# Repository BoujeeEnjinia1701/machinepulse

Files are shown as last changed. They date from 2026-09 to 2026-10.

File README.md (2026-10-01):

# MachinePulse

     

**Area:** Automation · **TRL:** 3 of 9 (proof of concept on paper) · **Value-engineering target:** USD 81 (estimated cost USD 83.50) · **Difficulty:** 2 of 5

A clip-on monitor for older machines: current clamp, vibration and temperature sensors report run time, load and early fault signs from lathes, pumps and compressors that have no electronics of their own.

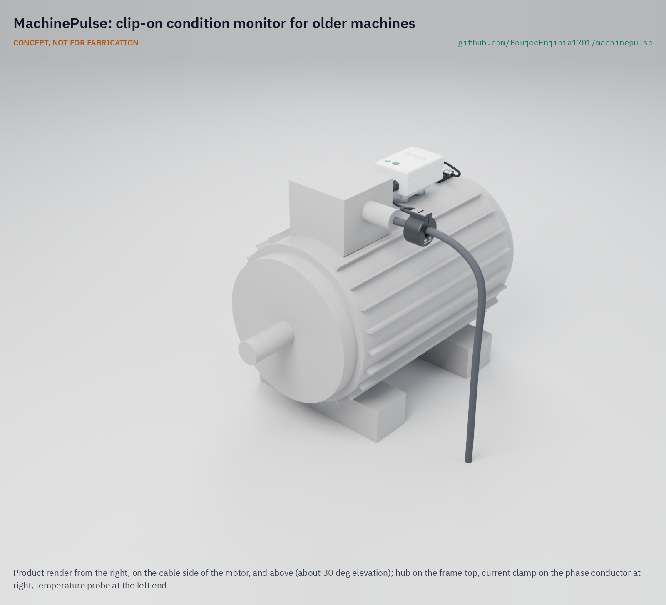
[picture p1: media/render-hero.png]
MachinePulse: clip-on condition monitor for older machines, product render


[Exploded render](media/render-exploded.png) · [Detail render](media/render-detail.png) · [Interactive 3D model](media/viewer.html) · [Concept blueprint (PDF)](media/concept-blueprint.pdf) · [General arrangement MPL-DWG-001 (PDF)](cad/drawings/MPL-DWG-001.pdf) · [Calculations MPL-CAL-001](docs/04-calcs/01-sizing.md) · [Prototype build plan](docs/05-build-plan.md) · [Design decisions](docs/06-design-decisions.md) · [Review note](docs/REVIEW.md)

## Concept rationale

Retrofitting is how most of the world's machines will ever become connected. A lathe, pump or compressor that has run for 30 years can run for many more, but it has no sensors and no controller to read. MachinePulse adds the three measurements that say most about an induction-motor-driven machine: current (is it running, and how hard), vibration (is anything loosening or wearing) and frame temperature (is it working harder than it should). It compares each machine with its own first week of running rather than with fixed alarm levels, because old machines differ too much for generic limits.

It is open and garage-buildable because the owners who most need it run small shops without a maintenance engineer or a budget for vendor platforms. Every part is a stock module, a stock box or a block of aluminium cut with hand tools, the pod never touches the machine's wiring or controls, and the data goes to the lab's TwinKit gateway or any MQTT broker on the shop network, so an owner can inspect and change every step.

## Burning platform

Unplanned stops are expensive, and reactive maintenance makes them more likely. A NIST study of US discrete manufacturing estimated $119.1 billion of losses in 2016 from inadequate maintenance, and found that establishments relying most on reactive maintenance had 3.3 times more downtime and 16 times more defects than those relying on it least ([Thomas and Weiss, NIST, 2020](https://nvlpubs.nist.gov/nistpubs/ams/NIST.AMS.100-34.pdf)). Electric motor-driven systems, the machines MachinePulse watches, account for more than 40 % of global electricity consumption ([IEA](https://www.iea.org/reports/energy-efficiency-policy-opportunities-for-electric-motor-driven-systems)), so knowing when they run and how hard also matters for energy use.

The firms with the least monitoring are the most numerous. Small and medium enterprises are about 90 % of businesses and more than half of employment worldwide ([World Bank](https://www.worldbank.org/en/topic/smefinance)). Condition monitoring products are built and priced for large plants; a monitor costed at about $84 in parts per machine brings the same early warning within reach of a small shop.

## Where it could be used

### By industry

| Industry | Use |
| --- | --- |
| Machine shops and job shops | Run hours and load on lathes, mills and drills; spot a worn spindle bearing or loose belt before it fails |
| Food, grain and rice processing | Watch mills, mixers, conveyors and refrigeration compressors that run long shifts |
| Water and irrigation | Pump run time, load and vibration at borewells, booster stations and irrigation pumps |
| Textiles and garments | Utilization and fault signs on looms, spinning frames and compressors |
| Building services | Fans, air handling units, chillers and pumps in older buildings without a management system |
| Makerspaces, schools and universities | Utilization of shared machines and a hands-on teaching tool for condition monitoring |

### By country or region

| Country or region | Why it matters there |
| --- | --- |
| India | About 63.4 million unincorporated micro, small and medium enterprises employing about 111 million people in the 2015 to 2016 survey ([PIB, Ministry of MSME](https://www.pib.gov.in/Pressreleaseshare.aspx?PRID=1555596)); firms of that size are the ones MachinePulse is costed for |
| Sub-Saharan Africa | The IEA calls reliability of power supply "a major problem in Africa" and expects electric irrigation pumps to replace diesel ([IEA Africa Energy Outlook 2022](https://www.iea.org/reports/africa-energy-outlook-2022/key-findings)); poor supply stresses motors, so early fault signs matter |
| Latin America and the Caribbean | Micro, small and medium firms are 99 % of the industrial fabric but have much lower productivity than large firms ([ECLAC](https://www.cepal.org/en/topics/micro-small-and-medium-sized-enterprises-msmes)) |
| European Union | 99 % of the 32.3 million enterprises are micro or small ([Eurostat, 2024](https://ec.europa.eu/eurostat/web/products-eurostat-news/w/ddn-20241025-1)); a low-cost retrofit suits firms of that size |
| United States | Small firms are 98 % of manufacturers ([SBA Office of Advocacy, 2025](https://advocacy.sba.gov/2025/03/10/facts-about-small-business-manufacturing-statistics-2025/)); of 239,265 manufacturing firms in 2022, all but 4,177 had fewer than 500 employees and about three-quarters had fewer than 20 ([NAM, citing Census Bureau Statistics of U.S. Businesses](https://nam.org/mfgdata/facts-about-manufacturing-expanded/)) |

## What sparked the idea

The idea traces back to a loom. In 1924 Sakichi Toyoda completed the Type G automatic loom, which carried weft-break and warp-break auto-stop devices so that a fault halted the machine instead of spoiling cloth, and which Platt Brothers engineers called "the magic loom" ([Toyota Industries](https://www.toyota-industries.com/company/history/toyoda_sakichi/)). Stopping a machine when something is irregular became the origin of jidoka in the Toyota Production System ([Toyota](https://www.toyota-global.com/company/history_of_toyota/75years/text/taking_on_the_automotive_business/chapter1/section1/item4.html)): a machine that makes its own abnormality visible, so one person can look after many. Most lathes, pumps and compressors in small shops never gained that sense. MachinePulse gives it back to them from the outside, with one difference: it never touches the controls, and only tells a person that a machine has changed so that they can decide what to do.

## Problem

Small factories run machines that have no monitoring, so breakdowns arrive without warning and utilization is unknown.

Full problem statement: [docs/01-problem.md](docs/01-problem.md)

## Concept

A magnetic pod on the motor frame carries a wideband accelerometer on an aluminium sensor block, an ESP32-S3 controller plugged into a hand-wired carrier board, with the plastic box standing clear of the block on nylon stand-offs. A split-core current transformer on one phase conductor and a stainless temperature probe near a bearing plug into it. Every minute the pod reports run state, run time, load current, vibration velocity (10 to 1,000 Hz) and frame temperature over Wi-Fi to a TwinKit gateway or any MQTT broker, and every 15 minutes it sends a spectrum. The TRL 3 calculations (MPL-CAL-001) give a pod of 100 x 68 x 63 mm and about 0.32 kg, 0.42 W from a 5 V adapter, about 1.15 MB of data per day and a vibration noise floor of 0.037 mm/s. Value-engineering target: USD 81. Estimated cost of the constructable design: USD 83.50 (USD 2.50 over the target). High-temperature magnets rated 120 °C let the pod work on frames up to about 110 °C. Not met: fitting the clamp without opening a live enclosure on many machines. At risk: current accuracy at the bottom of the clamp's range, energy per shift, and the magnet mount's resonance near the top of the vibration band (see the review note).

Full design precis: [docs/02-concept.md](docs/02-concept.md) · Requirements: [docs/03-requirements.md](docs/03-requirements.md)

## Key components

- Split-core current transformer, voltage output (SCT-013 family, 5 to 60 A), on one phase
- Wideband MEMS vibration accelerometer (IIS3DWB class) on an aluminium sensor block
- DS18B20 surface temperature probe held on its thermal pad by a made aluminium clip with two high-temperature magnets
- ESP32-S3 controller with Wi-Fi (LoRaWAN variant via FieldNode possible)
- IP54 enclosure on nylon stand-offs over the sensor block, two 32 mm high-temperature pot magnets (rated 120 °C), steel pads for aluminium frames
- Certified 5 V USB power adapter
- TwinKit gateway or any MQTT broker (not in the BOM)

The priced bill of materials is in [bom/bom.csv](bom/bom.csv); the parametric model is `cad/src/model.py`, with STEP files in `cad/step/`.

## Building the prototype

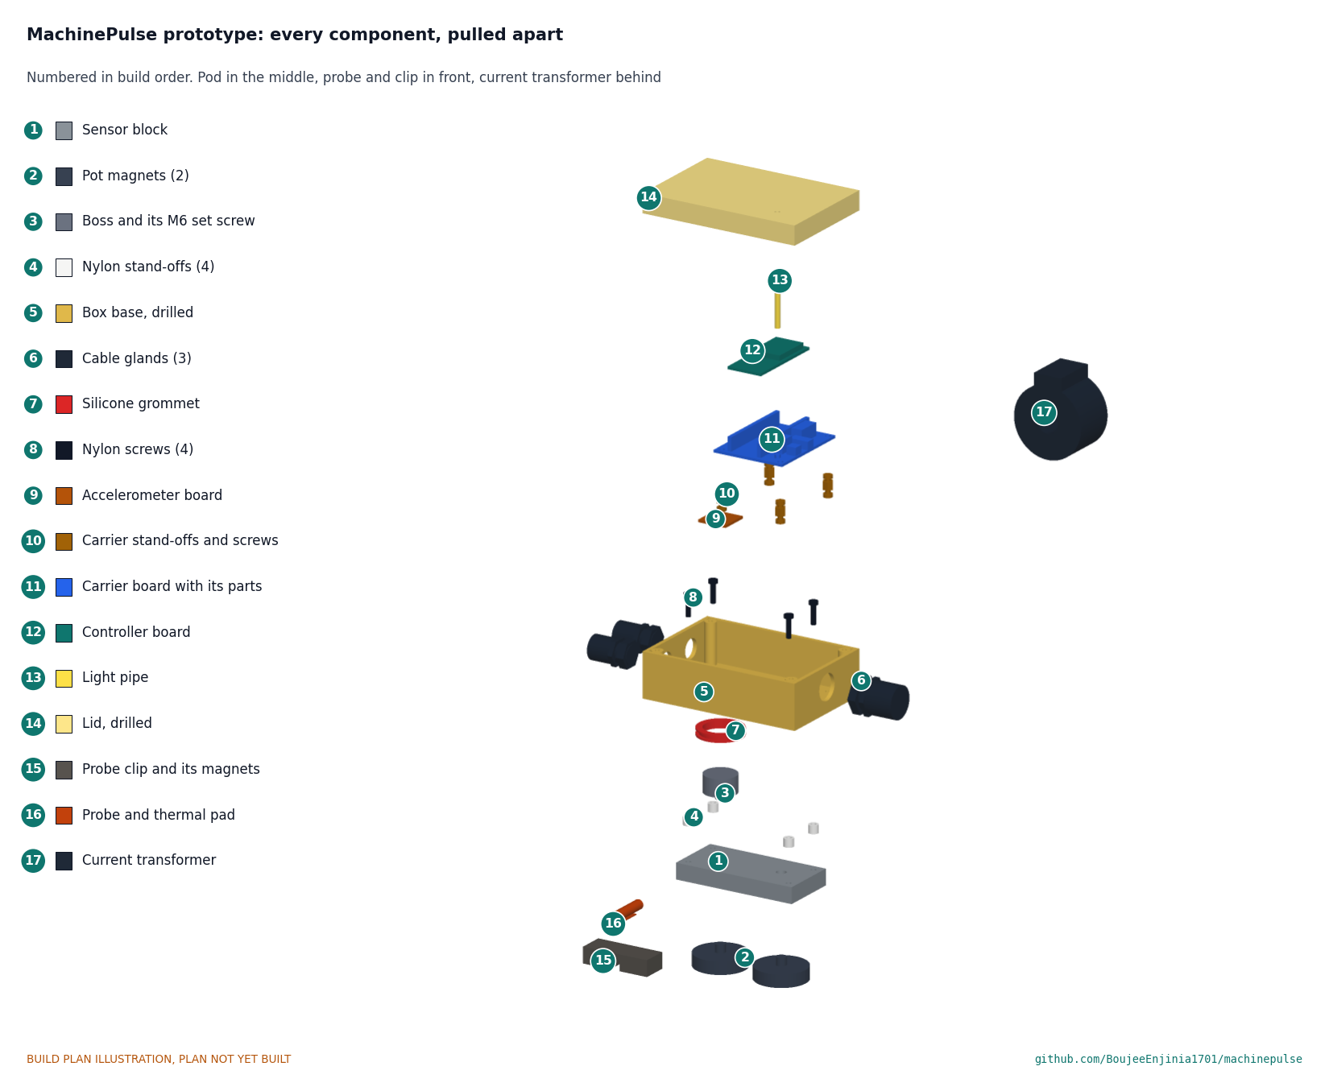
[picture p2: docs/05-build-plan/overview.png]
Every component of the prototype, pulled apart and numbered in build order


The [prototype build plan](docs/05-build-plan.md) shows how to make and fit each of the 17 components, in order, with a making sketch for every made part, close-ups of the joints and a picture for every assembly step. The work is drilling and tapping aluminium plate and bar, drilling a stock box, and hand-wiring a perfboard; every other part is bought. Writing the plan made the design buildable: the boss became a separate piece screwed to the block, the box gained a third gland and a grommet, the boards sit on one carrier on stand-offs, and the probe got a made clip that holds it on the frame (decision record MPL-DDR-003). Decisions still open are in the [design decisions register](docs/06-design-decisions.md). It is a plan, not yet built.

## Safety

> Install current clamps only on insulated conductors with the machine isolated; opening electrical cabinets is for qualified people. Use only voltage-output clamps. Fit the pod and probe only with the machine stopped, keep leads clear of belts, shafts and chucks, and beware of hot frames and strong magnets. MachinePulse is a monitoring aid, never a protective device, and must not be wired into machine controls.

## Repository layout

| Folder | Contents |
| --- | --- |
| `docs/` | Problem, concept, requirements, calculations and design decisions |
| `cad/src/` | build123d Python source, the source of truth for all geometry |
| `cad/step/`, `cad/stl/` | Exported models for FreeCAD, other CAD tools and printing |
| `cad/drawings/` | 2D sketches and dimensioned drawings |
| `bom/` | Bill of materials |
| `electronics/` | KiCad schematics and PCB layouts |
| `firmware/` | Microcontroller code |
| `media/` | Renders, perspectives and photos |
| `build-log/` | Dated prototyping notes |

## Documentation

Controlled documents follow the portfolio [documentation standard](.kit/STANDARDS.md). Each carries a document ID (MPL-PRC-001 for the precis), a version and a revision history. Branded PDFs are built with `python .kit/render.py` and attached to GitHub Releases when a document is tagged, for example `MPL-PRC-001/v1.0`.

## Credits

Designed by Amish Chadha. See [CONTRIBUTORS.md](CONTRIBUTORS.md) for roles. To cite this design, use [CITATION.cff](CITATION.cff) (GitHub shows it as "Cite this repository").

AI assistance (Claude) was used to accelerate concept renders, prototype documentation and first-pass sizing calculations. Design direction and all decisions are Amish Chadha's, recorded in this repository's decision records (`docs/decisions/`).

## Licenses

- **Hardware** (CAD, drawings, BOM, electronics): [CERN-OHL-S v2](LICENSE)
- **Software** (firmware, scripts, notebooks): [MIT](LICENSE-SOFTWARE)

A project of the [Design Molecule](https://designmolecule.com) lab.

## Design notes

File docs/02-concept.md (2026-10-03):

---
doc_id: MPL-PRC-001
title: MachinePulse design precis
project: MachinePulse
doc_type: Design precis
version: "0.7"
status: Draft
date: '2026-10-02'
author: Amish Chadha
license: CERN-OHL-S-2.0
revisions:
- version: "0.1"
  date: '2026-09-25'
  author: Amish Chadha
  change: Initial scaffold
- version: "0.2"
  date: '2026-09-25'
  author: Amish Chadha
  change: Populate to TRL 2 (architecture, first-order numbers, safety, media)
- version: "0.3"
  date: '2026-09-25'
  author: Amish Chadha
  change: TRL 3 update; design choices adopted per MPL-DDR-001; numbers from MPL-CAL-001; stand-offs, CT clamp, 1.50 V bias, +-16 g range, module variant and 3 mm pads added; GA drawing MPL-DWG-001
- version: "0.4"
  date: '2026-09-25'
  author: Amish Chadha
  change: Recommendations accepted by Amish (DDR-002)
- version: "0.5"
  date: '2026-10-01'
  author: Amish Chadha
  change: Constructable design (MPL-DDR-003); components, numbers and GA Rev P4 updated; budget treated as a value-engineering target
- version: "0.6"
  date: '2026-10-02'
  author: Amish Chadha
  change: 'Decisions of 2026-10-02 carried in: R4 as a relative energy trend with kWh as an estimate, co-design partner candidates'
- version: "0.7"
  date: '2026-10-02'
  author: Amish Chadha
  change: 'Firmware and gateway energy rule stated: relative trend, kWh labelled an estimate (decision of 2026-10-02)'
---

# MachinePulse design precis

## Summary

MachinePulse is a small magnetic pod that clips onto an old machine's motor frame, plus a split-core current transformer (CT) on one phase conductor and a surface temperature probe. Every minute it reports run state, run time, load current, vibration velocity and frame temperature to a TwinKit gateway or any MQTT broker on the shop network, and every 15 minutes it sends a vibration spectrum. The TRL 3 calculation note MPL-CAL-001 finds that stock modules, a hand-made aluminium sensor block and a stock box meet twelve of the seventeen requirements. Value-engineering target: USD 81. Estimated cost of the constructable design: USD 83.50 (USD 2.50 over the target). One requirement is not met: fitting the CT without opening a live enclosure on many machines (R10). Three are at risk: current accuracy at the bottom of the CT range (R3), energy per shift (R4) and the magnet mount's resonance inside the vibration band (R5). Writing the prototype build plan (MPL-BLD-001) made the design constructable without changing what it does: the boss is a separate piece screwed to the block, the boards sit on one carrier on stand-offs, each lead has its own gland, a grommet seals the boss and a made clip holds the probe on the frame (MPL-DDR-003, open for Amish's review). The design choices below were decided by Amish on 2026-09-25, going with the recommendations (MPL-DDR-001 and MPL-DDR-002). That decision added high-temperature pot magnets rated 120 °C, which clear hot frames to about 110 °C, and raised the budget from $80 to $81 to pay for them.

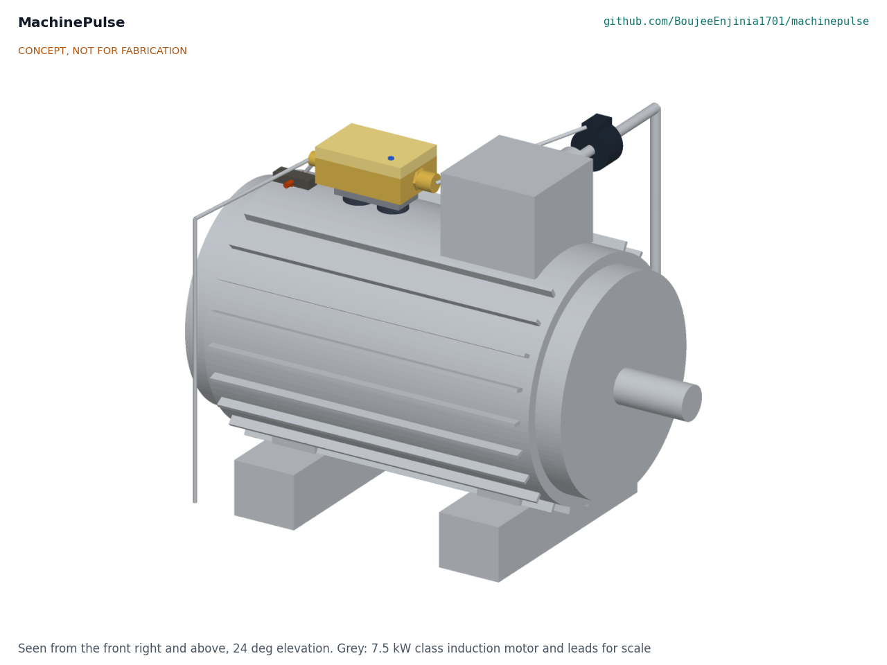
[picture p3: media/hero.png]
Hero render


Figure 1. MachinePulse on a 7.5 kW class induction motor (grey, for scale), generated from the parametric model `cad/src/model.py`. Concept, not for fabrication.

## How it works

1. **Sense current.** A voltage-output split-core CT (YHDC SCT-013 family, 5 to 60 A variants) clamps one insulated single-core phase conductor. The carrier board's interface circuit biases its output at 1.50 V, so a full-range signal stays inside the ADC's linear window, and clamps the input against starting current. The pod samples at 2 kHz and computes RMS current every second.
2. **Sense vibration.** A wideband MEMS accelerometer (IIS3DWB class, dc to 6 kHz, 75 µg/√Hz noise density, 1.1 mA ([ST](https://www.st.com/en/mems-and-sensors/iis3dwb.html))), set to ±16 g, sits on a 20 mm round boss of an aluminium sensor block, directly above one of two pot magnets. The magnets pull the block onto the frame, so vibration reaches the sensor through metal, not through the plastic box.
3. **Sense temperature.** A DS18B20 probe in a stainless sleeve sits in a small magnetic clip with a thermal pad on the frame near a bearing.
4. **Summarize on the pod.** Every 60 s the ESP32-S3 controller records a 4 s vibration burst, decimates it from 26.7 kHz to 3.33 kHz as it reads the sensor, and computes velocity RMS over 10 to 1,000 Hz (the ISO 20816-1 band ([ISO](https://www.iso.org/standard/63180.html))), acceleration RMS, crest factor and the amplitudes at 1x and 2x running speed. It adds run state, run seconds, mean and peak current, starts, and temperature.
5. **Send and store.** The summary goes over Wi-Fi to an MQTT broker, by default on the TwinKit gateway. If the network is down, summaries queue in flash for about 14 days; spectra are kept only while space allows.
6. **Compare with the machine's own baseline.** During the first week of running, the gateway software learns a baseline per load band. Afterward it flags a change, for example vibration velocity above twice its baseline or temperature rise above baseline at the same load, for a person to inspect. Energy per shift uses a power factor curve built from the nameplate and the measured no-load current, and is shown as a relative trend against the machine's own baseline, with any kWh figure marked as an estimate (decided by Amish, 2026-10-02). Rule for the firmware and gateway notes: the pod reports raw current and load band, and the gateway software shows energy only as a relative trend against the machine's baseline; any kWh figure it shows carries the label "estimate". Both are TRL 4 work and are not written here.

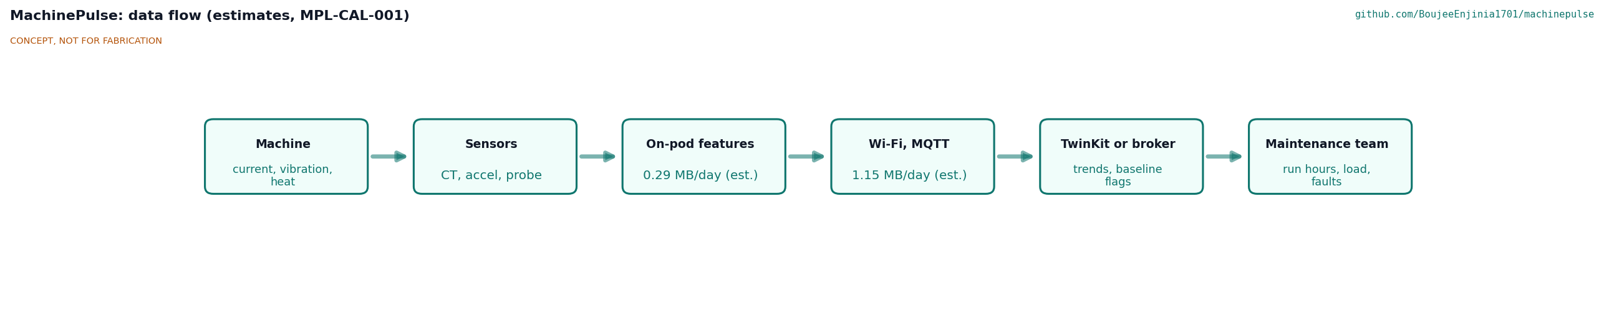
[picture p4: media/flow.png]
Data flow


Figure 2. Data flow from machine to maintenance team. Values are estimates from MPL-CAL-001.

## Main components

Table 1. Main components. Numbers match the BOM and Figure 3.

| # | Component | Choice | Notes |
| --- | --- | --- | --- |
| 1, 2 | Enclosure | Stock IP54 ABS box, 100 x 68 x 40 mm, with one M16 IP68 gland (CT) and two M12 IP68 glands (probe, power), a sealed light pipe and a 24 mm hole for the boss | Stock box keeps cost low (D7); one cable per gland (MPL-DDR-003) |
| 3 | Controller | ESP32-S3 module board, 8 MB flash, no octal PSRAM, USB-C, Wi-Fi and BLE | Module rated to 85 °C; PSRAM variants are rated to 65 °C (D1) |
| 4 | Accelerometer | IIS3DWB-class 3-axis MEMS on an 18 x 18 mm adapter board, ±16 g | ADXL345-class fallback misses R6 (D3) |
| 5 | Sensor block and boss | 76 x 36 x 10 mm aluminium plate; a separate 20 mm round boss 11 mm high on an M6 set screw over magnet 1, through the box floor | Carries magnets and sensor; stiff path to the frame; no lathe needed (MPL-DDR-003) |
| 6 | Magnets | Two 32 mm high-temperature neodymium pot magnets, rated 120 °C, with M6 studs, 40 mm apart | Standard 80 °C grade would limit hot frames to about 81 °C; the 120 °C grade meets R12 (MPL-DDR-002, N1) |
| 7 | Carrier board | Perfboard 45 x 56 mm on four stand-offs, with 1.50 V CT bias and filter, series resistor and clamp diodes, 3.5 mm jack, 5 V and probe terminals, LED, button and header sockets for the controller | No custom PCB for the first build |
| 8 | Current transformer | SCT-013 family, voltage output, 13 mm aperture, 5 to 60 A chosen per machine (30 A for the design case) | Voltage output has an internal burden, so it is never open-circuited (D4) |
| 9, 14 | Temperature probe and clip | DS18B20 in stainless sleeve on a thermal pad, held against the frame by a made aluminium clip with two high-temperature disc magnets | The clip presses the sleeve on its pad (MPL-DDR-003) |
| 10 | Power | Certified 5 V 1 A USB-C adapter and 2 m cable | Low voltage only in the pod (D2) |
| 11 | Steel pads | 35 mm x 3 mm steel discs with epoxy, for aluminium frames | 3 mm keeps about 75 % of the pull |
| 12, 13 | Hardware and stand-offs | Screws, set screw, silicone grommet round the boss, carrier stand-offs; four 6 x 5 mm nylon stand-offs | The stand-offs are the thermal break studied under D7 |

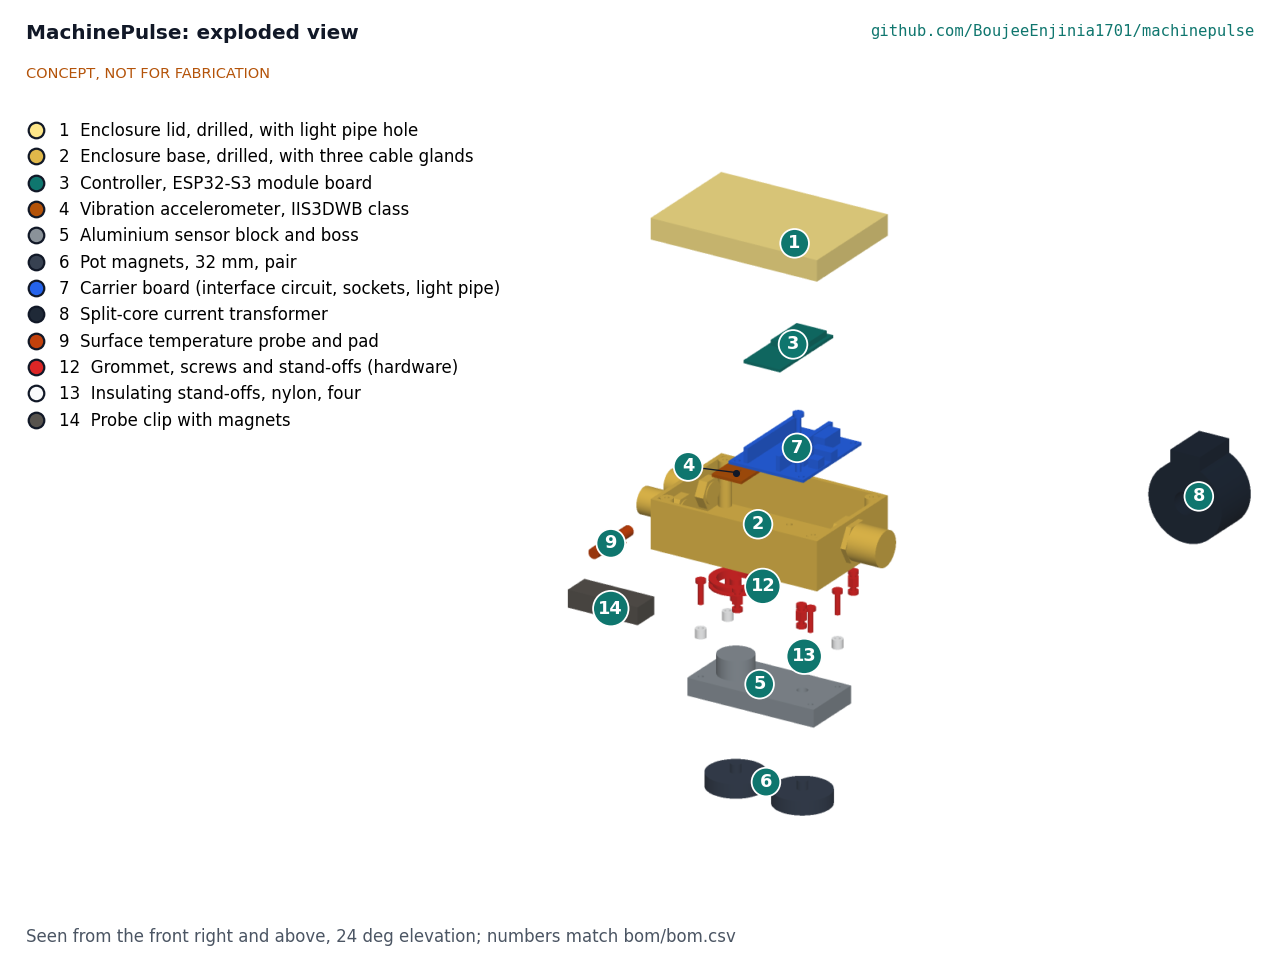
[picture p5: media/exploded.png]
Exploded view


Figure 3. Exploded view with BOM numbers.

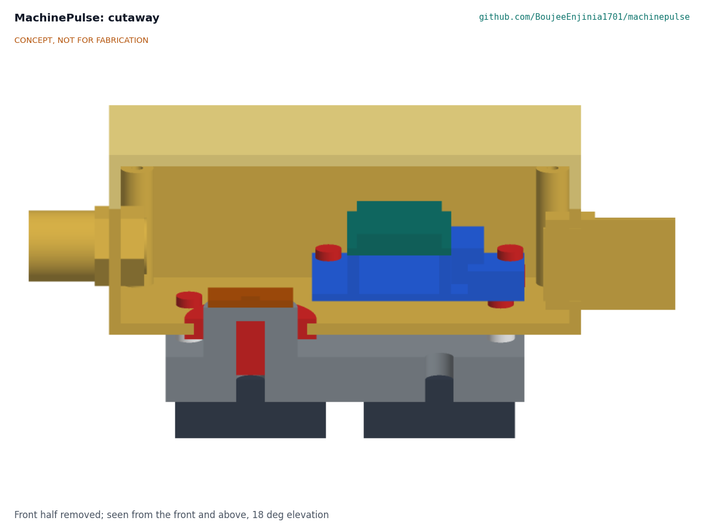
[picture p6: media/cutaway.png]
Cutaway


Figure 4. Cutaway through the accelerometer: the sensor sits on the boss of the aluminium block, which sits on the magnets; the box stands 5 mm clear of the block on nylon stand-offs and carries no vibration path.

The general arrangement drawing [MPL-DWG-001](../cad/drawings/MPL-DWG-001.pdf) (Rev P4, 1:1) gives the main dimensions: pod 100 x 68 x 63 mm high from the magnet face, 137 mm over the glands.

## Key numbers

All values come from MPL-CAL-001 and are estimates for a paper proof of concept.

Table 2. Key numbers.

| Quantity | Value | Requirement |
| --- | --- | --- |
| Design motor full-load current | 14.6 A, 49 % of a 30 A CT | Sizes the CT |
| Current accuracy | 2.1 % RSS at the design point; 3.6 % RSS and 7.0 % worst case at 10 % of range | R3 at risk |
| Energy per shift | 8.5 % RSS with a power factor curve; 26 % with a fixed power factor | R4 met by design as restated: a relative energy trend, kWh shown as an estimate |
| Velocity noise floor | 0.037 mm/s RMS, 10 to 1,000 Hz | R6 met |
| Spectrum resolution | 0.407 Hz bins (8,192 points at 3,333 Hz) | R7 met |
| Magnet mount resonance | About 892 Hz on a painted curved frame, 1,783 Hz flat | R5 at risk |
| Pod mass | About 0.32 kg | |
| Magnet holding | Slip margin 3.0 on a painted curved frame; pull-off 12.2 | R11 met |
| Probe error | 1.56 K at 80 °C, 1.69 K at 85 °C; 3.59 K at 100 °C | R8 met (restated target) |
| Hot frame, 40 °C air | Floor 53.9 °C and module about 58.9 °C at an 80 °C frame; accelerometer limit at a 109.6 °C frame, 120 °C magnets at 122.7 °C | R12 met |
| Power | 0.42 W from 5 V; 0.61 W and 5.3 kWh a year at the wall | |
| Data | 1.15 MB per day; worst delivery 66 s | R9 met |
| Offline store | 13.9 days of summaries | R15 met |
| Parts cost | $83.50 against an $81 value-engineering target | R16 $2.50 over the target |

## Key design choices

Decided by Amish, 2026-09-25: go with recommendation (MPL-DDR-001, MPL-DDR-002).

- **Stiff sensor path, plastic box for protection only (D7).** The accelerometer sits on the aluminium block's boss above a magnet, and the block sits on the magnets. The box rides on four nylon stand-offs 5 mm above the block, which keeps its floor 13 K cooler on a hot frame. The mount still resonates inside the upper vibration band on curved frames (R5).
- **Features on the pod, spectra on a slow schedule (D10).** Summaries every minute and a spectrum every 15 minutes come to about 1.15 MB a day, so one gateway can serve many machines. Raw bursts can be captured on demand for diagnosis.
- **One CT on one phase (D4).** Enough for run state, run hours and relative load, within budget. With a power factor curve the energy estimate is at risk rather than not met; a voltage reference or three CTs would cost $10 to $20 more. Decided by Amish, 2026-10-02: R4 is a relative energy trend for the first build, and any kWh figure is reported as an estimate; the voltage reference stays an option for sites that need absolute energy.
- **Wi-Fi first (D1).** Small workshops usually have Wi-Fi, and 7.4 kB spectra are far too large for a LoRaWAN duty cycle. A summaries-only LoRaWAN variant could reuse the FieldNode radio core later.
- **High-temperature magnets (MPL-DDR-002, N1).** The magnets sit within about 2 K of the frame, so the standard 80 °C grade had no margin on an 80 °C frame. Pot magnets rated 120 °C cost about $1.00 more for the pair and move the pod's hot-frame limit to about 110 °C, set by the accelerometer.
- **Mains-powered adapter, no battery (D2).** A certified 5 V adapter avoids lithium cells on a hot, vibrating frame.
- **Baseline, not fixed limits (D5).** Old machines differ too much for fixed alarm levels to be useful at first. Each machine is compared with its own first week, by load band, and flags go to a person.
- **Data stays local (D6).** MQTT to the TwinKit gateway, where the twin shows readings on the machine's model; any other broker works too.

## Relation to other lab projects

- **TwinKit** is the default data home: its gateway accepts MQTT over Ethernet or Wi-Fi, stores data offline and shows readings against a model (TwinKit REQ R2). MachinePulse adds about 1.15 MB a day per machine, small against TwinKit's storage budget. MachinePulse is a natural first "small manufacturing" twin for it.
- **FieldNode** provides a LoRaWAN radio core if a summaries-only variant is wanted for sites without Wi-Fi. Only summaries would fit its 20-byte class payloads; spectra would not.
- **CalRig** can check the temperature probe against a reference before deployment. Vibration calibration needs a separate reference (a shaker or a known accelerometer) that CalRig does not provide.

## Safety

> **Safety:** Mains voltage. The CT goes around a live conductor. Fit it only with the machine isolated and locked off, only around a single insulated conductor, and have a qualified person open any terminal box or panel. Use only voltage-output CTs with an internal burden: a current-output CT left open-circuited on a live conductor can produce dangerous voltages ([OpenEnergyMonitor](https://docs.openenergymonitor.org/electricity-monitoring/ct-sensors/introduction.html)).

> **Safety:** Moving machinery. Fit and remove the pod and probe only when the machine is stopped and isolated. Mount on stationary frames, never on guards that open or on moving parts. Route leads away from belts, shafts, chucks and fans, and secure them with ties.

> **Safety:** Hot surfaces and magnets. Motor frames and compressor heads can be hot enough to burn; the sensor block runs within a few kelvin of the frame. Strong neodymium magnets can pinch fingers and snap together; keep them away from pacemakers and magnetic media.

> **Safety:** Power supply. Use only a certified 5 V adapter with the local safety mark. The pod contains no mains wiring and no lithium cells.

MachinePulse is a monitoring aid. It is not a protective device, it must never be wired into machine controls, and it does not replace overload relays, guards or scheduled maintenance.

## Open questions

- Co-design partner for alerts and dashboard (MPL-DDR-001, O1): the makerspace pilot already decided, with its shop lead deciding what "changed" should mean, and the maintenance person of one small production machine shop as a second voice (decided by Amish, 2026-10-02; the first candidates to approach, not agreed).
- Measured values for the assumptions MPL-CAL-001 rests on: ESP32-S3 ADC residual error, magnet contact stiffness and pull on painted frames. Amish decided to keep the R3 and R5 targets and to measure the ADC residual and the mount resonance first, with a flat steel saddle for curved frames as the option to consider (MPL-DDR-002, N3). These need bench work, which belongs to TRL 4 and is on hold.

Concept media: [blueprint sheet](../media/concept-blueprint.pdf), [interactive 3D model](../media/viewer.html).

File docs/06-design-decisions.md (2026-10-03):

---
doc_id: MPL-DEC-001
title: MachinePulse design decisions register
project: MachinePulse
doc_type: Design decisions register
version: "0.3"
status: Draft
date: '2026-10-02'
author: Amish Chadha
license: CERN-OHL-S-2.0
revisions:
- version: "0.1"
  date: '2026-10-01'
  author: Amish Chadha
  change: Register opened with the build plan; open decisions from MPL-DDR-001 to 003 and the review note
- version: "0.2"
  date: '2026-10-02'
  author: Amish Chadha
  change: 'Amish approved the recommendations for all six open decisions (2026-10-02); MPL-DDR-003 accepted; moved to decisions made'
- version: "0.3"
  date: '2026-10-02'
  author: Amish Chadha
  change: 'Value engineering: saving that reused an existing USB charger removed (conflicts with the certified adapter, D2, and R17)'
---

# MachinePulse design decisions register

Every design decision still to be made, and every decision made, in one place. Each decision is argued in full in its decision record under `docs/decisions/`; this register is the index Amish works from. The build plan (`docs/05-build-plan.md`) describes the design as it stands and does not list open decisions.

## Open decisions

None. All open decisions were decided on 2026-10-02.

## To confirm when parts are bought

| # | What to confirm | Why it matters | Source |
| --- | --- | --- | --- |
| 1 | The current transformer's 3.5 mm plug passes the M16 gland's seal | Otherwise the plug must be fitted after the lead is through, or a larger gland used | MPL-DDR-003, P6 |
| 2 | The pot magnets' M6 studs are at least 5 mm long and can be trimmed | The stud and the set screw share the block's left hole | MPL-DDR-003, P1, P2 |
| 3 | The silicone grommet fits a 24 mm hole in 2.5 mm panel and grips a 20 mm boss | It seals the floor and must stay soft so it carries little vibration or heat | MPL-DDR-003, P4 |
| 4 | The stock box: four corner pillars about 7 mm across, 2.5 mm walls, continuous use at 70 °C | The gland heights, the carrier position and the thermal model assume them | MPL-DDR-003, P7; MPL-CAL-001, G |
| 5 | The controller board: about 22 x 51 mm, two 20-pin rows 19.4 mm apart, no octal PSRAM | The carrier's header sockets are spaced for it | MPL-DDR-003, P5; MPL-CAL-001, G4 |
| 6 | The light pipe's hole size (3.2 mm clearance or 3.0 mm press fit) and its length (about 29 mm) | The lid hole and the LED position follow from it | MPL-DDR-003, P10 |
| 7 | The probe clip's disc magnets are rated 150 °C or more | The clip sits on frames up to 100 °C | MPL-DDR-003, P9 |
| 8 | The accelerometer breakout's size (about 18 x 18 mm) and that its back can be bonded flat | It is bonded to the 20 mm boss top | MPL-DDR-003, P8 |

## Value engineering

Value-engineering target: USD 81 (a hypothetical control target, not a limit). Estimated cost of the constructable design: USD 83.50 (USD 2.50 over the target). Main cost drivers and savings worth trying:

- The largest lines are the accelerometer (USD 15, the least certain price), the current transformer (USD 10), the controller (USD 9), the box with its glands (USD 9.50) and the power adapter (USD 8).
- Making the design constructable added USD 2.50: the third gland and the larger M16 gland (USD 0.50), the carrier board's sockets, terminals and light pipe (USD 1.00), the made probe clip with its magnets in place of a bought clip (USD 0.50 net) and the grommet, set screw and carrier fixings (USD 0.50).
- Savings worth trying: the steel pads (USD 4 for two) are needed only on aluminium-framed machines and could be left out of the standard kit; the accelerometer price should be checked against current breakout boards; an adapter and cable bought in quantity would cover the gap; a certified adapter is kept for every kit (D2, R17).

## Decisions made

| Date | Decision | Decided by | Record |
| --- | --- | --- | --- |
| 2026-09-25 | TRL 2 review items D1 to D10: Wi-Fi first, certified 5 V adapter, IIS3DWB-class sensor, one CT on one phase, first-week baseline alerts, TwinKit or any MQTT broker, stock ABS box on 5 mm nylon stand-offs, makerspace pilot, no budget change, features every minute and a spectrum every 15 minutes | Amish: "i accept all your recommendations, go with them across all repos." | MPL-DDR-001, MPL-DDR-002 |
| 2026-09-25 | N1 high-temperature pot magnets rated 120 °C; N2 R8 restated (2 °C to 85 °C, 4 °C from 85 to 100 °C); N3 keep the R3 and R5 targets and measure first at TRL 4 | Amish, same instruction | MPL-DDR-002 |
| 2026-09-30 | Build plans are written in the approved format, and the design is made physically buildable as the pictures are drawn | Amish: "If you are realising that the design cannot be built as per concept - fix the design assumptions to match and be physically feasible as you draw the illustrations." | MPL-DDR-003 (changes accepted on 2026-10-02, below) |
| 2026-09-30 | Open decisions are kept in this register, not in the build plan | Amish: "don't log outstanding decisions in this build plan - that is not the place for it." | This register |
| 2026-10-01 | `budget_usd` is a value-engineering target, not a limit | Amish: "the budgets are a hypothethical control target to ensure we are thinking along a value engineering lens." | This register, Value engineering |
| 2026-10-02 | Design for construction accepted: all ten changes of Table 1 and their knock-on changes, as made | Amish: "i approve your recommendations for all 555 open decisions." | MPL-DDR-003, Table 1 |
| 2026-10-02 | Power entry: (a) for the prototype, the cut USB cable through an M12 gland to a screw terminal | Amish: "i approve your recommendations for all 555 open decisions." | MPL-DDR-003, A1 |
| 2026-10-02 | Status button: (a) for the prototype, on the carrier board and pressed with the lid off; a sealed lid button only if field pairing shows it is needed | Amish: "i approve your recommendations for all 555 open decisions." | MPL-DDR-003, A2; review note 2026-09-26, item 1 |
| 2026-10-02 | R4: restated as a relative energy trend for the first build, with any kWh figure reported as an estimate; the voltage reference (c) stays an option for sites that need absolute energy | Amish: "i approve your recommendations for all 555 open decisions." | MPL-DDR-001, O2; MPL-DDR-002 |
| 2026-10-02 | Co-design partner for alerts and dashboard: the makerspace pilot already decided, with its shop lead deciding what "changed" should mean, and the maintenance person of one small production machine shop as a second voice (first candidate type to approach, not agreed) | Amish: "i approve your recommendations for all 555 open decisions." | MPL-DDR-001, O1 |
| 2026-10-02 | Enclosure colour: a single-colour stock box is bought; two-tone stays a later option | Amish: "i approve your recommendations for all 555 open decisions." | Review note 2026-09-26, item 2 |

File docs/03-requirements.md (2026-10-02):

---
doc_id: MPL-REQ-001
title: MachinePulse requirements
project: MachinePulse
doc_type: Requirements
version: "0.6"
status: Draft
date: '2026-10-02'
author: Amish Chadha
license: CERN-OHL-S-2.0
revisions:
- version: "0.1"
  date: '2026-09-25'
  author: Amish Chadha
  change: Initial scaffold
- version: "0.2"
  date: '2026-09-25'
  author: Amish Chadha
  change: First measurable requirements for TRL 2, with concept status
- version: "0.3"
  date: '2026-09-25'
  author: Amish Chadha
  change: Status from MPL-CAL-001 for TRL 3; decisions from MPL-DDR-001 reflected; targets unchanged
- version: "0.4"
  date: '2026-09-25'
  author: Amish Chadha
  change: Recommendations accepted by Amish (DDR-002)
- version: "0.5"
  date: '2026-10-01'
  author: Amish Chadha
  change: Status from MPL-CAL-001 v0.3 for the constructable design (MPL-DDR-003); R16 reported against the value-engineering target; targets unchanged
- version: "0.6"
  date: '2026-10-02'
  author: Amish Chadha
  change: 'R4 restated by Amish on 2026-10-02 as a relative energy trend per shift, kWh reported as an estimate; met by design as restated'
---

# MachinePulse requirements

These are the MachinePulse requirements with their status from the TRL 3 calculation note MPL-CAL-001 v0.3, which checks the constructable design of MPL-DDR-003. The design they are checked against follows the decisions Amish made on 2026-09-25 (MPL-DDR-001 and MPL-DDR-002): Wi-Fi, USB adapter, IIS3DWB-class sensor, one CT, baseline alerts, TwinKit or any broker, stock box with stand-offs and high-temperature magnets. Two targets change in v0.4 under MPL-DDR-002: R8 is restated with a wider tolerance above 85 °C (N2), and R16 follows the budget raised to $81 for the high-temperature magnets (N1). R3 and R5 keep their targets (N3). One requirement is not met (R10), two are at risk (R3 and R5), nine are met by calculation and four by design. R16 is reported against the value-engineering target: the constructable design is estimated at $83.50, $2.50 over the $81 target. R4 was restated by Amish on 2026-10-02 as a relative energy trend for the first build, with any kWh figure reported as an estimate (MPL-DDR-001, O2), so it moves from at risk to met by design.

Table 1. Requirements and TRL 3 status.

| ID | Requirement | Target | Status (MPL-CAL-001) | Verification after TRL 3 |
| --- | --- | --- | --- | --- |
| R1 | Detect run state | Off, idle and running classified from current, with 1 s time resolution | Met by calculation: 1 s RMS windows of 2,000 samples; zero-current reading 0.07 A against a 0.5 A threshold | Bench test on a motor |
| R2 | Log run time | Run hours per machine, error within 1 % over a week | Met by calculation: worst case 1.00 % on 100 s runs, 0.17 % on 10 min runs | Comparison with a timed log |
| R3 | Measure load current | Within 5 % of reading from 10 % to 100 % of CT range, after a two-point calibration | At risk: RSS 3.6 % at 10 % of range and 2.1 % at the design point, but 7.0 % worst case at 10 %; ESP32-S3 ADC residual assumed | Comparison with a clamp meter |
| R4 | Estimate energy per shift | A relative energy trend per shift for the first build, with any kWh figure reported as an estimate (restated by Amish, 2026-10-02, from "within 10 % of a reference meter"; a voltage reference stays an option for sites that need absolute energy) | Met by design as restated: one CT with a load-dependent power factor curve gives the trend; as an absolute figure the estimate is 8.5 % RSS, 16.0 % worst case (26 % with a fixed power factor) | Comparison with a reference meter |
| R5 | Measure vibration | Velocity RMS over 10 to 1,000 Hz (ISO 20816-1 band), three axes | At risk: sensor covers the band, but the magnet mount resonates at about 892 Hz on a painted curved frame (1,783 Hz flat), so readings are 10 % high from about 267 Hz | Mounted shaker check |
| R6 | Low vibration noise floor | 0.1 mm/s RMS or better, 10 to 1,000 Hz | Met by calculation: 0.037 mm/s (ADXL345-class fallback 0.20 mm/s would miss it) | Mounted noise test |
| R7 | Resolve running-speed peaks | Spectrum bin 0.5 Hz or finer up to 1 kHz | Met by calculation: 0.407 Hz bins | Spectrum of a known tone |
| R8 | Measure frame temperature | Within 2 °C of the surface from 0 to 85 °C, and within 4 °C from 85 to 100 °C (restated per MPL-DDR-002, N2; was within 2 °C from 0 to 100 °C) | Met by calculation: 1.56 K at 80 °C, 1.69 K at 85 °C and 3.59 K at 100 °C | Comparison with a thermocouple |
| R9 | Report often enough | One summary per minute; spectrum every 15 min; delivered within 2 min | Met by calculation: 1.15 MB per day; 66 s worst delivery | Network log |
| R10 | Install without opening live enclosures | Pod and probe in 10 min without tools; CT on an accessible insulated conductor | **Not met for many machines.** Pod and probe need no tools; the CT needs a single insulated conductor, often only inside a terminal box or panel opened by a qualified person | Design review with the pilot site |
| R11 | Stay attached | No slip under 5 g peak on a painted cast frame; option for aluminium frames | Met by calculation: slip margin 3.0 on a curved painted frame (2.8 at 80 °C); 3 mm steel pads for aluminium frames, margin 7.0 | Pull and shake tests |
| R12 | Tolerate hot frames | Operate on frames up to 80 °C in 40 °C ambient | Met by calculation: with 5 mm stand-offs the box floor reaches 53.9 °C and the module about 58.9 °C; the 120 °C magnets (MPL-DDR-002, N1) reach their limit at a 122.7 °C frame, so the accelerometer now sets the limit at 109.6 °C (N-grade magnets would have stopped at 81.3 °C) | Hot-plate test |
| R13 | Workshop protection | IP54 or better for the pod | Met by design: IP54 box, three IP68 glands with one cable each, silicone grommet round the sensor boss, sealed light pipe | IP test |
| R14 | Keep data local | Works with TwinKit or any MQTT broker on the local network; no cloud account | Met by design | Configuration check |
| R15 | Store data when the network is down | 7 days of summaries on the pod | Met by calculation: 13.9 days of summaries in 4 MB (4.0 days with spectra) | Offline run |
| R16 | Low cost and buildable | Parts $81 or less per machine (was $80; MPL-DDR-002, N1); hand tools and a drill press; no custom PCB | Over the value-engineering target by $2.50: estimated $83.50 against the $81 target (indicative prices); hand tools, a drill press and perfboard, no custom PCB | Supplier quotes |
| R17 | Safe by design | Low voltage in the pod; certified 5 V adapter; voltage-output CT only; no connection to machine controls | Met by design; the CT input is now clamped against starting current | Design review |

## Assumptions

- Target machines are driven by induction motors from 0.37 kW to 15 kW, running at 50 or 60 Hz, at speeds from about 700 to 3,600 rpm.
- The CT is chosen per machine from the 5 to 60 A voltage-output range so that normal load sits above about 30 % of its range.
- A single CT on one phase is enough to judge run state and relative load on a three-phase motor whose phases are balanced; it is not an energy meter. Energy uses a power factor curve built from the nameplate and the measured no-load current.
- The pod is mounted on a clean flat or gently curved area of the frame or bearing housing, near the non-drive or drive-end bearing, with paint thickness under about 0.2 mm.
- The workshop has Wi-Fi coverage at the machine, or a TwinKit gateway nearby.

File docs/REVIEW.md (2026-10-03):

# Review note: MachinePulse

## Session 2026-09-25: /populate to a strong TRL 2 (batch run)

### What was done

- `docs/01-problem.md` (MPL-PRB-001 v0.2): problem, cited prior work (NIST maintenance studies, ISO 20816-1, OpenEnergyMonitor, vendor platforms), users and context, constraints, out of scope, safety context, open questions.
- `docs/03-requirements.md` (MPL-REQ-001 v0.2): 17 measurable requirements (R1 to R17) with targets, concept status and planned verification.
- `docs/02-concept.md` (MPL-PRC-001 v0.2): how it works, main components, first-order numbers with assumptions, design choices, relation to TwinKit, FieldNode and CalRig, safety, open questions.
- `cad/src/concept_media.py`: massing model of the pod (lid, base, controller, accelerometer, aluminium sensor block, magnets, interface board), current transformer and temperature probe, each with a BOM number, on a 7.5 kW class induction motor shown in grey for scale. The scene is shifted so the pod sits near the origin, because the kit's cutaway cutter is centered there.
- `media/`: `hero.png`, `concept-blueprint.png`, `.pdf` and `.svg`, `model.glb` and `viewer.html`, `exploded.png` (callouts 1 to 9 match the BOM), `cutaway.png` (section through the accelerometer and sensor block) and `flow.png` (data flow, values marked as estimates).
- `bom/bom.csv` (12 lines, indicative USD prices, numbered to match the exploded view) and `bom/bom-notes.md`.
- `README.md`: hero image and links line, concept rationale, burning platform with cited figures, use tables by industry and by region, origin and trigger, updated concept, components and safety.
- `docs/pdf/`: branded PDFs of the three controlled documents.
- `project.yaml`: unchanged. The pitch and problem still match the concept and the numbers found.

### Key results (estimates, to be checked at TRL 3)

| Quantity | Estimate | Requirement |
| --- | --- | --- |
| Parts cost | about $79 | R16 met, $1 margin |
| Pod size and mass | 100 x 68 x 58 mm, about 0.35 kg | |
| Power | about 0.5 W from 5 V | |
| Vibration band and noise | 10 to 1,000 Hz, about 0.04 mm/s RMS | R5, R6 met on datasheet |
| Spectrum resolution | 0.41 Hz | R7 met |
| Current accuracy | about 3 % of reading | R3 met on paper |
| Energy accuracy | about 20 % | R4 **not met** |
| Data volume and offline store | about 0.4 MB per day, about 10 days | R9, R15 met |
| Frame temperature limit | about 60 °C | R12 **not met** (target 80 °C) |

**Requirements not met:** R4 (energy within 10 %: one CT with assumed voltage and power factor gives about 20 %), R10 (fitting the CT without opening a live enclosure: not possible on many machines, which need a qualified person and isolation), R12 (frames up to 80 °C: the stock ABS box and module limit the concept to about 60 °C). **Unverified with known risk:** R6 (magnet mount effect on noise and bandwidth), R8 (probe contact error), R11 (magnet pull on painted curved frames).

### Proposed, awaiting Amish

1. **Radio.** Options: Wi-Fi on ESP32-S3; LoRaWAN summaries only via the FieldNode radio core; both. Recommendation: Wi-Fi first, because spectra do not fit a LoRaWAN duty cycle and small shops usually have Wi-Fi. **Decided by Amish, 2026-09-25: go with recommendation** (MPL-DDR-002).
2. **Power.** Options: certified 5 V USB adapter; Li-ion battery; energy harvesting from the CT. Recommendation: adapter, which avoids lithium cells on hot, vibrating frames. **Decided by Amish, 2026-09-25: go with recommendation** (MPL-DDR-002).
3. **Accelerometer.** Options: IIS3DWB class (about $15, low noise, dc to 6 kHz); ADXL345 class (about $6, noisier, about 1.6 kHz). Recommendation: IIS3DWB class; keep ADXL345 as a documented fallback. **Decided by Amish, 2026-09-25: go with recommendation** (MPL-DDR-002).
4. **Current sensing.** Options: one CT on one phase (within budget); three CTs (about $20 more, over budget); one CT plus a voltage reference. Recommendation: one CT, and accept that R4 is not met in the first build, or relax R4 to "relative energy trend". **One CT: decided by Amish, 2026-09-25: go with recommendation.** The R4 treatment offered two courses without choosing and stays **Proposed, awaiting Amish** (MPL-DDR-001, O2).
5. **Alert logic.** Baseline learned over the first week per load band, flags at twice baseline vibration or a temperature rise above baseline, sent to a person. Recommendation: adopt for the first build; fixed ISO 20816 zones as a later option. **Decided by Amish, 2026-09-25: go with recommendation** (MPL-DDR-002).
6. **Data home.** Options: TwinKit gateway; any MQTT broker; a cloud service. Recommendation: TwinKit gateway with any broker supported, no cloud dependency. **Decided by Amish, 2026-09-25: go with recommendation** (MPL-DDR-002).
7. **Enclosure.** Options: stock IP54 ABS box; 3D-printed box; die-cast aluminium box (better for R12, about $10 more). Recommendation: stock ABS box for the first build, with a stand-off or insulating pad studied at TRL 3 for hot frames. **Decided by Amish, 2026-09-25: go with recommendation** (MPL-DDR-002).
8. **Pilot site.** Options: a makerspace or university workshop; a small machine shop; a food or grain processing unit. Recommendation: a makerspace or university workshop with a lathe and a compressor. **Decided by Amish, 2026-09-25: go with recommendation** (MPL-DDR-002).
9. **Budget.** No change proposed: the parts total of about $79 is within the $80 budget. A three-CT or die-cast variant would need a budget increase, which is Amish's decision. **Decided by Amish, 2026-09-25: go with recommendation** (MPL-DDR-002). Later superseded by the high-temperature magnet decision, which raised the budget to $81.

### Safety concerns

- Mains voltage at the CT: fitting often needs a terminal box or panel opened by a qualified person with the machine isolated and locked off. Only voltage-output CTs with an internal burden are allowed.
- Moving machinery: fit and remove only with the machine stopped; leads must be tied clear of belts, shafts and chucks.
- Hot frames and strong magnets: burn and pinch hazards; magnets away from pacemakers.
- MachinePulse is a monitoring aid, not a protective device; it must never be wired into machine controls.

### Suggestions (not in the repo)

- A short guide for pilot sites on where to mount the pod on common machines (lathe headstock, compressor, pump) could come with the TRL 3 work.
- A TwinKit example twin of one motor would show the full data path end to end.

### Recommended next step

Review this note and the media, and decide the proposed items above, in particular the radio, current sensing and pilot site. If approved, run `/advance-trl3` to check the vibration noise and magnet mount, the current error budget, the thermal limit and the data budget by calculation, and to produce the parametric model and drawing sheet.

## Session 2026-09-25: TRL 3

On 2026-09-25 Amish asked for this batch of repos to be taken through the usual process with the instruction "you know the drill, nothing gets past TRL 3". He has not reviewed this repo's TRL 2 items one by one, so every item that carried a recommendation is adopted as recommended for TRL 3 under Amish's 2026-09-25 instruction, open for his review. This session ran `/advance-trl3` on that basis and stopped at TRL 3.

### What was done

- `docs/decisions/0001-trl2-review-decisions.md` (MPL-DDR-001 v0.1, status proposed): ten items adopted as recommended for TRL 3, open for Amish's review (D1 to D10), and two left open (O1, O2).
- `docs/04-calcs/01-sizing.md` (MPL-CAL-001 v0.1) and `docs/04-calcs/sizing.py`: CT window and starting current, current and energy error budgets, run state and run time, vibration noise, range, memory, resolution and mount resonance, magnet pull, slip and tipping, probe contact error, a three-node thermal model of the pod on a hot frame, power, data, delivery and offline store, and cost, with a status for every requirement. The script imports the model (`PARAMS`, `derived()` and the part solids for mass), reads the BOM and `project.yaml`, and prints every number the note quotes with a tag.
- `cad/src/model.py`: parametric build123d model of the pod (magnets, block with round boss, nylon stand-offs, box base with floor hole and glands, lid, silicone boot, accelerometer, controller and interface boards), the CT and the probe, with installed positions on a context motor. Exports `cad/step/` and `cad/stl/` for `machinepulse-assembly`, `machinepulse-pod` and `sensor-block`.
- `cad/src/sheets.py` and `cad/drawings/MPL-DWG-001.svg`, `.pdf`, `.png`: general arrangement at Rev P1, 1:1, marked "CONCEPT, NOT FOR FABRICATION" and "PRELIMINARY, NOT FOR FABRICATION". MPL-DWG-001 was free because the concept blueprint is MPL-DWG-010.
- `bom/bom.csv` (13 lines, all priced with a supplier or supplier type, $80.00) and `bom/bom-notes.md`. Changes: line 13 nylon stand-offs added ($1.00); lines 3, 4, 5, 7, 8 and 11 respecified from the calculations (module without octal PSRAM, ±16 g range, round boss, 1.50 V bias with clamp diodes, 5 to 60 A CT range, 3 mm pads).
- `cad/src/concept_media.py` now builds from the model; all of `media/` was re-rendered and every image checked; temporary `media/_views*` folders deleted. The model puts the magnet contact line at the origin, so the kit's cutaway cuts through the pod without the scene shift used at TRL 2.
- MPL-PRB-001, MPL-PRC-001 and MPL-REQ-001 revised to v0.3; `README.md` (TRL badge and line, links, concept numbers, components) and `project.yaml` (`trl: 3`, `trl_target: 3`, evidence list) updated. PDFs rebuilt in `docs/pdf/`.

### Requirement status (MPL-CAL-001, Table 4)

1 not met, 6 at risk, 7 met by calculation, 3 met by design.

| ID | Status | Key number |
| --- | --- | --- |
| R10 Install without opening live enclosures | **Not met** | The CT needs a single insulated conductor, often only inside a terminal box or panel |
| R3 Current | At risk | 3.6 % RSS but 7.0 % worst case at 10 % of range; ADC residual assumed |
| R4 Energy | At risk | 8.5 % RSS, 16.0 % worst case with a PF curve; 26 % with a fixed PF (TRL 2 said about 20 %, not met) |
| R5 Vibration band | At risk | Mount resonance about 927 Hz on a painted curved frame (1,853 Hz flat); +10 % from 278 Hz |
| R8 Probe | At risk | 1.56 K at 80 °C, about 3.6 K at 100 °C |
| R12 Hot frames | At risk | Box and module pass with stand-offs; N-grade magnets hit 80 °C at an 81.3 °C frame |
| R16 Cost | At risk | $80.00 against $80, no margin |
| R1, R2, R6, R7, R9, R11, R15 | Met by calculation | 0.037 mm/s noise; 0.407 Hz bins; 1.15 MB/day; slip margin 3.3; 13.9 days offline |
| R13, R14, R17 | Met by design | |

Key numbers: design motor 14.6 A on a 30 A CT; pod 100 x 68 x 63 mm, 295 g; 0.42 W from 5 V (5.3 kWh a year at the wall); spectrum 7.4 kB. TRL 2 figures corrected: data 0.4 to 1.15 MB/day (a spectrum is 7.4 kB, not 1 kB), CT range 5 to 60 A (the 100 A SCT-013-000 is current output), "usable to 2 kHz" mount withdrawn, box limit about 60 °C replaced by a magnet limit of about 81 °C.

### Decisions recorded (MPL-DDR-001)

Decided by Amish, 2026-09-25: go with recommendation (first adopted for TRL 3 under his instruction, then accepted; see MPL-DDR-002): D1 Wi-Fi first; D2 certified 5 V adapter; D3 IIS3DWB class with ADXL345 fallback; D4 one CT on one phase; D5 first-week baseline alerts to a person; D6 TwinKit or any MQTT broker, no cloud; D7 stock ABS box with a stand-off studied (5 mm nylon stand-offs adopted from the study); D8 makerspace or university workshop pilot; D9 no budget change; D10 features every minute and a spectrum every 15 min. No reworded pitch or problem line was recommended, so `project.yaml` and `README.md` keep the existing wording. `budget_usd` stays $80.

### Still awaiting Amish

1. **O1, co-design partner** for the alerts and dashboard. No recommendation was made. Proposed, awaiting Amish.
2. **O2, R4 with one CT.** Options: (a) accept R4 as at risk with the power factor curve (8.5 % RSS); (b) relax R4 to "relative energy trend"; (c) add a voltage reference ($10, total $90.00, over budget). The TRL 2 note offered (a) or (b) without choosing, so no option is adopted. Proposed, awaiting Amish.
3. **New, magnets for hot frames (R12).** Options: (a) keep N-grade magnets and state the frame limit as 80 °C with no margin; (b) high-temperature pot magnets rated 120 °C or more, about $1.00 more for the pair, total $81.00, over the $80 budget. Recommendation: (b), because the magnets sit within 2 K of the frame. **Decided by Amish, 2026-09-25: go with recommendation** (MPL-DDR-002, N1); applied, `budget_usd` now 81.
4. **New, R8 range.** Recommendation: state R8 as within 2 °C from 0 to 85 °C, and within 4 °C from 85 to 100 °C. **Decided by Amish, 2026-09-25: go with recommendation** (MPL-DDR-002, N2); applied in MPL-REQ-001 v0.4.
5. **New, R5 and R3 follow-up.** Recommendation: keep both targets, record the mount resonance and the ADC residual as the first things to measure at TRL 4, and consider a flat steel saddle for curved frames. **Decided by Amish, 2026-09-25: go with recommendation** (MPL-DDR-002, N3); targets kept, measurements and saddle are TRL 4 work, on hold.

### Cross-repo consistency

- TwinKit (TWK REVIEW, TRL 3): accepts MQTT over Ethernet or Wi-Fi (R2), runs the broker and stores data locally. MachinePulse's 1.15 MB a day per machine is small against its storage budget. No conflict. TwinKit's twin service would host the baseline and the power factor curve; that is a software assumption, not an interface change.
- FieldNode (FND REVIEW, TRL 3): LoRaWAN core with 20-byte payloads. Only a summaries-only MachinePulse variant could use it; spectra cannot. No conflict, since D1 keeps Wi-Fi.
- CalRig (CLR REVIEW): can check the DS18B20 probe against its reference; no vibration reference. No interface assumed at TRL 3.
- CellGuard, MotionCore and ThermaCart: not used.

### Safety concerns

- Mains voltage at the CT: fitting often needs a terminal box or panel opened by a qualified person with the machine isolated and locked off. Only voltage-output CTs; the CT input on the interface board is now clamped against starting current (4.14 V peak at 6 x full load).
- Moving machinery: fit and remove only with the machine stopped; leads tied clear of belts, shafts and chucks.
- Hot frames and strong magnets: the block runs within a few kelvin of the frame; standard magnets are at their temperature limit on 80 °C frames. Magnets away from pacemakers.
- MachinePulse is a monitoring aid, not a protective device; it must never be wired into machine controls.

### Gaps and notes

- Prices are indicative, not supplier quotes. No citations were flagged as unchecked in the TRL 2 note, so no WebFetch checks were made and no sources were added.
- Assumptions that only tests can settle: ESP32-S3 ADC residual error, magnet contact stiffness, the pull-gap law and friction, probe contact resistance, and the thermal coefficients.
- The concept blueprint `media/concept-blueprint.png` shows the installed pod, CT and probe, so its orthographic views are small at 1:5; the GA sheet MPL-DWG-001 shows the pod at 1:1.
- Existing material beyond TRL 3: `build-log/README.md` (scaffold) is present, untouched and not extended. `firmware/` and `electronics/` hold only placeholders. No test, build or firmware material was created.

### Recommended next step

TRL 4 is on hold by Amish's instruction; this repo stops at TRL 3. Amish's review is needed on O1, O2 and new items 3 to 5 above. For the record only, TRL 4 would need: a bench build of one pod; a lab test report (TST, `environment: lab`) covering CT accuracy against a clamp meter across the range, energy against a reference meter, mounted resonance and noise on flat and curved painted steel, magnet pull and slip, probe error against a thermocouple, pod temperatures on a hot plate at 80 °C, and power and data volume over a sustained run; and build log entries. None of this has been started.

## Session 2026-09-25: recommendations accepted

On 2026-09-25 Amish wrote: "i accept all your recommendations, go with them across all repos." Every item in this note and in MPL-DDR-001 that carried a recommendation is now **Decided by Amish, 2026-09-25: go with recommendation**. The record is `docs/decisions/0002-recommendations-accepted.md` (MPL-DDR-002 v0.1).

### Decisions applied and what changed

- **D1 to D10 (MPL-DDR-001):** radio, power, accelerometer, one CT, baseline alerts, data home, enclosure with stand-offs, pilot site type, budget and data schedule. Wording changed from "adopted for TRL 3, open for review" to decided; no design change. D9 ("no budget change") is superseded in effect by N1.
- **N1, high-temperature magnets (R12):** BOM line 6 from $3.50 to $4.00 each (a 120 °C grade); parts from $80.00 to $81.00; `budget_usd` from 80 to 81; `mag_t_max` = 120 °C added to `cad/src/model.py` (geometry unchanged) and STEP and STL re-exported; MPL-DWG-001 from Rev P1 to Rev P2 (magnet note); hot-frame limit from 81.3 °C (magnets) to 109.6 °C (accelerometer); R12 from at risk to met by calculation.
- **N2, R8 range:** target from "within 2 °C, 0 to 100 °C" to "within 2 °C from 0 to 85 °C, within 4 °C from 85 to 100 °C"; 1.69 K at 85 °C and 3.59 K at 100 °C, so R8 moves from at risk to met by calculation.
- **N3, R3 and R5:** targets kept; ADC residual and mount resonance are the first TRL 4 measurements, and a flat steel saddle is the option to consider then. Decided but on hold.
- Documents revised: MPL-PRB-001 v0.4, MPL-PRC-001 v0.4, MPL-REQ-001 v0.4, MPL-CAL-001 v0.2 (script rerun, results match), MPL-DDR-001 v0.2, new MPL-DDR-002 v0.1; `bom/bom.csv`, `bom/bom-notes.md`, `project.yaml`, `README.md`. Concept media, the GA sheet and all PDFs were regenerated, which also removes the old site address from generated files.
- `README.md`: "What sparked the idea" rewritten around the Toyoda Type G automatic loom (1924) and its auto-stop devices, the origin of jidoka; the reference to how the project was chosen is removed.

### Requirement status now (MPL-CAL-001 v0.2)

1 not met, 4 at risk, 9 met by calculation, 3 met by design (was 1, 6, 7, 3).

| ID | Status | Key number |
| --- | --- | --- |
| R10 Install without opening live enclosures | **Not met** | CT needs a single insulated conductor, often inside a terminal box |
| R3 Current | At risk | 7.0 % worst case at 10 % of range |
| R4 Energy | At risk | 8.5 % RSS, 16.0 % worst case |
| R5 Vibration band | At risk | Mount resonance about 927 Hz on a curved frame |
| R16 Cost | At risk | $81.00 against $81, no margin |
| R1, R2, R6, R7, R8, R9, R11, R12, R15 | Met by calculation | R8 3.59 K at 100 °C against 4 °C; R12 limit 109.6 °C frame |
| R13, R14, R17 | Met by design | |

### Still awaiting Amish

1. **O1, co-design partner** for alerts and dashboard. No recommendation. Proposed, awaiting Amish.
2. **O2, R4 with one CT.** Accept at risk, relax to a relative energy trend, or add a voltage reference (parts $91.00). No single option was recommended. Proposed, awaiting Amish.

### Cross-repo actions

None. The decisions change no interface with TwinKit, FieldNode or CalRig.

### TRL 4

TRL 4 remains on hold by Amish's instruction. `trl: 3` and `trl_target: 3` are unchanged. No build, test, pilot, purchasing, PCB or firmware work was started.

## Session 2026-09-26: sources strengthened

- README, "By country or region", United States row: ITIF policy article (itif.org, citing NAM) replaced by the SBA Office of Advocacy manufacturing statistics (98 % of manufacturers are small), with NAM's Census-based figures (239,265 firms in 2022, all but 4,177 under 500 employees, about three-quarters under 20) kept alongside. The earlier "roughly 244,000" figure is replaced by the verified 2022 count.
- README, India and European Union rows: uncited statements about machine age removed; each row now states only what its source supports.
- All other README links (NIST, IEA, World Bank, PIB, IEA Africa Energy Outlook, ECLAC, Eurostat, Toyota Industries, Toyota) were fetched and confirmed to support their claims. "What sparked the idea" unchanged; it already rests on Toyota's own history pages.
- No controlled document changed; no budget change.

## Session 2026-09-26: product appearance model and photoreal renders

Amish chose this repo for the first batch of product renders on 2026-09-26.

### What was added

- `cad/src/product_model.py`: an appearance model for photoreal renders. `product_parts()` returns 41 parts (26 shell, 9 internal, 3 accessory, 3 context) with colour, material class, BOM line, group and explode offset. It also defines `TITLE` and `RENDER_VIEWS` (hero on the motor, exploded, and a detail view of the hub and sensors without the motor).
- Enclosure: two-tone stock box with filleted corners and edges, a parting-line groove at the lid joint, four lid screws in corner pockets, a lit status light pipe in a bezel (BOM 1 and 7), a silicone status button, and a printed lid label with the kit accent stripe.
- Fluted M12 cable glands with seal inserts on both end walls (BOM 2).
- Magnetic sensor base: filleted aluminium block and boss (BOM 5), M6 stud nut, high-temperature pot magnets with a pole groove (BOM 6), nylon stand-offs (BOM 13) and the silicone boot (BOM 12).
- Internals: ESP32-S3 board with module shield, USB-C and antenna print (BOM 3), interface perfboard with jack, terminal block and capacitors (BOM 7), accelerometer adapter board (BOM 4), brass board spacers (BOM 12).
- Current transformer: filleted ring and latch with the split-core seam, a latch finger recess, a "30 A : 1 V, VOLTAGE OUTPUT" marking and a cable strain relief (BOM 8).
- Temperature probe: filleted magnetic clip, retaining strap, stainless sleeve with crimp ring and heat-shrink boot (BOM 9).
- Accessories for the exploded view: the two steel adhesive pads (BOM 11) and the USB-C power adapter with its cable (BOM 10), neither of which model.py shows.
- Context: the 7.5 kW class motor from `motor_context()` in clay, the insulated phase conductor through the clamp, and swept clamp, probe and USB leads.
- `README.md`: hero image now points to `media/render-hero.png`, with a link to `media/render-exploded.png`. The render files are produced separately.

### Differences from model.py

Every main dimension and interface (box, lid and base heights, wall, glands, floor hole, block and boss, magnets, stand-offs, board positions, clamp and probe envelopes, installed positions) is taken from PARAMS and derived(). The following are appearance choices, each Proposed, awaiting Amish:

1. **Status button on the lid.** BOM line 7 lists a button, but model.py shows no lid opening for it. The appearance model puts a 9 mm silicone button at pod coordinates (30, -4), next to the LED. Recommendation: keep it on the lid beside the LED so a user can wake or pair the pod without opening the box; confirm before the drawing shows it.
2. **Two-tone enclosure.** Light grey lid on a dark grey base. A stock IP54 box is usually one colour. Recommendation: accept for the renders; buy a single-colour box and treat the two-tone scheme as a later option.
3. **Separate vibration puck.** The render brief asked for a vibration sensor puck. In this design the accelerometer sits on the boss of the aluminium block inside the hub, so there is no separate puck; the magnetic sensor base under the hub plays that role. Recommendation: keep the design as it is (MPL-DDR-001 D7); the renders show the sensor base, not a puck.
4. **Probe and USB leads share the probe-side gland**, as model.py already routes them; the model shows a two-hole seal insert. Recommendation: specify a multi-hole seal insert for that gland at TRL 4.
5. **Lid label and clamp marking** are illustrative artwork, not a specified label.

### Status

This is an appearance model only: no tolerances, no fabrication detail, and no change to model.py, the BOM, the calculations or the drawing. `trl` stays 3 and TRL 4 remains on hold.

## Session 2026-09-27: kit 1.5.0 and image quality

- Kit 1.5.0 synced: STANDARDS v1.5 (sections 12 to 15: product renders, storefront images and image quality, public release, authorship and signing), `.kit/cards.py`, `.kit/image_qc.py`, `.kit/release_gate.py`, issue templates, and the `/render-product` and `/release` commands. `CLAUDE.md` now matches `.kit/CLAUDE.md`.
- Every `media/render-*.png` recaptioned from its original render with the new layout: the title, concept label and repository sit in a band above the render and the view note in a band below it, each line wrapped to the image width, so no text overlaps other text or the render or runs off the image. `media/card.png` and `media/social-preview.png` regenerated with the same rules.
- `python .kit/image_qc.py` and `python .kit/release_gate.py` pass. trl stays 3.

## Session 2026-10-01: design for construction and prototype build plan (kit 1.7.0)

Amish approved the build plan format on 2026-09-30 and asked for it across all repos, with outstanding decisions kept in a separate register. This session installed kit 1.7.0, made the design constructable and wrote the illustrated build plan. No commit or push was made from this working copy.

### What was done

- Kit 1.7.0 installed (`.kit/`, `.claude/commands/`); `CLAUDE.md` now matches `.kit/CLAUDE.md`.
- `cad/src/model.py`: constructable model with 25 components and a `--check` mode; 102 constructability checks (26 contacts, 21 clearances, 55 overlap tests) all pass. STEP and STL re-exported.
- `docs/decisions/0003-design-for-construction.md` (MPL-DDR-003 v0.1, Draft): every change below, made under Amish's 2026-09-30 instruction to make the design physically buildable; open for his review.
- `docs/05-build-plan.md` (MPL-BLD-001 v0.1) with `cad/src/build_plan_media.py`: overview, six making sketches (MPL-DWG-101 to 106), a drilling layout, seven joint close-ups, thirteen step pictures and a wiring diagram.
- `docs/06-design-decisions.md` (MPL-DEC-001 v0.1): six open decisions, eight items to confirm when parts are bought, value engineering, and decisions made.
- MPL-DWG-001 Rev P4; MPL-CAL-001 v0.3, MPL-REQ-001 v0.5, MPL-PRC-001 v0.5; `bom/bom.csv` (14 lines) and `bom/bom-notes.md`; concept media regenerated; `project.yaml` (`design_state: constructable`, evidence); README links line and "Building the prototype" section.

### Design changes made for construction (MPL-DDR-003)

1. Sensor block made as a 10 mm plate; the boss is a separate piece of 20 mm round bar on an M6 x 12 set screw over magnet 1, so no lathe or mill is needed.
2. Magnet holes tapped M6 through; studs trimmed to 5 mm.
3. Nylon stand-offs moved to 33 x 13 mm each side of centre and held by M3 nylon screws into the block (they were 0.6 mm from the floor hole and overlapped the boot).
4. The floating boot replaced by a silicone grommet in the floor hole, gripping the boss.
5. The two floating boards replaced by one 45 x 56 mm carrier perfboard on four M3 x 5 mm stand-offs, with the controller in header sockets.
6. Three glands, one lead each (M16 for the CT, M12 for the probe and for power), centred 15.5 mm up so the nuts clear the floor and pillars; the power cable's far plug is cut off and wired to a 5 V terminal.
7. The box's moulded corner pillars modelled and every clearance checked against them.
8. The accelerometer bonded to the boss with rigid epoxy after the base is fitted (its board cannot pass the floor hole).
9. A made probe clip (aluminium block, groove, two high-temperature disc magnets) holds the sleeve on its pad against the frame; the concept's sleeve sat 7 mm above the frame. New BOM line 14.
10. A 3 mm light pipe takes the status LED through a sealed hole in the lid.

### Key results

- Pod 319 g (was 295 g); mount resonance 892 Hz curved, 1,783 Hz flat (was 927 and 1,853 Hz); slip margin 3.0 (2.8 at 80 °C); thermal results unchanged; 137 mm over the glands.
- Requirement status: 1 not met (R10), 3 at risk (R3, R4, R5), 9 met by calculation, 3 met by design. R16: value-engineering target USD 81; estimated cost of the constructable design USD 83.50 (USD 2.50 over the target). `budget_usd` unchanged.

### Proposed, awaiting Amish

See the design decisions register: acceptance of MPL-DDR-003 (decision 1), the power entry (2), the status button position (3), plus the earlier open items R4 treatment (4), co-design partner (5) and enclosure colour (6).

### Stale files to regenerate on Amish's Mac

The design changed visibly (glands, boss, boards, probe clip), so these still show the concept: `media/render-hero.png`, `media/render-exploded.png`, `media/render-detail.png` (not present in this working copy), `media/card.png`, `media/social-preview.png`, and the appearance model `cad/src/product_model.py`, which still models the boot, two boards and two glands.

### Safety concerns

Unchanged: mains at the current transformer (qualified person, isolation, voltage-output only), moving machinery, hot frames and strong magnets. The build plan adds safety stops S1 to S5 and the epoxy and threadlocker precautions. The adapter stays a certified 5 V unit; cutting its cable's far plug does not change the safety case.

### Recommended next step

Amish to review MPL-DDR-003 and the register's open decisions. TRL 4 remains on hold; the build plan is ready for a bench build when it is lifted.

## Session 2026-10-02: open decisions decided by Amish

Authority: Amish, 2026-10-02: "i approve your recommendations for all 555 open decisions." The recommendations approved are those written for the open decisions in the design decisions register. No model, BOM quantity or price, or picture was changed; where a decision needs one, it is listed below as a follow-up. `trl` and `trl_target` stay at 3. No commit or push.

### Decisions recorded

6, all moved to "Decisions made" in `docs/06-design-decisions.md`, dated 2026-10-02:

1. Design for construction (MPL-DDR-003) accepted: all ten changes.
2. Power entry: cut USB cable through an M12 gland to a screw terminal, for the prototype.
3. Status button: on the carrier board, pressed with the lid off; a sealed lid button only if field pairing shows it is needed.
4. R4 restated as a relative energy trend for the first build, with any kWh figure reported as an estimate; a voltage reference stays an option for sites that need absolute energy.
5. Co-design partner for alerts and dashboard: the makerspace pilot's shop lead, with the maintenance person of one small production machine shop as a second voice (first candidates to approach).
6. Enclosure colour: single-colour stock box; two-tone a later option.

### Documents changed

- `docs/06-design-decisions.md` (MPL-DEC-001 v0.2)
- `docs/decisions/0003-design-for-construction.md` (MPL-DDR-003 v0.2): accepted; A1 and A2 recorded; status stays Draft
- `docs/decisions/0001-trl2-review-decisions.md` (MPL-DDR-001 v0.3): O1 and O2 decided
- `docs/decisions/0002-recommendations-accepted.md` (MPL-DDR-002 v0.2): O1 and O2 decided
- `docs/02-concept.md` (MPL-PRC-001 v0.6): R4 as a relative trend; partner candidates
- `docs/03-requirements.md` (MPL-REQ-001 v0.6): R4 restated; met by design as restated; counts
- `docs/04-calcs/01-sizing.md` (MPL-CAL-001 v0.4): R4 row and summary count

### Follow-up actions to carry approved decisions into the design

1. Decision 4 (docs): State in the firmware and gateway sketch notes that energy is shown as a relative trend against the machine's baseline and any kWh figure is labelled an estimate.
2. Decision 6 (pictures): Show a single-colour stock box in the photoreal renders (`media/render-*.png`) and `cad/src/product_model.py` when they are next regenerated on Amish's Mac.

### Points found in the review

- A saving in Value engineering (reusing an existing USB charger at the site) conflicts with the decided certified 5 V adapter (D2) and R17; it should be removed.
- R10 is not met for many machines because the current transformer often has to go inside a terminal box opened by a qualified person, yet there is no open decision on how installs will be handled. A rule that a qualified electrician fits the CT would close it.

## Session 2026-10-02: approved follow-ups carried out

Amish approved all follow-up actions from the open-decision sign-off on 2026-10-02. trl stays 3; nothing was built or tested. No model, BOM, calculation or picture change was called for by the decisions, so STEP, STL, drawings, build plan pictures and `sizing.py` results are unchanged.

### Approved follow-ups carried out

1. Decision 4 (docs): done. The precis (`docs/02-concept.md`, MPL-PRC-001 v0.7) now states the rule for the firmware and gateway notes: energy is shown only as a relative trend against the machine's baseline, and any kWh figure is labelled an estimate. No firmware or gateway sketch file exists yet (firmware is TRL 4 work), so the rule is recorded where the design is described.
2. Decision 6 (pictures): done for the appearance model: `cad/src/product_model.py` now draws the lid and base of the enclosure in one colour (a single-colour stock box). The photoreal renders are made next on Amish's Mac.

### Points found in the review, handled

- The Value engineering saving that reused an existing USB charger was removed from `docs/06-design-decisions.md` (MPL-DEC-001 v0.3); a certified adapter stays in every kit (D2, R17).
- Not changed: R10 and a rule that a qualified electrician fits the CT. That is a new decision for Amish (Proposed, awaiting Amish).

### Requirement status and cost

No requirement status changed. Value-engineering target: USD 81. Estimated cost of the constructable design: USD 83.50 (USD 2.50 over the target); `budget_usd` unchanged. Mass unchanged.

### Render scenes

Exported to `/home/claude/renders/machinepulse`: hero, exploded and detail (one .npz and .json each, plus `machinepulse__jobs.json`). Photoreal renders, captions, `card.png` and `social-preview.png` are made on the Mac.

### Cross-repo actions

None.

## 2026-10-02: photoreal renders redone on the constructable design

Rendered with Blender Cycles on Amish's Mac from the updated appearance model; captioned with `.kit/photo_caption.py`; `media/card.png` and `media/social-preview.png` regenerated with `.kit/cards.py`. Views: hero, exploded, detail. image_qc passes. Appearance deviations are those logged above as proposed, awaiting Amish.

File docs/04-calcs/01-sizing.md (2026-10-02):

---
doc_id: MPL-CAL-001
title: MachinePulse sizing calculations
project: MachinePulse
doc_type: Calculation
version: "0.4"
status: Draft
date: '2026-10-02'
author: Amish Chadha
license: CERN-OHL-S-2.0
revisions:
- version: "0.1"
  date: '2026-09-25'
  author: Amish Chadha
  change: First issue for TRL 3 (current and CT window, current and energy error budgets, vibration noise, bandwidth and mount resonance, magnet holding, probe error, pod temperature, power, data and storage, cost)
- version: "0.2"
  date: '2026-09-25'
  author: Amish Chadha
  change: Recommendations accepted by Amish (DDR-002)
- version: "0.3"
  date: '2026-10-01'
  author: Amish Chadha
  change: Constructable design (MPL-DDR-003); mass, mount resonance, magnet margins and cost re-run; budget treated as a value-engineering target
- version: "0.4"
  date: '2026-10-02'
  author: Amish Chadha
  change: 'R4 restated by Amish on 2026-10-02; requirement table and summary count updated (2 at risk, 4 met by design)'
---

# MachinePulse sizing calculations

On paper, MachinePulse meets twelve of its seventeen requirements (nine by calculation, three by design), has three at risk, misses one, and its estimated cost is over the value-engineering target. Version 0.4 records R4 restated by Amish on 2026-10-02 as a relative energy trend, met by design, so thirteen are met (four by design) and two are at risk; the figures below are unchanged. Version 0.3 re-runs the numbers for the constructable design of MPL-DDR-003 (a separate boss on a set screw, a carrier board on stand-offs, a third gland, a grommet, a light pipe and a made probe clip): the pod is 24 g heavier, so the mount resonance and the magnet margins fall slightly, the thermal results are unchanged, and the parts cost rises to $83.50, $2.50 over the $81 value-engineering target. Version 0.2 applied the decisions Amish made on 2026-09-25 (MPL-DDR-002): high-temperature pot magnets rated 120 °C replace the standard 80 °C grade, the budget rises from $80 to $81 to pay for them, and R8 is restated with a 4 °C tolerance from 85 to 100 °C. As a result R8 and R12 move from at risk to met by calculation. The miss is R10: on many machines the current transformer (CT) can only go round a single insulated conductor inside a terminal box or panel, which needs a qualified person and isolation. The three at risk are current accuracy at the bottom of the CT range (R3), energy per shift (R4) and the magnet mount's resonance inside the vibration band (R5). Cost (R16) is reported against the value-engineering target: $83.50 against $81, $2.50 over. Several TRL 2 figures change. Data per day is about 1.15 MB, not 0.4 MB, because a full-resolution spectrum is 7.4 kB, not 1 kB. The magnet mount resonates at about 0.89 to 1.78 kHz rather than being usable to 2 kHz. Energy error with a fixed power factor is about 26 %, not 20 %; with a load-dependent power factor curve it falls to 8.5 % RSS. The box on its own would survive an 80 °C frame; the limit that TRL 2 put at 60 °C was set by the standard magnets at about 81 °C, not by the enclosure, and with the high-temperature magnets it moves to the accelerometer at about 110 °C. The calculations add four details within the adopted design: a CT bias of 1.50 V instead of 1.65 V, clamp diodes on the CT input, a ±16 g accelerometer range, and 5 mm nylon stand-offs between the sensor block and the box floor. Every number in this note is printed by `docs/04-calcs/sizing.py`; the tag in brackets, for example [D7], is the line of that script's output that carries it.

> **Safety:** These are first-principles estimates for a paper proof of concept. They are not a substitute for bench measurements, an electrical safety review of the CT installation or pull tests on real frames. See MPL-PRC-001, Safety.

## Scope and method

The note checks every requirement in MPL-REQ-001 v0.4 against the design in MPL-PRC-001 v0.4 and the parametric model `cad/src/model.py`. The script imports the model's `PARAMS`, `derived()` and part solids, so the magnet spacing, block, stand-off gap, box and part volumes used here are the ones in the STEP files and in drawing MPL-DWG-001. It also reads `bom/bom.csv` and `budget_usd` in `project.yaml`. Run it from the repo root with `python docs/04-calcs/sizing.py`.

The design case is a 7.5 kW, 400 V three-phase induction motor (IEC 132 frame class, 130 mm frame radius) in a workshop at 40 °C, with the pod on the top line of the frame and the CT on one phase conductor where it leaves the terminal box.

Status terms used in Table 4: **met by calculation** (the estimate meets the target with the stated assumptions), **met by design** (a design feature meets it; no number to compute), **at risk** (the central estimate meets the target but the worst case or a key untested assumption does not, or the margin is nil), and **not met**.

## Assumptions

*Table 1. Main assumptions.*

| Area | Assumption | Basis |
| --- | --- | --- |
| Motor | 7.5 kW, 400 V, efficiency 0.88, power factor 0.84 at full load | Typical nameplate values |
| CT | SCT-013 class, voltage output, 1 V RMS at rated current, 13 mm aperture; ratio nonlinearity 1 % after calibration | Typical of the family; to confirm |
| ADC | ESP32-S3 ADC at 12 dB attenuation treated as linear from 0.10 to 2.90 V; residual error after two-point calibration equal to 3 mV on a 1 s RMS value; noise 3 LSB RMS | Assumed; the S3 ADC's nonlinearity is the main current risk and must be measured |
| Other current errors | Burden and reference drift 1 %; calibration clamp meter 1 %; conductor position 1 % | Assumed |
| Energy | Supply voltage within ±5 % of nominal; power factor from a nameplate-based curve within ±6 % running and ±25 % at idle; phase imbalance 3 % | Assumed |
| Accelerometer | IIS3DWB class: 75 µg/√Hz, 26.667 kHz output rate, ±16 g range ([ST](https://www.st.com/en/mems-and-sensors/iis3dwb.html)); ADXL345 class fallback taken as about 400 µg/√Hz | Datasheet figure for the first; order of magnitude for the second |
| Mount stiffness | Contact stiffness per magnet 2.0 × 10⁷ N/m on flat clean steel, 0.5 × 10⁷ N/m on a painted curved frame | Assumed; to be measured |
| Magnets | 32 mm pot magnet, 290 N rated pull on thick flat steel; pull falls as F₀ / (1 + g/0.5 mm)² with gap g; 0.2 mm paint; friction 0.25; full pull needs about 4 mm of steel; high-temperature grade rated 120 °C (`mag_t_max` in the model; standard N grade, 80 °C, kept for comparison); pull falls 0.12 %/K | Typical catalog values; gap law assumed |
| Probe | DS18B20 within 0.5 °C from −10 to 85 °C, taken as 2 °C above 85 °C; 0.5 mm thermal pad at 3 W/mK over 6 x 20 mm plus 1 K/W for clip and sleeve; 10 W/m²K on the sleeve; 0.005 W/K down the lead | Datasheet figure below 85 °C; the rest assumed |
| Thermal | ABS box continuous-use limit 70 °C; controller module rated 85 °C (no octal PSRAM) with an 8 K local rise; accelerometer rated 105 °C; outside surfaces 8 to 10 W/m²K, inside 4 to 5 W/m²K; magnet contact 750 W/m²K over half the face on paint | Assumed; check against the chosen box and module datasheets |
| Power | Wi-Fi connected with modem sleep 80 mA at 3.3 V; 40 mA more for 5 s a minute during the burst; linear regulator from 5 V; adapter 70 % efficient at this load | As at TRL 2; to be measured |
| Data | Summary 200 B a minute; spectrum every 15 min, three axes, one byte per bin; 15 % protocol overhead; 4 MB of flash for the offline queue | Design choices |

## A. Motor current and CT window (R1, R3)

- **Design motor.** Full-load current is 14.6 A, 49 % of a 30 A CT [A1]. Small and large machines need other CTs: 0.37 kW single-phase draws 3.3 A and 1.5 kW three-phase 3.4 A, both suited to a 5 A CT; 15 kW draws 28.0 A and needs a 50 A CT [A2]. The voltage-output range therefore runs from 5 to 60 A. The 100 A SCT-013-000 is a current-output type and is excluded, so the TRL 2 key figure "5 to 100 A" is corrected.
- **ADC window.** At full range the CT gives 1.414 V peak. About the TRL 2 bias of 1.65 V it would reach 3.064 V, 0.164 V above the linear window [A4]. A 1.50 V bias spans 0.086 to 2.914 V [A3], which clips the peak by 1 % and costs 0.12 % of RMS at 100 % of range [A5]. The interface board bias moves to 1.50 V.
- **Starting current.** About six times full load (88 A) gives 4.14 V peak at the ADC pin [A6]. A series resistor and clamp diodes on the CT input are added to the interface board (BOM line 7); run-state logic ignores the clipped start.

## B. Current error, run state and run time (R1, R2, R3)

*Table 2. Current error budget [B1].*

| Point in the CT range | ADC term | RSS | Worst-case sum | R3 target |
| --- | --- | --- | --- | --- |
| 10 % | 3.0 % | 3.6 % | 7.0 % | 5 % |
| 49 % (design motor) | 0.6 % | 2.1 % | 4.6 % | 5 % |
| 100 % | 0.3 % | 2.0 % | 4.3 % | 5 % |

- **R3 is at risk.** The RSS error meets 5 % across the range, but the worst case at 10 % of range is 7.0 %, and the ADC term rests on an assumed 3 mV residual. Choosing the CT so that normal load sits above about 30 % of its range (section A) keeps the design motor at 4.6 % worst case. Under MPL-DDR-002 (N3) the target is kept and the ADC residual is the first thing to measure at TRL 4.
- **Run state.** A 1 s RMS window holds 2,000 samples, 50 whole cycles at 50 Hz and 60 at 60 Hz, so the state updates every second [B3]. ADC noise reads as about 0.07 A at zero current on a 30 A CT, well below a 0.5 A off threshold [B2]. R1 is met by calculation.
- **Run time.** The worst-case edge error of 1 s is 1.00 % of a 100 s run and 0.17 % of a 10 min run; it reaches 3.33 % only for 30 s runs, where random edge errors over a week largely cancel [B4]. R2 is met by calculation for runs of 100 s or longer even in the worst case.

## C. Energy per shift from one CT (R4)

- **Example shift.** Three hours idling at 40 % of full-load current and power factor 0.20, then five hours at 80 % and 0.81, use 35.3 kWh [C1].
- **Fixed power factor (the TRL 2 method).** Using the nameplate 0.84 throughout gives 44.3 kWh, 26 % high, because idle current is mostly magnetizing current [C2].
- **Load-dependent power factor.** With a power factor curve built from the nameplate and the measured no-load current, the error terms are current 2.1 %, voltage 5 %, power factor 5.8 % and imbalance 3 % [C3], for 8.5 % RSS and 16.0 % worst case [C4]. R4 is therefore at risk rather than not met. The curve is adopted in the gateway software design.
- **Voltage reference.** Measuring voltage and power factor on one phase would give 4.3 % RSS for about $10 more [C5], which would take the parts to $91.00 [J2]. Not adopted; see the review note.

## D. Vibration sensing (R5, R6, R7)

- **Noise (R6).** Integrating 75 µg/√Hz as velocity over 10 to 1,000 Hz gives 0.037 mm/s RMS, a factor of 2.7 inside the 0.1 mm/s target. An ADXL345-class fallback at about 400 µg/√Hz gives 0.20 mm/s and would miss R6 [D1].
- **Range and sampling.** Decimating the 26.7 kHz stream by eight gives 3,333 Hz with a 1,667 Hz Nyquist limit, and 13,333 samples per axis in a 4 s burst; quantization at ±16 g adds only 3.5 µg/√Hz [D2]. The ±2 g range assumed at TRL 2 would clip: 11 mm/s at 500 Hz is already 5.0 g peak [D3].
- **Memory.** The raw burst at full rate is 640 kB and does not fit the ESP32-S3's 512 kB of internal SRAM; decimating as the FIFO is read keeps 80 kB, plus a 66 kB FFT buffer [D5].
- **Resolution (R7).** An 8,192-point FFT at 3,333 Hz gives 0.407 Hz bins (0.61 Hz Hann noise bandwidth), against 0.5 Hz; the 1x line of a 1,450 rpm motor is at 24.17 Hz [D4]. R7 is met by calculation.
- **Mount resonance (R5).** The constructable pod weighs 319 g [D6] (295 g in v0.2, before the carrier board, sockets, glands, pillars and fixings of MPL-DDR-003), all carried by the two magnet contacts. On flat clean steel it resonates at about 1,783 Hz, so readings are 10 % high by 535 Hz; on a painted 130 mm radius frame it resonates at about 892 Hz, 10 % high by 267 Hz and 3 dB high by 481 Hz [D7]. The sensor covers the 10 to 1,000 Hz band, but the mount does not measure it flat. Overall velocity on most machines is dominated by running-speed components well below 267 Hz, so the effect on the ISO 20816 value is usually small; bearing and gear content near the top of the band will be overstated. R5 is at risk; under MPL-DDR-002 (N3) the target is kept, the mount resonance is the first thing to measure at TRL 4, and a flat steel saddle for curved frames is the option to consider then. The TRL 2 statement "usable to about 2 kHz" is withdrawn.

## E. Magnet holding (R11)

- **Pull.** Through 0.2 mm of paint a magnet keeps about 51 % of its rated pull on a flat frame and 33 % on a 130 mm radius frame, because the face touches only along a line [E1]. The pair gives 296 N flat and 191 N curved, against 15.6 N at 5 g [E2].
- **Margins.** Pull-off margin is 12.2 on the curved frame. Slip governs: 0.25 friction gives a margin of 3.0 curved and 4.7 flat [E3]. At 80 °C the magnets lose about 7 % of their pull and the curved slip margin falls to 2.8 [G5]. Tipping across a curved frame, with the contact lever taken as a quarter of the magnet diameter, has a margin of 3.5 [E4]. R11 is met by calculation, with the pull-gap law and friction still to be checked by a pull test.
- **Aluminium frames.** Steel pads 3 mm thick keep about 75 % of rated pull (435 N, slip margin 7.0) [E5]. Thin 1 mm pads would keep about 25 % (slip margin 2.3) [E6], so BOM line 11 now specifies 35 mm by 3 mm discs.

## F. Surface temperature probe (R8)

- **Contact error.** With a thermal pad and the sleeve cooled by air and its lead, the probe reads 1.06 K low on an 80 °C frame and 1.19 K low at 85 °C, for totals of 1.56 K and 1.69 K with the sensor tolerance [F1]. R8 is met to 85 °C.
- **Above 85 °C.** At 100 °C the contact error is 1.59 K and the sensor tolerance outside its ±0.5 °C band is taken as 2 °C, for 3.59 K [F1]. Against the original 2 °C target over 0 to 100 °C this was at risk. R8 as restated under MPL-DDR-002 (2 °C to 85 °C, 4 °C from 85 to 100 °C) is met by calculation, with 0.31 K in hand at 85 °C and 0.41 K at 100 °C.

## G. Pod temperature on a hot frame (R12)

- **Network.** The model has three nodes (block, box floor, inside air) between the frame and the room. Conductances are 0.547 W/K from frame to block through the magnets, 0.137 W/K from block to floor with the floor sitting on the block, 0.0229 W/K across the 5 mm stand-off gap, 0.030 W/K from floor to inside air and 0.052 W/K through walls and lid; 0.42 W of electronics heat is released inside [G1].
- **Results at an 80 °C frame and 40 °C air.** With the floor on the block (the TRL 2 arrangement), the floor reaches 67.2 °C and the controller module about 63.7 °C. With 5 mm nylon stand-offs the floor falls to 53.9 °C and the module to about 58.9 °C; the magnets sit at about 78.7 °C and the block and accelerometer at 77.4 °C [G2].

*Table 3. Frame temperature at which each limit is reached, 40 °C air [G3].*

| Arrangement | N-grade magnets 80 °C (superseded) | High-temperature magnets 120 °C | ABS floor 70 °C | Accelerometer 105 °C | Module 85 °C |
| --- | --- | --- | --- | --- | --- |
| Floor on the block (TRL 2) | 82.0 °C | 124.1 °C | 84.2 °C | 112.0 °C | 163.1 °C |
| 5 mm nylon stand-offs | 81.3 °C | 122.7 °C | 134.7 °C | 109.6 °C | Not reached |

- **Finding.** The box alone would take an 80 °C frame, with only 4 K in hand; the stand-offs add a large margin for the box and module for $1.00 and are adopted within decision D7. With standard N-grade magnets the magnets set the limit, with only 1.3 K to spare at 80 °C. Under MPL-DDR-002 the design uses high-temperature pot magnets rated 120 °C, which reach their limit only at a 122.7 °C frame. The accelerometer now sets the limit, at a 109.6 °C frame, 29.6 K above the target, so R12 is met by calculation.
- **Module choice.** ESP32-S3 module variants with octal PSRAM are rated to 65 °C and would have only 6.1 K of margin even with stand-offs [G4]. BOM line 3 now specifies a module without octal PSRAM, rated to 85 °C.

## H. Power

- **Average.** About 84.7 mA at 3.3 V (Wi-Fi modem sleep 80 mA, burst processing 3.3 mA averaged, sensors and LED), or 84.8 mA and 0.42 W from 5 V [H1]. The TRL 2 figure of about 0.5 W stands.
- **At the wall.** With a 70 % efficient adapter, 0.61 W, or 5.3 kWh a year, not the 4.4 kWh stated at TRL 2; the regulator dissipates 0.14 W inside the box [H2].
- **Peak.** Wi-Fi transmit peaks near 0.35 A, 1.75 W from the adapter, within its 1 A rating [H3].

## I. Data, delivery and offline store (R9, R15)

- **Spectrum size.** Keeping 0.407 Hz bins up to 1 kHz needs 2,458 bins per axis; at one byte per bin for three axes plus a header, each spectrum is 7.4 kB, not the 1 kB assumed at TRL 2 [I1].
- **Daily volume.** Summaries are 0.29 MB and spectra 0.71 MB a day, or 1.15 MB with protocol overhead, an average of 0.11 kbit/s [I2]. This is trivial for Wi-Fi and for a TwinKit gateway. R9 is met by calculation.
- **Delivery.** A summary reaches the broker within about 66 s of the start of its minute, against 120 s [I5].
- **Offline store (R15).** The 4 MB queue holds 13.9 days of summaries alone, or 4.0 days of summaries and spectra [I3]. The queue keeps summaries first and drops the oldest spectra when full. R15 is met by calculation. Flash wear is negligible: each 4 kB sector is erased once per 14 days of offline running [I4].

## J. Cost (R16)

Value-engineering target: USD 81 (`budget_usd`, a hypothetical control target, not a limit). Estimated cost of the constructable design: USD 83.50 (USD 2.50 over the target) from the 14-line BOM [J1]. Making the design constructable added $2.50: the third gland and the M16 gland ($0.50), the carrier board's sockets, terminals and light pipe ($1.00), the made probe clip with its magnets in place of a bought clip ($0.50 net) and the grommet, set screw and carrier fixings ($0.50) (MPL-DDR-003). A three-CT variant would cost $103.50 and a voltage reference $93.50 [J2]. Prices are indicative, not quotes. R16 is reported as over the value-engineering target by $2.50; the build stays hand tools, a drill press and perfboard, with no custom PCB.

## Results against every requirement

*Table 4. Requirement status from this note.*

| ID | Requirement | Target | Value from this note | Status |
| --- | --- | --- | --- | --- |
| R10 | Install without opening live enclosures | Pod and probe in 10 min without tools; CT on an accessible insulated conductor | Pod and probe need no tools; the CT needs a single insulated conductor, often only inside a terminal box or panel | **Not met** |
| R3 | Measure load current | Within 5 % of reading, 10 % to 100 % of range | RSS 3.6 % at 10 %, 2.1 % at 49 %; worst case 7.0 % at 10 % [B1] | At risk |
| R4 | Estimate energy per shift | Relative energy trend per shift, kWh reported as an estimate (restated by Amish, 2026-10-02; was within 10 % of a reference meter) | 8.5 % RSS, 16.0 % worst case with a PF curve; 26 % with a fixed PF [C2, C4] | Met by design as restated |
| R5 | Measure vibration | Velocity RMS, 10 to 1,000 Hz, three axes | Sensor covers the band; mount resonance 892 to 1,783 Hz, +10 % from 267 Hz on a curved frame [D7] | At risk |
| R16 | Low cost and buildable | Parts against the $81 value-engineering target; hand tools; no custom PCB | $83.50, over the target by $2.50 [J1]; hand tools, drill press and perfboard | Over the value-engineering target |
| R1 | Detect run state | Off, idle, running at 1 s resolution | 1 s RMS windows; 0.07 A zero reading against a 0.5 A threshold [B2, B3] | Met by calculation |
| R2 | Log run time | Within 1 % over a week | 1.00 % worst case on 100 s runs, 0.17 % on 10 min runs [B4] | Met by calculation |
| R6 | Low vibration noise floor | 0.1 mm/s RMS or better | 0.037 mm/s [D1] | Met by calculation |
| R7 | Resolve running-speed peaks | 0.5 Hz bins or finer to 1 kHz | 0.407 Hz [D4] | Met by calculation |
| R8 | Measure frame temperature | Within 2 °C to 85 °C; within 4 °C from 85 to 100 °C | 1.56 K at 80 °C, 1.69 K at 85 °C, 3.59 K at 100 °C [F1] | Met by calculation |
| R9 | Report often enough | Summary each minute, spectrum each 15 min, within 2 min | 1.15 MB/day; 66 s worst delivery [I2, I5] | Met by calculation |
| R11 | Stay attached | No slip at 5 g on a painted cast frame; aluminium option | Slip margin 3.0 (2.8 at 80 °C); 3 mm pads 7.0 [E3, E5, G5] | Met by calculation |
| R12 | Tolerate hot frames | Frames up to 80 °C in 40 °C air | Box and module pass with stand-offs; 120 °C magnets reach their limit at a 122.7 °C frame; accelerometer limit at 109.6 °C [G3] | Met by calculation |
| R15 | Store data when offline | 7 days of summaries | 13.9 days [I3] | Met by calculation |
| R13 | Workshop protection | IP54 or better | IP54 box, three IP68 glands (one cable each), silicone grommet round the boss, sealed light pipe | Met by design |
| R14 | Keep data local | TwinKit or any MQTT broker; no cloud | MQTT on the local network | Met by design |
| R17 | Safe by design | Low voltage in the pod; certified adapter; voltage-output CT; no link to controls | Unchanged; CT input now clamped [A6] | Met by design |

Summary (v0.4, after R4 was restated by Amish on 2026-10-02): 1 not met, 2 at risk, 9 met by calculation, 4 met by design, 1 (R16) reported against the value-engineering target, none left unverifiable at TRL 3. R13's IP rating and the at-risk items need bench evidence that belongs to TRL 4, which is on hold.

## Checks against the TRL 2 figures

*Table 5. TRL 2 figures that change.*

| Quantity | TRL 2 | This note |
| --- | --- | --- |
| Pod size and mass | 100 x 68 x 58 mm, 0.35 kg | 100 x 68 x 63 mm (137 mm over glands), 0.32 kg [D6] |
| CT variants | 5 to 100 A | 5 to 60 A voltage output [A2] |
| Current accuracy | About 3 % | 2.1 % RSS at the design point, 3.6 % at 10 % of range [B1] |
| Energy accuracy | About 20 % | 26 % fixed PF; 8.5 % RSS with a PF curve [C2, C4] |
| Magnet mount | Usable to about 2 kHz | Resonance 892 to 1,783 Hz [D7] |
| Magnet margin | About 6 times | Pull-off 12.2, slip 3.0 [E3] |
| Data volume | About 0.4 MB/day | 1.15 MB/day [I2] |
| Offline store | About 10 days | 13.9 days of summaries, 4.0 days with spectra [I3] |
| Frame temperature limit | About 60 °C (box) | About 81 °C with N-grade magnets; 109.6 °C (accelerometer) with the 120 °C magnets [G3] |
| Annual energy | About 4.4 kWh | 5.3 kWh at the wall [H2] |
| Parts cost | About $79 | $83.50 against an $81 value-engineering target [J1] |

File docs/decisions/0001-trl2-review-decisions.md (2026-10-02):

---
doc_id: MPL-DDR-001
title: MachinePulse TRL 2 review decisions
project: MachinePulse
doc_type: Design decision record
version: "0.3"
status: Draft
date: '2026-10-02'
author: Amish Chadha
license: CERN-OHL-S-2.0
revisions:
- version: "0.1"
  date: '2026-09-25'
  author: Amish Chadha
  change: Record the TRL 2 review items adopted for TRL 3 work under Amish's 2026-09-25 instruction, and the items that remain open
- version: "0.2"
  date: '2026-09-25'
  author: Amish Chadha
  change: Recommendations accepted by Amish (DDR-002)
- version: "0.3"
  date: '2026-10-02'
  author: Amish Chadha
  change: 'O1 and O2 decided by Amish on 2026-10-02'
---

# 0001: TRL 2 review decisions

- **Date:** 2026-09-25
- **Status:** accepted for D1 to D10. On 2026-09-25 Amish wrote "i accept all your recommendations, go with them across all repos", so items D1 to D10 are decided as recommended (see MPL-DDR-002). Items O1 and O2 carried no single recommendation and were decided by Amish on 2026-10-02 ("i approve your recommendations for all 555 open decisions.").

## Context

The TRL 2 review note (`docs/REVIEW.md`, session 2026-09-25, /populate) listed nine items as "Proposed, awaiting Amish", and the design precis MPL-PRC-001 v0.2 listed key design choices, most with options and a recommendation. On 2026-09-25 Amish asked for this batch of repos to be taken through the usual process with the instruction "you know the drill, nothing gets past TRL 3". He has not reviewed this repo's items one by one. Every item that carries a recommendation is therefore adopted as recommended for TRL 3 under that instruction, open for his review. Items without a single recommendation stay open.

## Options considered

The options for each item are those listed in `docs/REVIEW.md` (session 2026-09-25, /populate) and in MPL-PRC-001 v0.2, Key design choices.

## Decision

*Table 1. Items decided by Amish on 2026-09-25 (first adopted for TRL 3 work, then accepted).*

| # | Item | Adopted recommendation | Status |
| --- | --- | --- | --- |
| D1 | Radio | Wi-Fi on the ESP32-S3 first; a summaries-only LoRaWAN variant through the FieldNode radio core stays a later option | Decided by Amish, 2026-09-25: go with recommendation |
| D2 | Power | Certified 5 V USB adapter; no battery and no energy harvesting | Decided by Amish, 2026-09-25: go with recommendation |
| D3 | Accelerometer | IIS3DWB class, with the ADXL345 class kept as a documented fallback | Decided by Amish, 2026-09-25: go with recommendation |
| D4 | Current sensing | One CT on one phase, for single-phase and three-phase machines | Decided by Amish, 2026-09-25: go with recommendation |
| D5 | Alert logic | Baseline learned over the first week per load band; flags at twice baseline vibration or a temperature rise above baseline, sent to a person; fixed ISO 20816 zones a later option | Decided by Amish, 2026-09-25: go with recommendation |
| D6 | Data home | TwinKit gateway by default, any MQTT broker supported, no cloud dependency | Decided by Amish, 2026-09-25: go with recommendation |
| D7 | Enclosure | Stock IP54 ABS box for the first build, with a stand-off or insulating pad studied at TRL 3 for hot frames | Decided by Amish, 2026-09-25: go with recommendation |
| D8 | Pilot site | A makerspace or university workshop with a lathe and a compressor | Decided by Amish, 2026-09-25: go with recommendation |
| D9 | Budget | No change: `budget_usd` stays $80. Superseded in effect by MPL-DDR-002, N1, which raises it to $81 for high-temperature magnets | Decided by Amish, 2026-09-25: go with recommendation |
| D10 | Data schedule | Features computed on the pod every minute, a spectrum every 15 min, raw bursts on demand | Decided by Amish, 2026-09-25: go with recommendation |

*Table 2. Items that remained open, decided by Amish on 2026-10-02.*

| # | Item | Status |
| --- | --- | --- |
| O1 | Co-design partner for the alerts and dashboard: who decides what "changed" should mean to an operator. No recommendation was made. | Decided by Amish, 2026-10-02: the makerspace pilot already decided, with its shop lead deciding what "changed" should mean, and the maintenance person of one small production machine shop as a second voice |
| O2 | How to treat R4 with one CT. The TRL 2 note offered two courses without choosing: accept that R4 is not met in the first build, or relax R4 to "relative energy trend". MPL-CAL-001 now puts R4 at risk (8.5 % RSS) rather than not met, which bears on this choice. R4 keeps its 10 % target until Amish decides. | Decided by Amish, 2026-10-02: (b), R4 restated as a relative energy trend for the first build, with any kWh figure reported as an estimate; the voltage reference (c) stays an option for sites that need absolute energy |

## Consequences

- `project.yaml`: only the TRL fields change. No budget change was recommended (D9), and no reworded pitch or problem line was recommended, so `budget_usd`, `pitch` and `problem` and the matching lines in `README.md` keep their wording. MPL-DDR-002 later raised `budget_usd` to $81.
- MPL-PRB-001, MPL-PRC-001 and MPL-REQ-001 are revised to v0.3. The key design choices in the precis are no longer "proposed". No requirement target changes as a result of these decisions; R4 stays at 10 % pending O2.
- D7 study result (MPL-CAL-001, section G): 5 mm nylon stand-offs between the sensor block and the box floor keep the floor at 53.9 °C on an 80 °C frame, against 67.2 °C without them. They are added to the design and the BOM (line 13, $1.00), which brings the parts to $80.00, exactly the budget.
- Other details added within these decisions by the calculations: a CT bias of 1.50 V, clamp diodes on the CT input, a ±16 g accelerometer range, a module without octal PSRAM, 3 mm steel pads, a silicone boot round the boss and a load-dependent power factor curve in the gateway software.
- New proposals from MPL-CAL-001 (high-temperature magnets, R8 range, R3 and R5 follow-up) were decided by Amish on 2026-09-25 and are recorded in MPL-DDR-002.
- TRL 4 is on hold by Amish's instruction. Nothing in this record authorizes building or testing.

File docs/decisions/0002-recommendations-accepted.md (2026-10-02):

---
doc_id: MPL-DDR-002
title: MachinePulse recommendations accepted
project: MachinePulse
doc_type: Design decision record
version: "0.2"
status: Draft
date: '2026-10-02'
author: Amish Chadha
license: CERN-OHL-S-2.0
revisions:
- version: "0.1"
  date: '2026-09-25'
  author: Amish Chadha
  change: Record the recommendations accepted by Amish on 2026-09-25, what changed in the repo, and the items still open
- version: "0.2"
  date: '2026-10-02'
  author: Amish Chadha
  change: 'O1 and O2 decided by Amish on 2026-10-02'
---

# 0002: Recommendations accepted

- **Date:** 2026-09-25
- **Status:** accepted. Amish accepted every recommendation in this repo on 2026-09-25. Items with no recommendation stayed "Proposed, awaiting Amish" until Amish decided them on 2026-10-02 ("i approve your recommendations for all 555 open decisions.").

## Context

On 2026-09-25 Amish wrote: "i accept all your recommendations, go with them across all repos." Before that, MachinePulse held ten items adopted for TRL 3 work and open for his review (MPL-DDR-001, D1 to D10), three new proposals from the TRL 3 calculations (`docs/REVIEW.md`, session "TRL 3", items 3 to 5) and two items without a single recommendation (MPL-DDR-001, O1 and O2).

## Options considered

The options for each item are those in `docs/REVIEW.md` (sessions "/populate" and "TRL 3") and in MPL-DDR-001. Where a recommendation named one of several options, that option is the decision.

## Decision

*Table 1. Items decided by Amish, 2026-09-25: go with recommendation.*

| # | Item | Decision | What changed in the repo |
| --- | --- | --- | --- |
| D1 | Radio | Wi-Fi on the ESP32-S3 first; LoRaWAN summaries through FieldNode a later option | Status wording only (MPL-DDR-001 v0.2, MPL-PRC-001 v0.4) |
| D2 | Power | Certified 5 V USB adapter | Status wording only |
| D3 | Accelerometer | IIS3DWB class, ADXL345 class as documented fallback | Status wording only |
| D4 | Current sensing | One CT on one phase | Status wording only (MPL-PRB-001 v0.4) |
| D5 | Alert logic | First-week baseline per load band; flags to a person | Status wording only |
| D6 | Data home | TwinKit gateway, any MQTT broker, no cloud | Status wording only |
| D7 | Enclosure | Stock IP54 ABS box on 5 mm nylon stand-offs | Status wording only |
| D8 | Pilot site | A makerspace or university workshop with a lathe and a compressor | Status wording only (MPL-PRB-001 v0.4); choosing the actual site and running the pilot are TRL 4 work, on hold |
| D9 | Budget | No change at the time; superseded in effect by N1 | See N1 |
| D10 | Data schedule | Features every minute, a spectrum every 15 min | Status wording only |
| N1 | Magnets for hot frames (R12) | Option (b): high-temperature pot magnets rated 120 °C or more, about $1.00 more for the pair | `cad/src/model.py` gains `mag_t_max` = 120 °C (geometry unchanged); STEP and STL re-exported; BOM line 6 from $3.50 to $4.00 each, parts from $80.00 to $81.00; `budget_usd` from 80 to 81; GA MPL-DWG-001 from Rev P1 to Rev P2 (magnet note); MPL-CAL-001 v0.2: hot-frame limit from 81.3 °C (magnets) to 109.6 °C (accelerometer), R12 from at risk to met by calculation; R16 target from $80 to $81 in MPL-REQ-001 v0.4 |
| N2 | R8 range | Restate R8 as within 2 °C from 0 to 85 °C and within 4 °C from 85 to 100 °C | MPL-REQ-001 v0.4; R8 from at risk to met by calculation (1.69 K at 85 °C, 3.59 K at 100 °C) |
| N3 | R3 and R5 follow-up | Keep both targets; measure the ADC residual and the mount resonance first at TRL 4; consider a flat steel saddle for curved frames | Targets unchanged; noted in MPL-CAL-001 v0.2 and MPL-PRC-001 v0.4. The measurements and any saddle design are TRL 4 work, decided but on hold |

*Table 2. Items left open on 2026-09-25, decided by Amish on 2026-10-02.*

| # | Item | Status |
| --- | --- | --- |
| O1 | Co-design partner for the alerts and dashboard. No recommendation was made. | Decided by Amish, 2026-10-02: the makerspace pilot already decided, with its shop lead deciding what "changed" should mean, and the maintenance person of one small production machine shop as a second voice |
| O2 | How to treat R4 with one CT: accept at risk with a power factor curve, relax to "relative energy trend", or add a voltage reference ($10, parts $91.00). The recommendation offered two courses without choosing one, so no option is taken. | Decided by Amish, 2026-10-02: (b), R4 restated as a relative energy trend for the first build, with any kWh figure reported as an estimate; the voltage reference (c) stays an option for sites that need absolute energy |

## Consequences

- Requirement status (MPL-CAL-001 v0.2): 1 not met (R10), 4 at risk (R3, R4, R5, R16), 9 met by calculation, 3 met by design. Before: 1 not met, 6 at risk, 7 met by calculation, 3 met by design.
- `project.yaml`: `budget_usd` from 80 to 81; `trl` and `trl_target` stay 3. No reworded pitch or problem was recommended, so those lines are unchanged.
- Controlled documents revised: MPL-PRB-001 v0.4, MPL-PRC-001 v0.4, MPL-REQ-001 v0.4, MPL-CAL-001 v0.2, MPL-DDR-001 v0.2; drawing MPL-DWG-001 Rev P2; concept media regenerated.
- Cross-repo actions: none required. The decisions do not change any interface with TwinKit, FieldNode or CalRig.
- TRL 4 is on hold by Amish's instruction. Nothing in this record authorizes building, testing or buying parts.

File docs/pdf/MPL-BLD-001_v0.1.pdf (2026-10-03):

M AC H I N E P U L S E · B U I L D P L A N

# MachinePulse prototype build plan

Design Molecule Lab · designmolecule.com

D O C U M E N T CO N T RO L

Document ID | MPL-BLD-001 | Version | 0.1
Status | Draft | Date | 2026-10-01
Author | Amish Chadha | License | CERN-OHL-S-2.0
Project TRL | TRL 3 | Proof of concept
Repository | github.com/BoujeeEnjinia1701/machinepulse
Source | docs/05-build-plan.md @ uncommitted

R EV I S I O N H I STO RY

Version | Date | Author | Change
0.1 | 2026-10-01 | Amish Chadha | First build plan, with pictures by component and step; design made constructable (MPL-DDR-003)

D R A F T · N O T F O R F A B R I C A T I O N

## MachinePulse prototype build plan

Plan, not yet built. How to build the first proof-of-concept prototype, component by component. Building and testing to it is TRL 4 work. Decisions still to be made are kept in the design decisions register (docs/06-design-decisions.md), not here.

### 1. What you are building


Figure 1. Every component pulled apart and numbered in build order: the pod in the middle, the probe and its clip in front, the current transformer to the right.
The prototype is one MachinePulse kit for one machine: a small pod that holds onto the motor frame with two pot magnets, a temperature probe held on the frame by its own magnetic clip, and a split-core current transformer that closes round one insulated supply conductor. Inside the pod, an aluminium block carries the magnets and a short round boss; the vibration sensor is bonded to the top of the boss, and a stock plastic box stands 5 mm clear of the block on four nylon stand-offs, holding a hand-wired carrier board and the controller. Figure 1 shows the 17 components in the order you make or fit them. Four are made in a small workshop: the sensor block, the boss, the carrier board and the probe clip; the box base and lid are bought and drilled. Everything else is bought and fitted. The work is sawing, filing, drilling and tapping aluminium plate and bar, drilling a plastic box, soldering a perfboard and bonding two small parts with epoxy. The parts cost about USD 83.50 from the bill of materials.
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

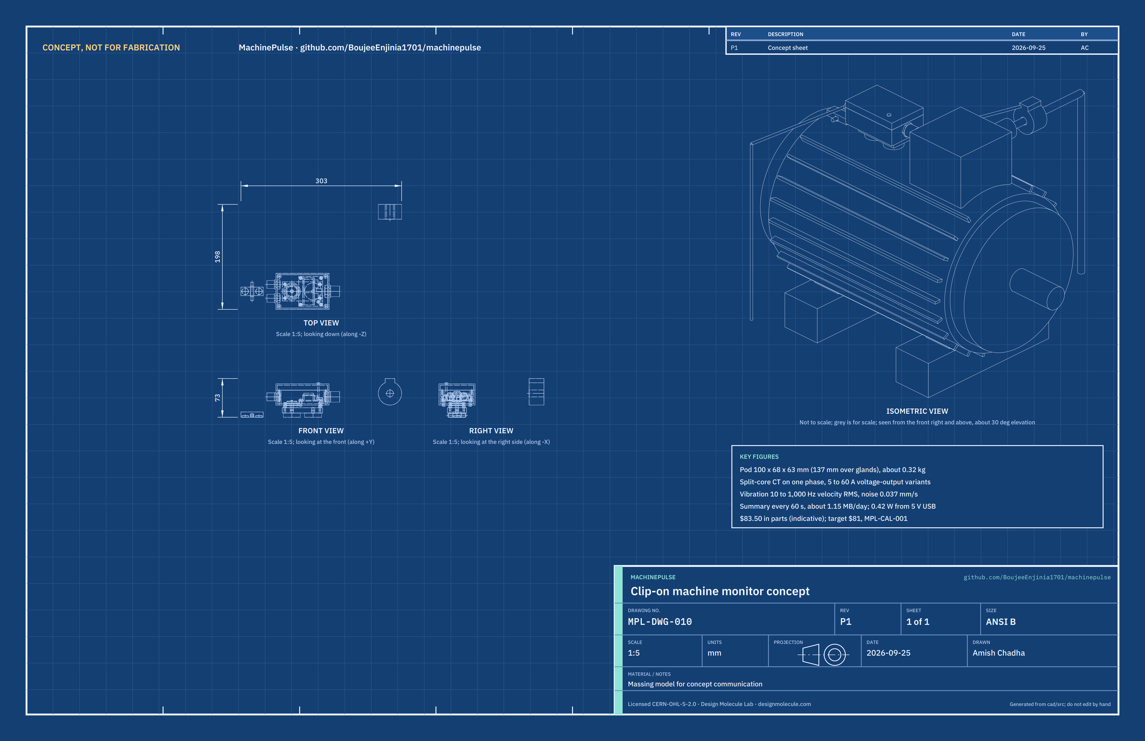
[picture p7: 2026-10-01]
media/concept-blueprint.png

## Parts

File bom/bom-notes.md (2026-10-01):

# BOM notes

- Line numbers 1 to 9 and 12 to 14 match the numbered callouts in `media/exploded.png` and the parts in `cad/src/model.py`. Lines 10 and 11 are not shown in the model. Line 12 is shown by the grommet, the set screw, the nylon screws and the carrier stand-offs and screws.
- Every line is priced. Prices are indicative single-unit prices in USD from typical online and distributor listings in September 2026. They are estimates, not quotes.
- Value-engineering target: USD 81 (`budget_usd` in `project.yaml`, a hypothetical control target, not a limit). Estimated cost of the constructable design: USD 83.50 (USD 2.50 over the target) (MPL-CAL-001 v0.3, section J). Making the design constructable (MPL-DDR-003) added $2.50: lines 2 (+$0.50, third gland and an M16 gland), 7 (+$1.00, sockets, terminals and light pipe), 9 and 14 (+$0.50 net, a made clip in place of a bought one) and 12 (+$0.50, grommet, set screw and carrier fixings).
- Not included: the TwinKit gateway or any other MQTT broker (a separate lab project, costed there); extra CTs for the other two phases (about $10 each, total $103.50); and a voltage reference (about $10, total $93.50).
- Line 3: choose a module without octal PSRAM. Common boards with octal PSRAM use modules rated to 65 °C, which leaves little margin on hot frames (MPL-CAL-001, G4).
- Line 4 (IIS3DWB-class accelerometer) is the least certain price and availability. An ADXL345-class breakout (about $6) is cheaper but misses R6 (0.20 mm/s against 0.1 mm/s).
- Line 8: order the CT range per machine (5 to 60 A, voltage output) so that normal load sits above about 30 % of its range. Never use a current-output type.
- Line 10 must be a certified adapter carrying the local safety mark. Do not substitute an unmarked adapter.
- Line 11: pads are costed for every pod, although only aluminium-frame machines need them; they are 3 mm thick so that the magnets keep about 75 % of their pull.
- Line 2: the M16 gland for the CT lead is chosen so the CT's 3.5 mm plug passes through its seal; check this on the parts bought. The probe and power leads each have their own M12 gland, because a single-hole seal does not seal two cables.
- Line 10: the far plug of the USB cable is cut off and the two power wires go through the power gland to the carrier board's 5 V terminal; the adapter itself stays a certified unit.
- Line 14: the probe clip is made from an aluminium offcut; its magnets must be a high-temperature grade (150 °C or more) because the clip sits on the frame.

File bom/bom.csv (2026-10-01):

item | qty | spec | supplier | unit_cost_usd | make_buy | notes
1 Enclosure lid, drilled | 1 | Lid of IP54 ABS box, 100 x 68 x 40 mm overall (lid 12 mm), with the box's four lid screws; one 3.2 mm hole for the light pipe | Electrical wholesaler or online retailer | 3.50 | buy | Indicative price; box cost split between lines 1 and 2; check the box's continuous-use temperature (70 degC assumed in MPL-CAL-001)
2 Enclosure base, drilled, with cable glands | 1 | Base of the same box (28 mm) with four moulded corner pillars; drilled for the 24 mm boss hole, four 3.2 mm stand-off screw holes, four 3.2 mm carrier screw holes, one 16.2 mm and two 12.2 mm gland holes; one M16 IP68 nylon gland (cable 4 to 8 mm) for the CT lead and two M12 IP68 glands (cable 3 to 6.5 mm) for the probe and power leads | Electrical wholesaler or online retailer | 6.00 | buy | Indicative price; was 5.50 with two M12 glands; the M16 gland lets the CT's 3.5 mm plug pass its seal (MPL-DDR-003)
3 Controller module board | 1 | ESP32-S3 module board, 8 MB flash, no octal PSRAM (module rated to 85 degC), USB-C, Wi-Fi and BLE, about 51 x 22 mm | Espressif distributor or online retailer | 9.00 | buy | Indicative price; module variants with octal PSRAM are rated to 65 degC only (MPL-CAL-001 G4)
4 Vibration accelerometer | 1 | IIS3DWB-class 3-axis MEMS, dc to 6 kHz, 75 ug/sqrt(Hz), SPI, set to +-16 g, on an 18 x 18 mm adapter board | Electronics distributor (ST adapter board or third-party breakout) | 15.00 | buy | Estimate; breakout availability unverified; ADXL345-class fallback about $6 misses R6
5 Aluminium sensor block and boss | 1 | Block: 6061 or scrap aluminium plate 76 x 36 x 10 mm, tapped M6 through at the two magnets and M3 through at the four stand-offs. Boss: 20 mm aluminium round bar, 11 mm long, tapped M6 8 deep in its base. Joined by an M6 x 12 set screw (line 12) | Self | 4.00 | make | Material cost only; hand tools and a drill press; the boss is a separate piece so no lathe is needed (MPL-DDR-003)
6 Pot magnets | 2 | 32 mm high-temperature neodymium pot magnet (rated 120 degC or more) with M6 threaded stud, about 290 N rated pull | Hardware or online retailer | 4.00 | buy | Indicative price; high-temperature grade per MPL-DDR-002 (was 3.50 standard 80 degC grade); pull on painted curved frames estimated in MPL-CAL-001 E
7 Carrier board | 1 | Perfboard cut to 45 x 56 mm carrying the interface circuit (CT bias divider 1.50 V and RC filter, series resistor and clamp diodes on the CT input), a 3.5 mm jack socket for the CT, a 2-way screw terminal for 5 V in, a 3-way screw terminal for the probe, a status LED with a 3 mm light pipe 29 mm long, a push button and two 1 x 20 female header sockets for the controller | Self (parts from an electronics distributor) | 6.00 | make | Components and board; no custom PCB at this stage; was 5.00 for two separate boards; header sockets, terminals and light pipe added (MPL-DDR-003)
8 Split-core current transformer | 1 | YHDC SCT-013 family, voltage output (1 V at rated current), 13 mm aperture, range chosen per machine (5 to 60 A; 30 A for the design case) | Online retailer | 10.00 | buy | Indicative price; never a current-output type such as the 100 A SCT-013-000
9 Surface temperature probe | 1 | DS18B20 in 6 mm stainless sleeve 34 mm long, 1 m lead with bare ends, and a 6 x 20 x 0.5 mm thermal pad | Online retailer | 3.00 | buy | Indicative price; the clip is now line 14 (MPL-DDR-003)
10 USB power supply and cable | 1 | Certified 5 V 1 A plug-in adapter with a USB-A socket and a 2 m USB-A cable; the far plug is cut off and the two power wires go through the power gland to the carrier's 5 V terminal | Local retailer | 8.00 | buy | Not shown in the model; the adapter must carry a local safety mark
11 Steel adhesive mounting pads | 2 | 35 mm diameter x 3 mm mild steel discs with two-part epoxy, for aluminium-frame motors | Hardware store or metal stockist | 2.00 | buy | Not shown in the model; indicative price; 3 mm thickness sized in MPL-CAL-001 E5
12 Hardware and consumables | 1 | Silicone grommet for a 24 mm hole in 2.5 mm panel with a 20 mm bore; M6 x 12 set screw; four M3 x 12 nylon pan-head screws; four M3 x 5 hex stand-offs with eight M3 x 6 screws; medium threadlocker; rigid two-part epoxy; high-temperature epoxy; wire, heat shrink, cable ties | Hardware store | 3.50 | buy | Indicative price; was 3.00 with a moulded boot; the grommet, set screw and carrier fixings are added (MPL-DDR-003)
13 Insulating stand-offs | 4 | Nylon spacers, 6 mm diameter, 3.2 mm bore, 5 mm long, between block and box floor (their M3 nylon screws are in line 12) | Hardware or electronics retailer | 0.25 | buy | Indicative price; thermal break sized in MPL-CAL-001 G
14 Probe clip | 1 | Aluminium bar offcut 42 x 16 x 10 mm with a 6.2 mm wide, 6.5 mm deep groove across it and two 12.2 mm pockets 3 mm deep, holding two 12 x 3 mm high-temperature neodymium discs (rated 150 degC or more) | Self (magnets from an online retailer) | 2.50 | make | New line; replaces the bought magnetic clip in line 9, which held the sleeve clear of the frame (MPL-DDR-003)

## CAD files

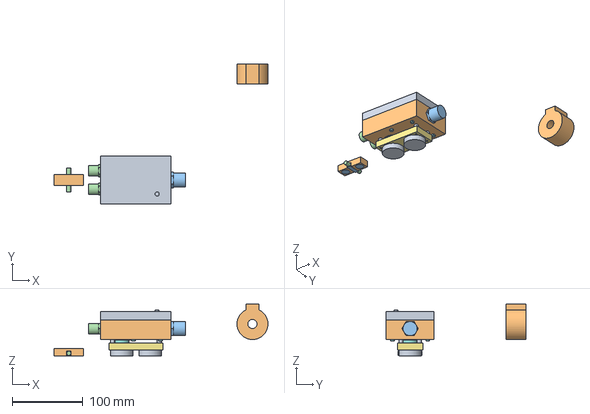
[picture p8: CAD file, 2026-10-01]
cad/step/machinepulse-assembly.step
303.0 x 198.0 x 73.0 mm

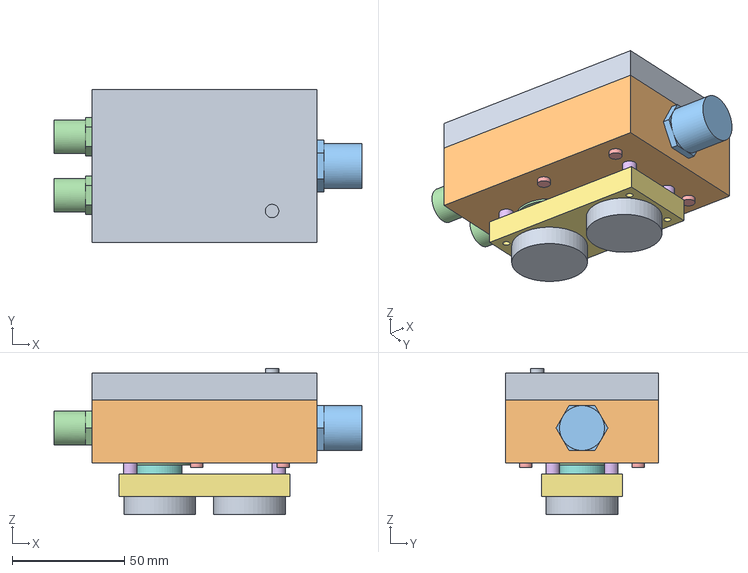
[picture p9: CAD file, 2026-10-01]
cad/step/machinepulse-pod.step
137.0 x 68.0 x 65.0 mm

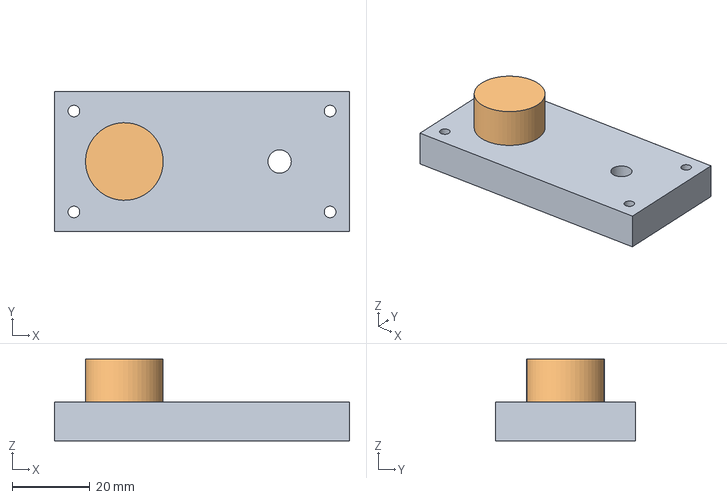
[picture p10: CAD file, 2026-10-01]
cad/step/sensor-block.step
76.0 x 36.0 x 21.0 mm

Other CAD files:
cad/stl/machinepulse-assembly.stl
cad/stl/machinepulse-pod.stl
cad/stl/sensor-block.stl

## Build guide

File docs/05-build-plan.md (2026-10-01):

---
doc_id: MPL-BLD-001
title: MachinePulse prototype build plan
project: MachinePulse
doc_type: Build plan
version: "0.1"
status: Draft
date: '2026-10-01'
author: Amish Chadha
license: CERN-OHL-S-2.0
revisions:
  - version: "0.1"
    date: '2026-10-01'
    author: Amish Chadha
    change: First build plan, with pictures by component and step; design made constructable (MPL-DDR-003)
---

# MachinePulse prototype build plan

**Plan, not yet built.** How to build the first proof-of-concept prototype, component by component. Building and testing to it is TRL 4 work. Decisions still to be made are kept in the design decisions register ([docs/06-design-decisions.md](06-design-decisions.md)), not here.

## 1. What you are building

Figure 1. Every component, pulled apart and numbered in build order

*Figure 1. Every component pulled apart and numbered in build order: the pod in the middle, the probe and its clip in front, the current transformer to the right.*

The prototype is one MachinePulse kit for one machine: a small pod that holds onto the motor frame with two pot magnets, a temperature probe held on the frame by its own magnetic clip, and a split-core current transformer that closes round one insulated supply conductor. Inside the pod, an aluminium block carries the magnets and a short round boss; the vibration sensor is bonded to the top of the boss, and a stock plastic box stands 5 mm clear of the block on four nylon stand-offs, holding a hand-wired carrier board and the controller. Figure 1 shows the 17 components in the order you make or fit them. Four are made in a small workshop: the sensor block, the boss, the carrier board and the probe clip; the box base and lid are bought and drilled. Everything else is bought and fitted. The work is sawing, filing, drilling and tapping aluminium plate and bar, drilling a plastic box, soldering a perfboard and bonding two small parts with epoxy. The parts cost about USD 83.50 from the bill of materials.

> **Safety:** The current transformer goes round a conductor that carries mains voltage. It is fitted only with the machine isolated and locked off, only round a single insulated conductor, and any terminal box or panel is opened only by a qualified person (section 6). Use only voltage-output current transformers. Fit and remove the pod and probe only with the machine stopped. Motor frames can be hot enough to burn. The magnets are strong: they pinch fingers and snap together, and must be kept away from pacemakers and magnetic media. Epoxy and threadlocker need gloves and ventilation. The pod itself runs only on 5 V from a certified adapter.

## 2. What changed to make it buildable

The concept showed what the pod does; some of its parts could not be made with hand tools, had no fixing, or did not touch the parts they were meant to touch. Each change below keeps what the pod does, and all of them are recorded in decision record MPL-DDR-003, open for Amish's review.

*Table 1. Changes from the concept.*

| Component | The concept had | The buildable design has | Why |
| --- | --- | --- | --- |
| Sensor block and boss | One aluminium piece with a 20 mm boss standing 11 mm proud of a 10 mm plate | A drilled and tapped plate, and a separate boss cut from round bar, held by a set screw over the left magnet (Figure 3) | No lathe or mill needed; the stiff path from frame to sensor is kept |
| Magnets | Studs with no holes to go into | Studs trimmed to 5 mm and screwed into tapped holes in the block | A fixing you can make in a drill press |
| Nylon stand-offs | No screws; 0.6 mm from the floor hole and touching the boot | Moved 3 mm outward and 1 mm back; one nylon screw each, into the block (Figure 8) | A real fixing that stays a heat break, with room for the grommet |
| Boot round the boss | A loose ring floating under the floor | A stock silicone grommet in the floor hole, gripping the boss (Figure 5) | Seals the hole with a bought part |
| Boards | Two boards floating above the floor | One carrier perfboard on four stand-offs, with the controller plugged into sockets on it (Figure 11) | Module boards of this class have no mounting holes; one board is simpler to fix |
| Cable glands | Two glands with no holes or nuts; the probe and power leads sharing one | Three glands, one lead each, set high enough that their nuts clear the floor and corner pillars (Figure 9) | A single-hole seal cannot seal two leads, and a USB plug cannot pass a gland |
| Status light | A window in the lid with nothing behind it | A light pipe from the LED on the carrier up through the lid (Figure 14) | The light reaches the outside with the box sealed |
| Accelerometer | No fixing; too big to pass the floor hole | Bonded to the boss top after the box is fitted (step 5) | A rigid bond suits vibration sensing; the order follows from its size |
| Temperature probe | The sleeve resting on top of a clip, 7 mm above the frame | A made aluminium clip with two magnets that holds the sleeve down on its thermal pad (Figure 16) | The sleeve now touches the frame, as the temperature calculation assumes |

## 3. Making the components

Make and check each component before the assembly step that needs it. Sizes are in millimetres. "Left end" is the end of the box with the probe and power glands; "right end" has the current transformer gland; "front" is the long side nearest the status light. Sizes across the pod are measured from the box's centre lines. Workshop tolerance is 0.5 mm unless a step says otherwise; drawings carry no tolerances before TRL 4.

### 3.1 Sensor block

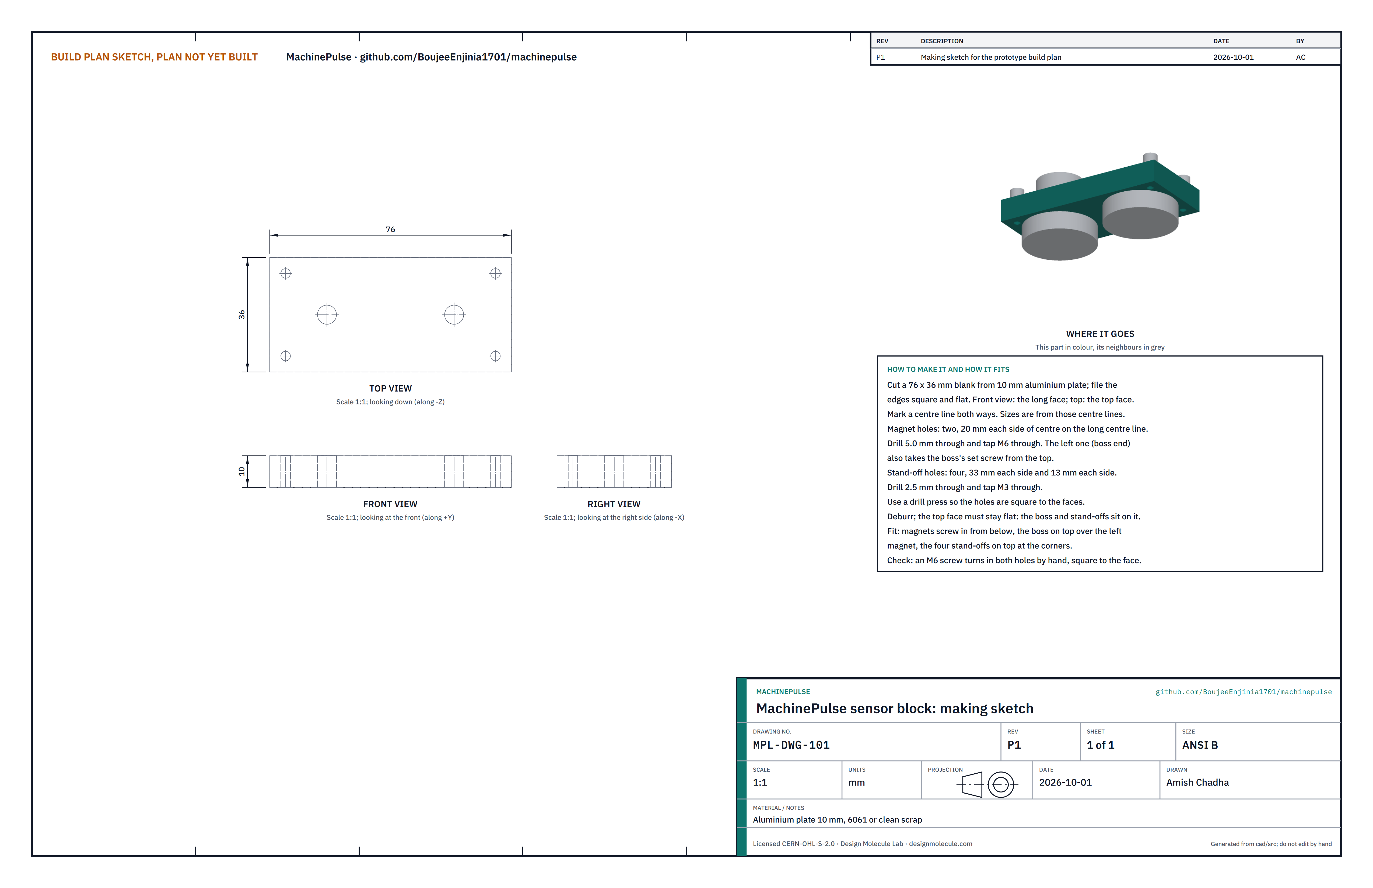
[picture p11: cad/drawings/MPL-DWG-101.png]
Figure 2. Making sketch of the sensor block


*Figure 2. Sensor block making sketch (MPL-DWG-101).*

**What it is and what it is made from.** The plate that the two magnets screw into and that carries the boss and the four nylon stand-offs. Aluminium plate 10 mm thick, 6061 class or clean scrap, cut to 76 x 36 mm.

**How to make it.**

1. Cut the blank to 76 x 36 mm and file the edges square. Keep the top face flat: the boss and stand-offs sit on it.
2. Scribe a centre line both ways.
3. Magnet holes: two, 20 mm each side of centre on the long centre line. Drill 5.0 mm right through and tap M6 right through. The left one also takes the boss's set screw from the top.
4. Stand-off holes: four, 33 mm each side of centre along the length and 13 mm each side across it. Drill 2.5 mm right through and tap M3.
5. Drill in a drill press so every hole is square to the faces. Deburr both faces.

**How it fits the parts next to it.**

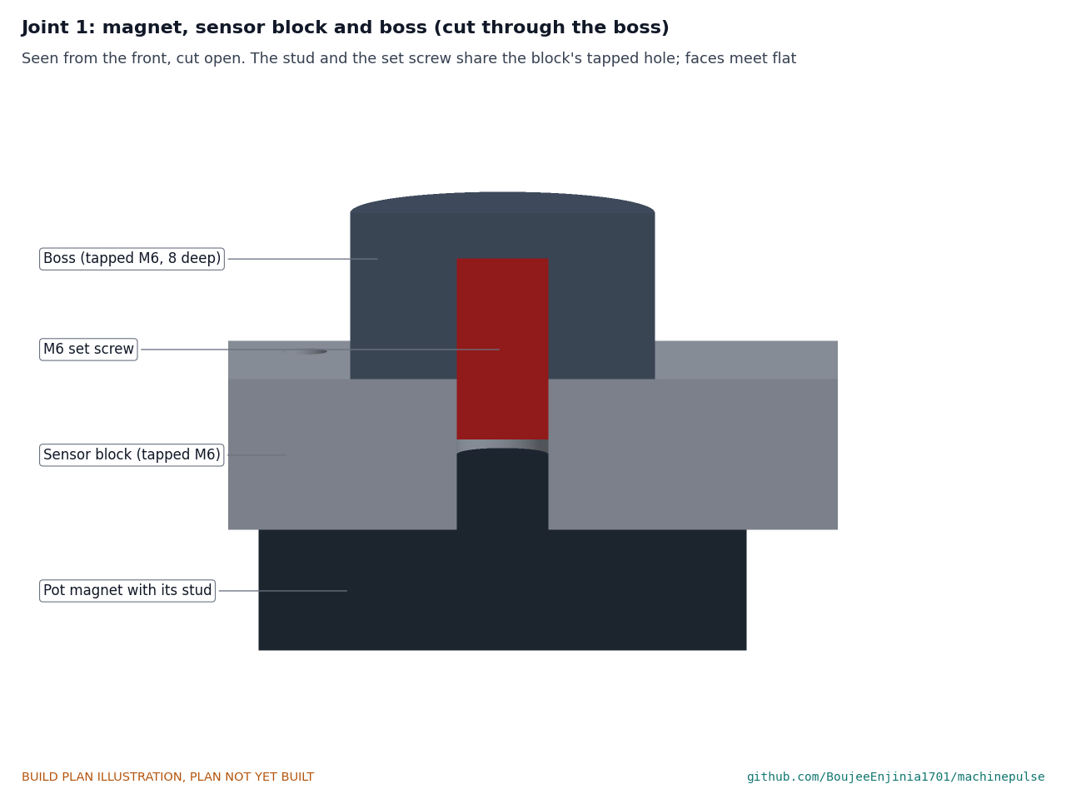
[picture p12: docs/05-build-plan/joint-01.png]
Figure 3. Joint 1: magnet, block and boss, cut through the boss


*Figure 3. The magnet's stud comes up into the left tapped hole from below; the set screw goes into the same hole from above and up into the boss. The boss face and the magnet back each sit flat on the block.*

The two magnets screw in from below with their backs flat on the underside. The boss sits flat on the top face over the left magnet. The four stand-offs sit on the top face at the corners, each held by a nylon screw that comes down through the box floor.

**Check before moving on.** An M6 screw turns into both holes by hand and stands square to the face; an M3 screw turns into all four small holes.

### 3.2 Boss

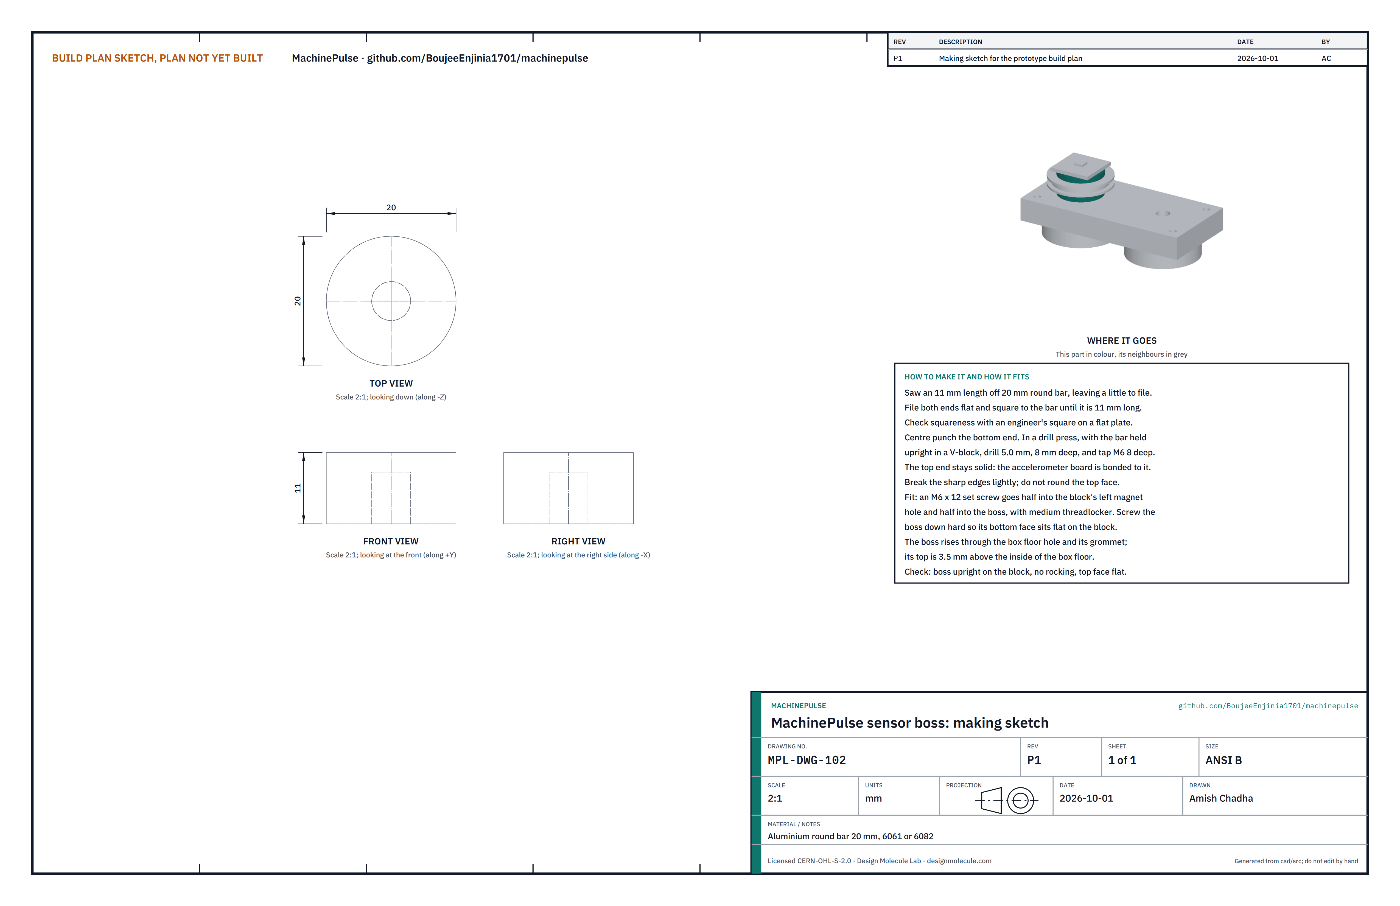
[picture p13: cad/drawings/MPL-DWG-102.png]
Figure 4. Making sketch of the boss


*Figure 4. Boss making sketch (MPL-DWG-102).*

**What it is and what it is made from.** A short round post that carries the vibration sensor up through the box floor, so that vibration reaches the sensor through metal and never through the plastic box. Aluminium round bar 20 mm, 6061 or 6082 class.

**How to make it.**

1. Saw a length a little over 11 mm off the bar.
2. File both ends flat and square to the bar until it is 11 mm long. Check against an engineer's square on a flat plate.
3. Centre punch the bottom end. With the bar held upright in a V-block in the drill press, drill 5.0 mm, 8 mm deep, and tap M6 8 mm deep.
4. Leave the top end solid and flat; break the sharp edges lightly.

**How it fits the parts next to it.** An M6 x 12 set screw with medium threadlocker goes half into the block's left tapped hole and half into the boss; screw the boss down until its bottom face sits flat on the block (Figure 3). Its top ends 3.5 mm above the inside of the box floor. It passes through the 24 mm floor hole without touching the floor; a silicone grommet in the hole grips it and seals the gap:

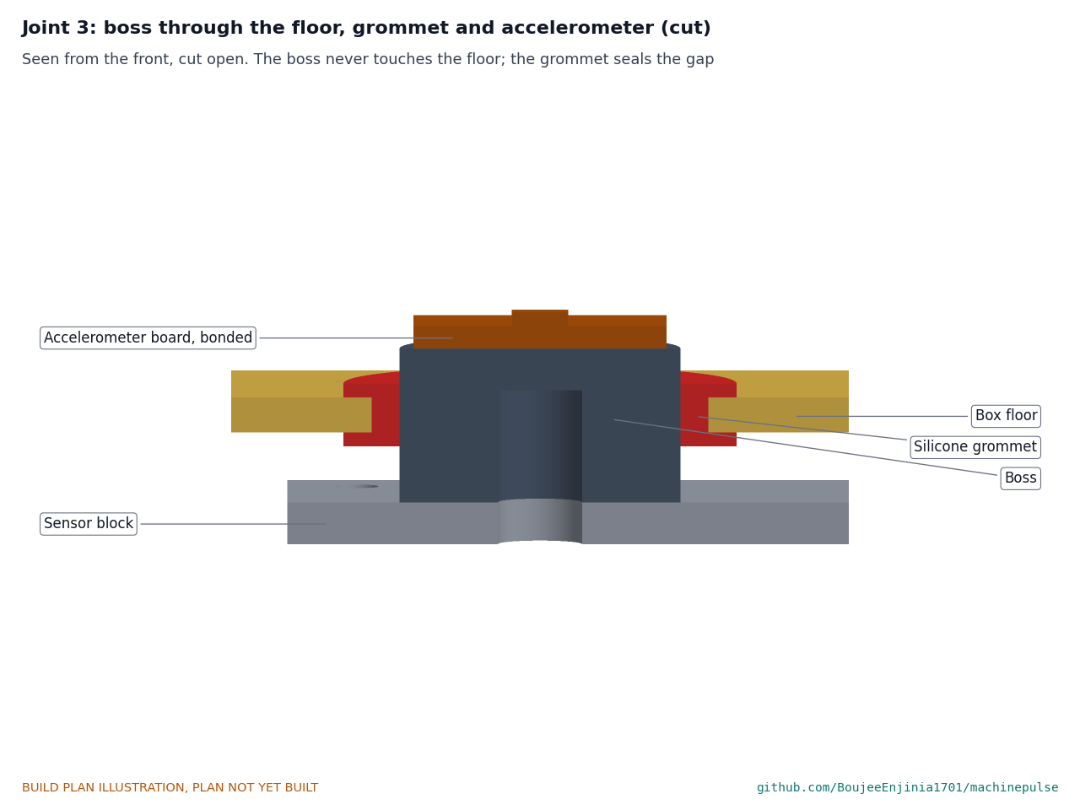
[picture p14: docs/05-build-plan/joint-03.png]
Figure 5. Joint 3: boss through the floor, grommet and accelerometer


*Figure 5. The boss rises through the grommet; the accelerometer board is bonded to its top face, 2.5 mm above the grommet.*

**Check before moving on.** The boss stands upright on the block and does not rock; its top face is flat.

### 3.3 Box base, drilled, with its glands and grommet

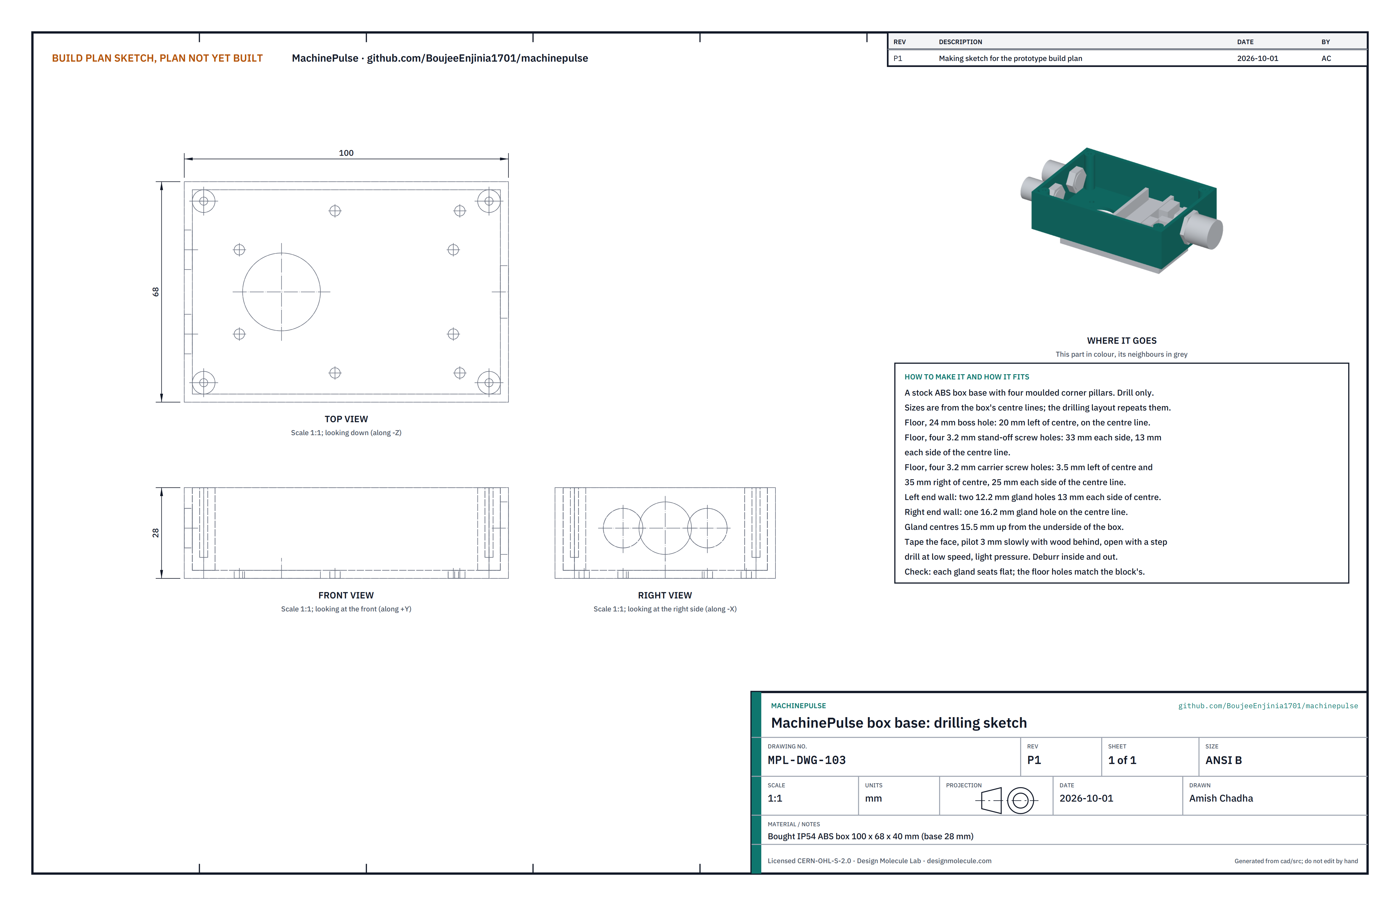
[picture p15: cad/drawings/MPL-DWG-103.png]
Figure 6. Drilling sketch of the box base


*Figure 6. Box base drilling sketch (MPL-DWG-103).*

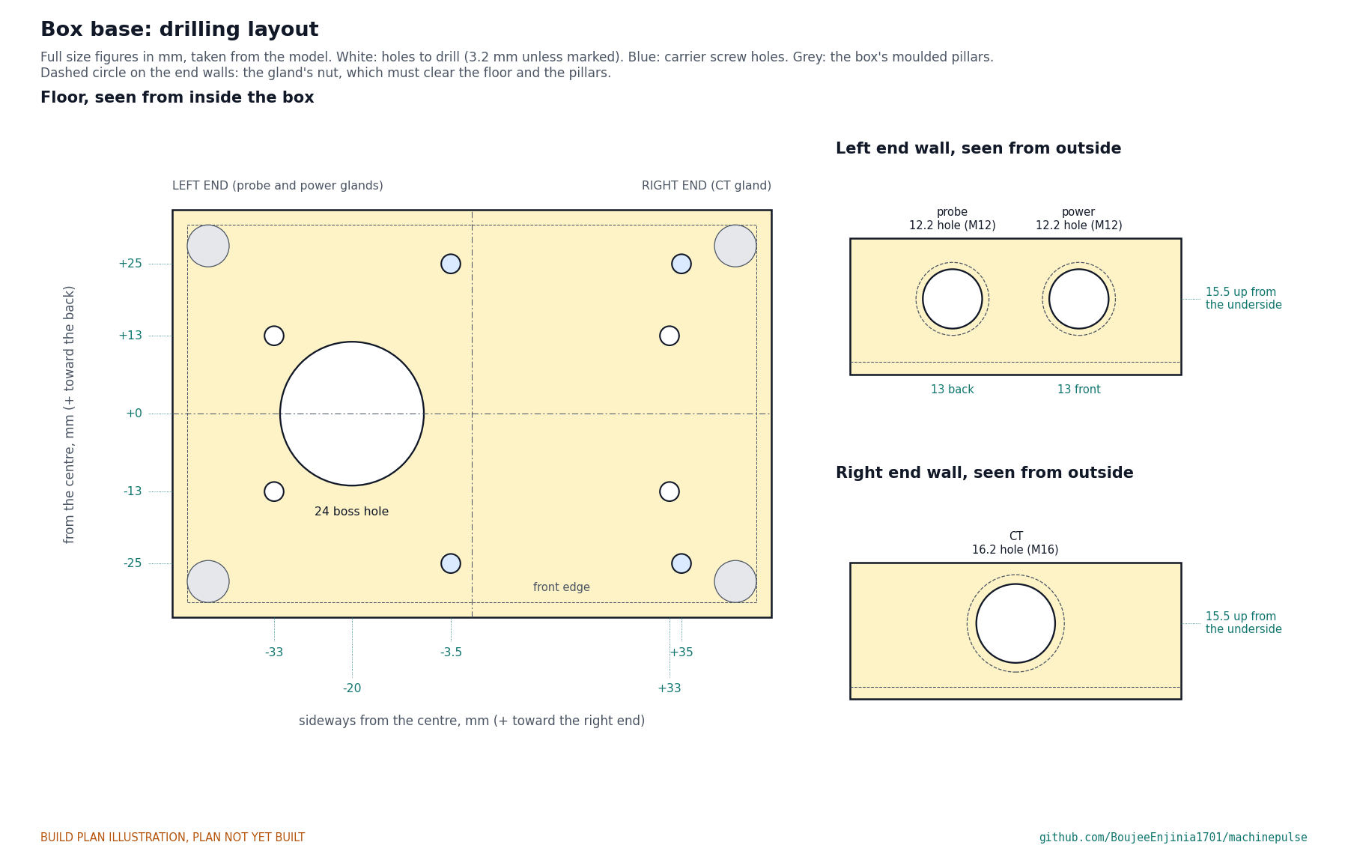
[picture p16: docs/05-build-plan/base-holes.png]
Figure 7. Drilling layout of the box base


*Figure 7. Every hole, with full size figures from the box's centre lines, and the end walls seen from outside.*

**What it is and what it is made from.** The lower part of a bought IP54 ABS box, 100 x 68 mm and 28 mm deep (the whole box is 40 mm tall with its lid), with four moulded corner pillars for the lid screws. Eleven holes are drilled in it.

**How to make it.**

1. Cover the floor and both end walls with masking tape and mark the holes from Figure 7.
2. Floor: the 24 mm boss hole, 20 mm left of centre on the centre line; four 3.2 mm stand-off screw holes, 33 mm each side of centre and 13 mm each side of the centre line; four 3.2 mm carrier screw holes, 3.5 mm left of centre and 35 mm right of centre, 25 mm each side of the centre line.
3. Left end wall: two 12.2 mm gland holes, 13 mm each side of centre. Right end wall: one 16.2 mm gland hole on the centre line. All gland centres are 15.5 mm up from the underside of the box.
4. With a block of wood behind the face, pilot drill every hole 3 mm at low speed, then open the large ones with a step drill, light pressure. Check each gland hole against the gland's datasheet before the last step.
5. Deburr inside and out and peel the tape.

**How it fits the parts next to it.** The floor sits on the four nylon stand-offs, 5 mm above the sensor block; nothing else touches the block:

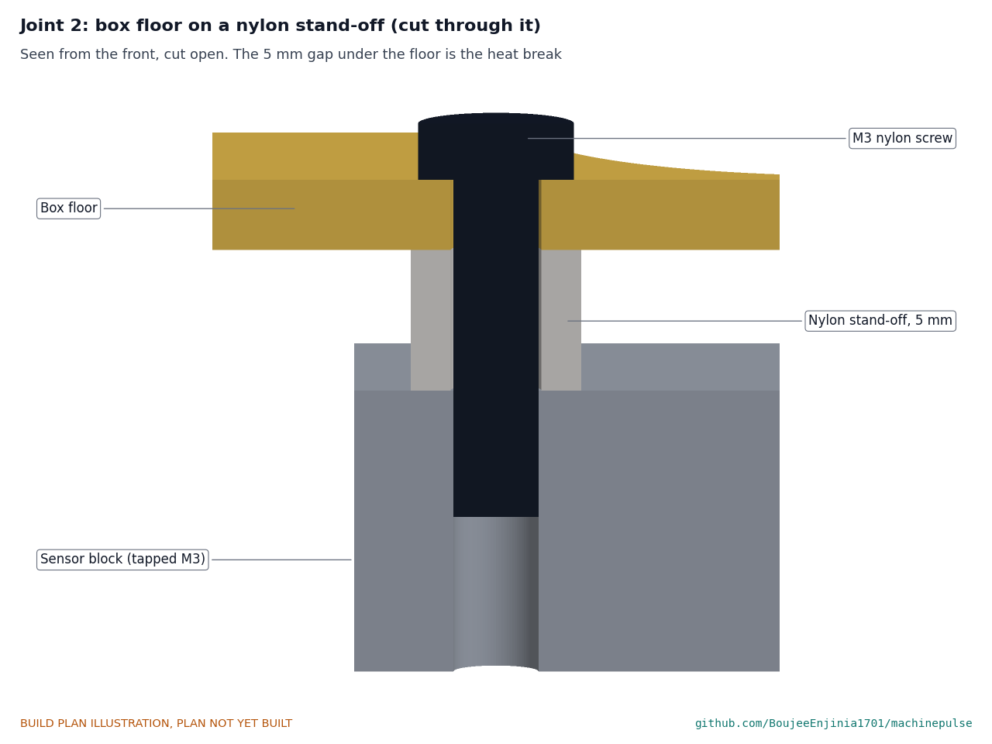
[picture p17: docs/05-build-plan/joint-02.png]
Figure 8. Joint 2: box floor on a nylon stand-off


*Figure 8. Each stand-off sits between the block and the floor, held by one nylon screw from inside the box into the block's tapped hole.*

Each gland goes in from outside with its seal and body outside and its nut inside. The nuts clear the floor and the corner pillars:

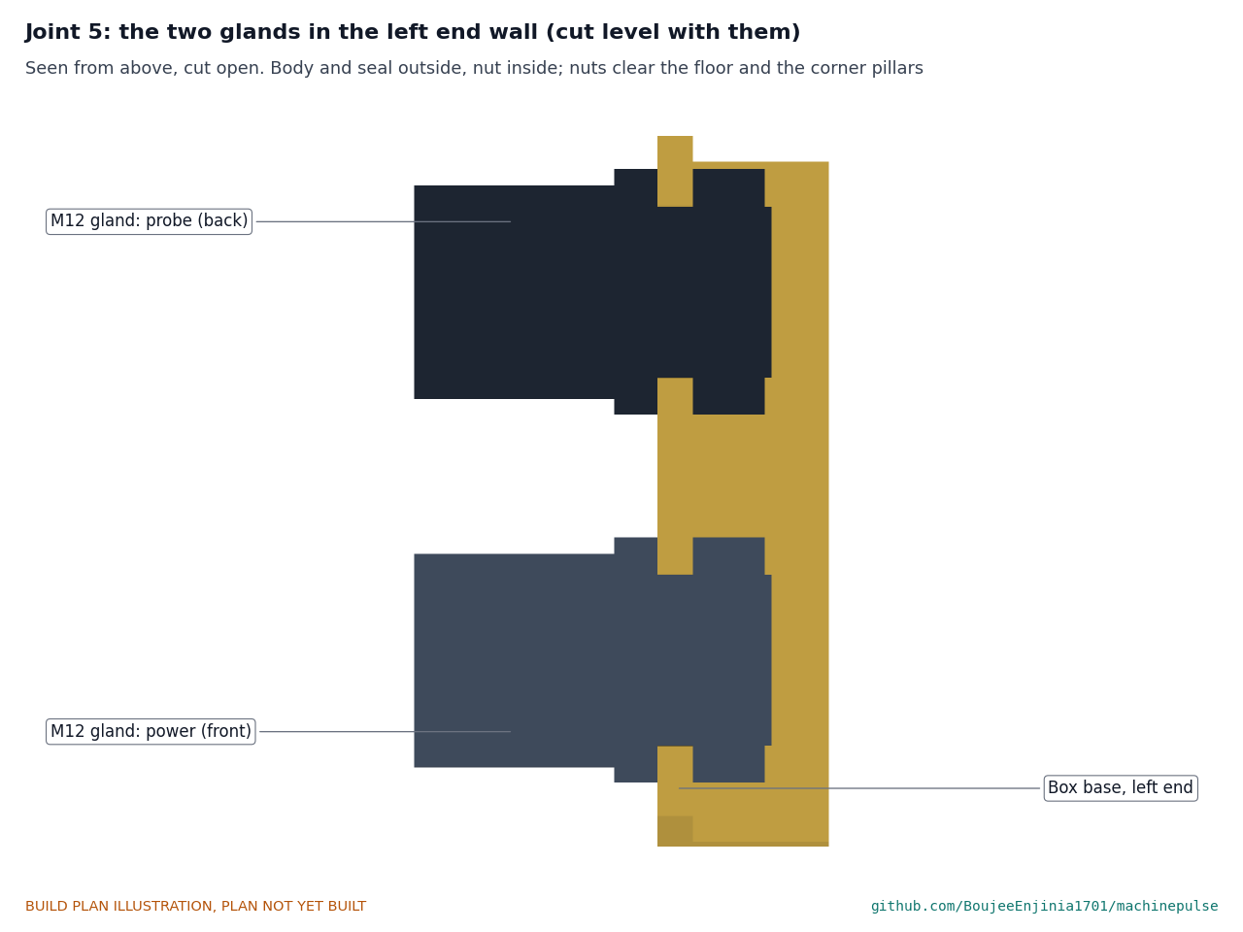
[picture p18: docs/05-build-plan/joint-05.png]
Figure 9. Joint 5: the glands in the left end wall, cut level with them


*Figure 9. The two M12 glands in the left end wall, seen from above and cut open: body outside, wall, nut inside.*

The grommet presses into the boss hole from below with one flange each side of the floor (Figure 5).

**Check before moving on.** Each gland seats flat on the wall and its nut turns down without touching a pillar; the floor's small holes line up with the block's when the two are laid together.

### 3.4 Carrier board

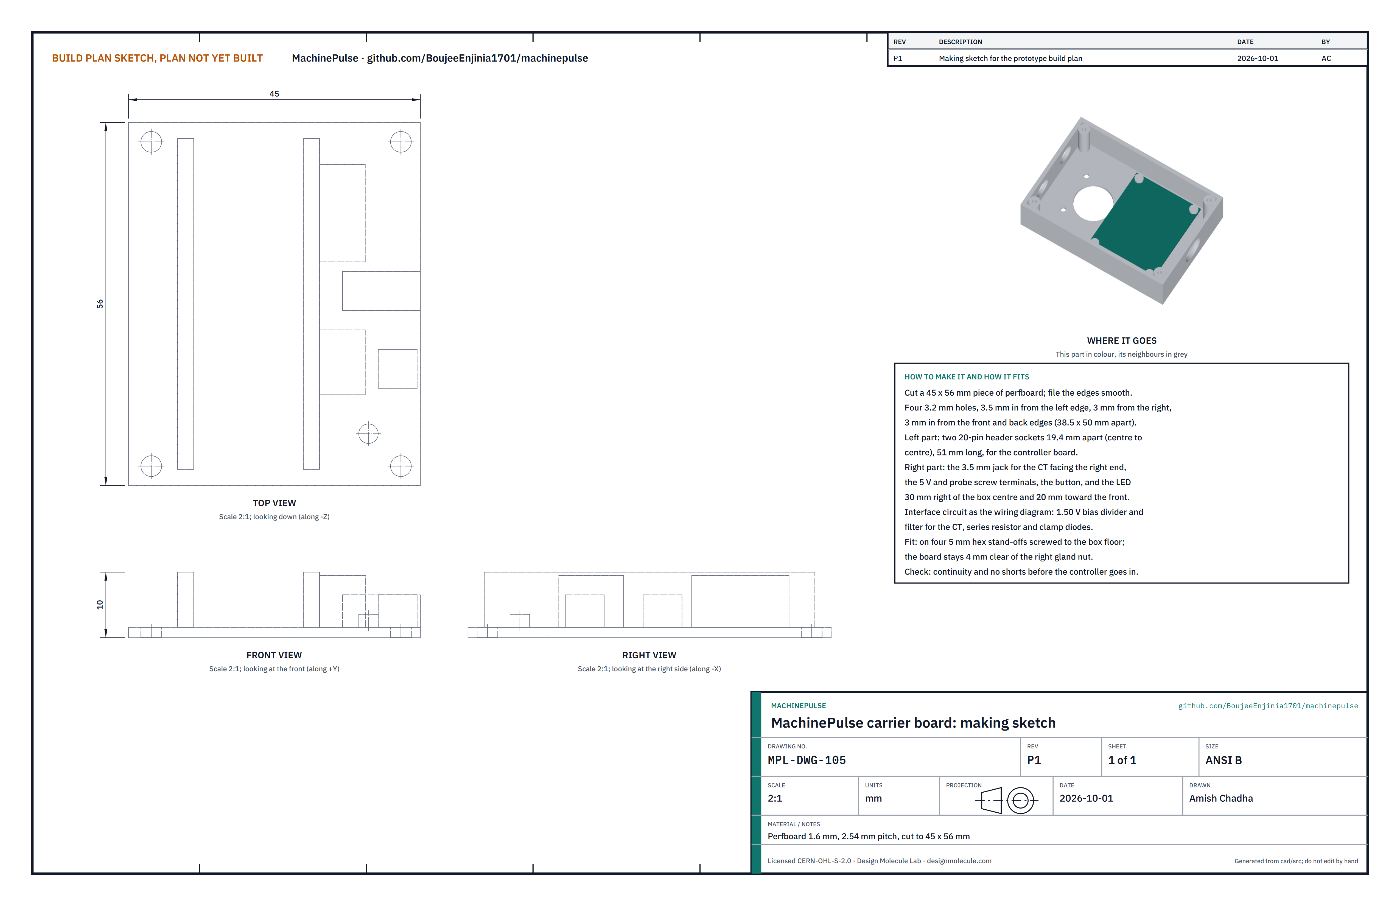
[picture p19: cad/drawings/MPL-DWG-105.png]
Figure 10. Making sketch of the carrier board


*Figure 10. Carrier board making sketch (MPL-DWG-105), with the sockets, jack, terminals, button and LED in place.*

**What it is and what it is made from.** The one board inside the box. It carries the interface circuit for the current transformer and the probe, the screw terminals the leads land on, the status LED and button, and two header sockets that the controller plugs into. Perfboard 1.6 mm thick with a 2.54 mm hole pitch, cut to 45 x 56 mm.

**How to make it.**

1. Cut the board to 45 x 56 mm and file the edges smooth.
2. Drill four 3.2 mm holes, 3.5 mm in from the left edge and 3 mm in from the right edge, 3 mm in from the front and back edges (38.5 x 50 mm apart).
3. On the left part, solder two 20-pin female header sockets, 51 mm long, 19.4 mm apart centre to centre, for the controller board.
4. On the right part, solder the 3.5 mm jack for the current transformer facing the right end, the 2-way 5 V terminal toward the front, the 3-way probe terminal toward the back, the push button, and the status LED 30 mm right of the box centre and 20 mm toward the front, so it sits under the lid's light pipe.
5. Build the interface circuit and wire the board as section 3.4.1 shows.

**How it fits the parts next to it.**

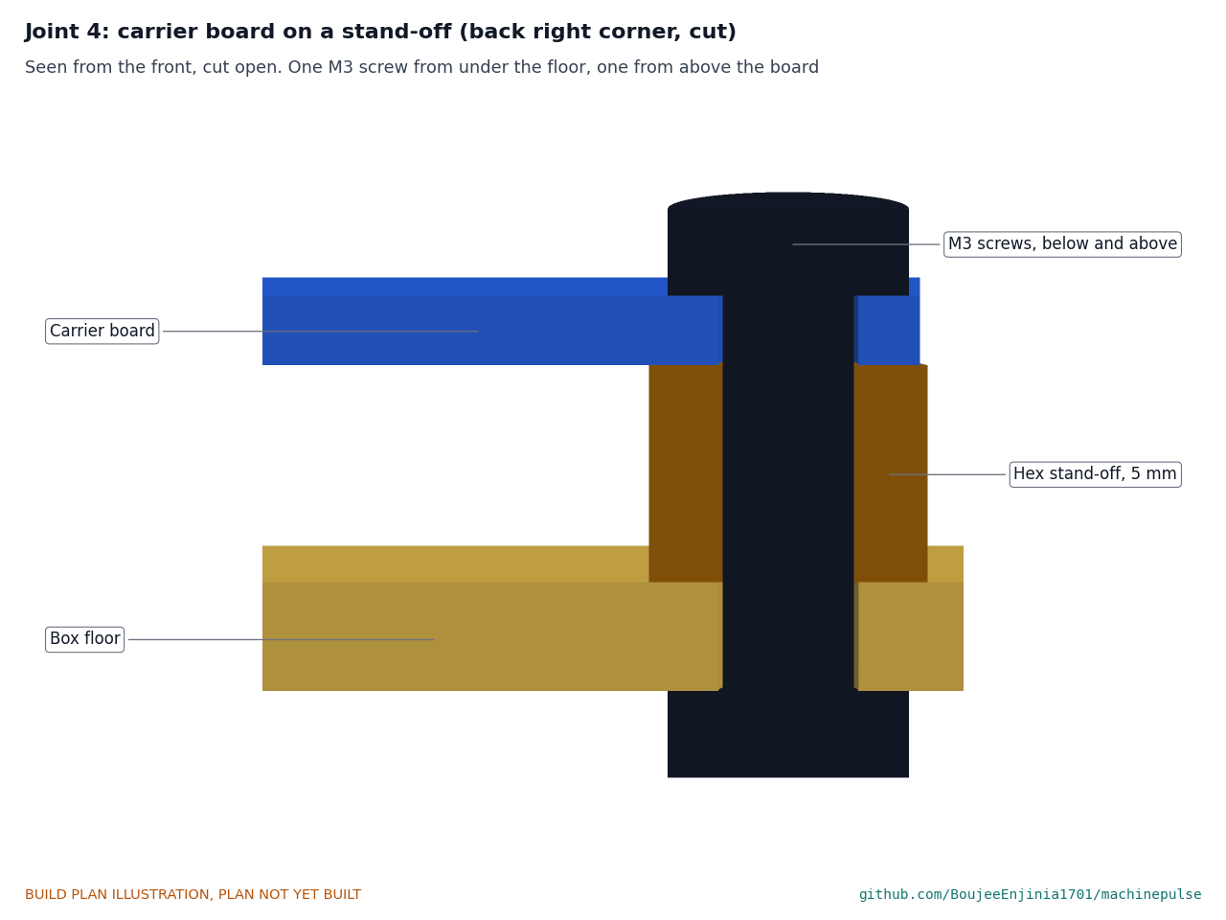
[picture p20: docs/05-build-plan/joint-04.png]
Figure 11. Joint 4: carrier board on a stand-off


*Figure 11. Each corner sits on a 5 mm hex stand-off: one M3 screw comes up through the floor into the stand-off, one comes down through the board into it.*

The board sits 5 mm above the inside of the floor, 4 mm clear of the right gland's nut and 5 mm clear of the accelerometer. The controller board presses into the sockets with its aerial end toward the back of the box.

**Check before moving on.** Every joint continues end to end; with nothing plugged in there is no short between 5 V and ground.

#### 3.4.1 Wiring

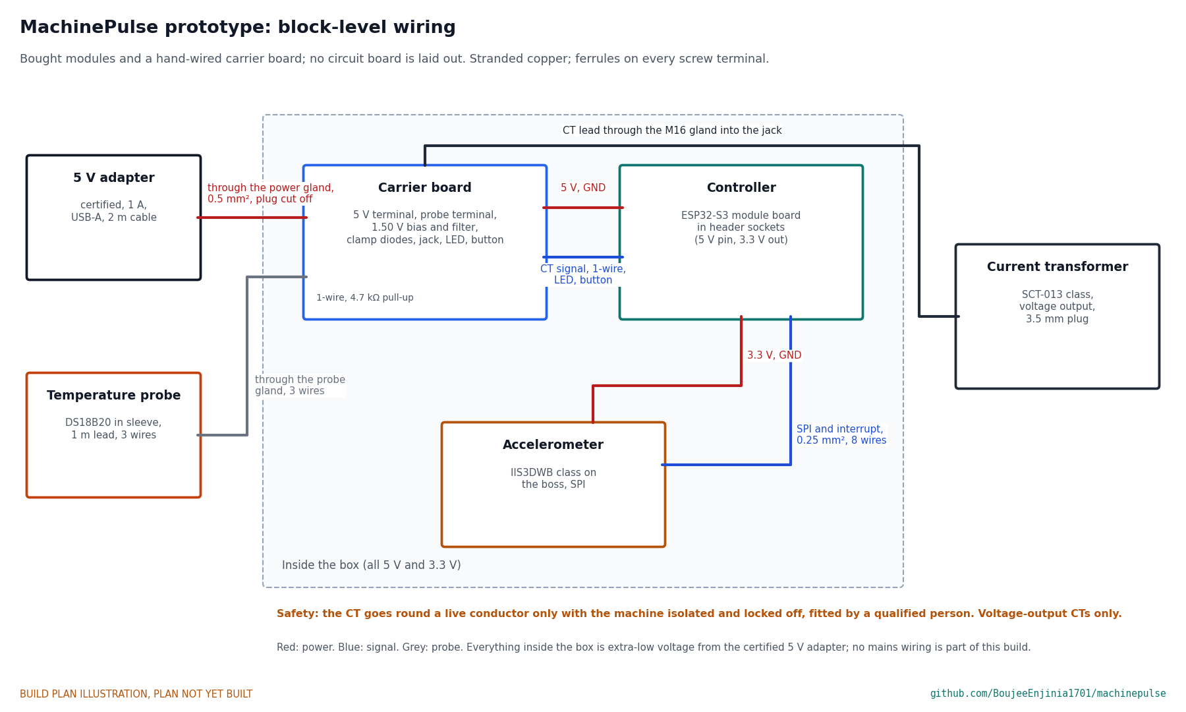
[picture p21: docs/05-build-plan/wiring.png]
Figure 12. Block-level wiring


*Figure 12. Block-level wiring with wire sizes. No circuit board is laid out at this stage; the carrier is hand-wired perfboard.*

Wire it like this, with stranded copper and a ferrule on every screw terminal:

1. Power: cut the far plug off the adapter's USB cable, pass the cable through the front left gland, and land the red and black wires (0.5 mm²) on the 5 V terminal, red to 5 V. From the terminal, run 5 V and ground to the controller's 5 V and ground pins.
2. Controller to sensors: the controller's 3.3 V output and ground feed the accelerometer and the interface circuit.
3. Current transformer: a bias divider sets 1.50 V at the controller's analog input; the jack's signal passes through a series resistor and an RC filter to that input, with clamp diodes to 3.3 V and ground.
4. Probe: pass its lead through the back left gland and land its three wires on the probe terminal; a 4.7 kΩ pull-up runs from the data wire to 3.3 V, and the data wire goes to a controller pin.
5. Accelerometer: eight thin wires (0.25 mm²), twisted in pairs, from the board on the boss to the controller's SPI and interrupt pins, with enough slack that the box can lift 2 mm without pulling them.
6. LED and button: each to a controller pin, the LED through a resistor.
7. Current transformer lead: pass the plug through the right gland's seal and plug it into the jack.

**Check before moving on.** With the adapter unplugged, 5 V and ground read open to each other; every wire is labelled; no wire crosses the boss.

### 3.5 Lid, drilled, and light pipe

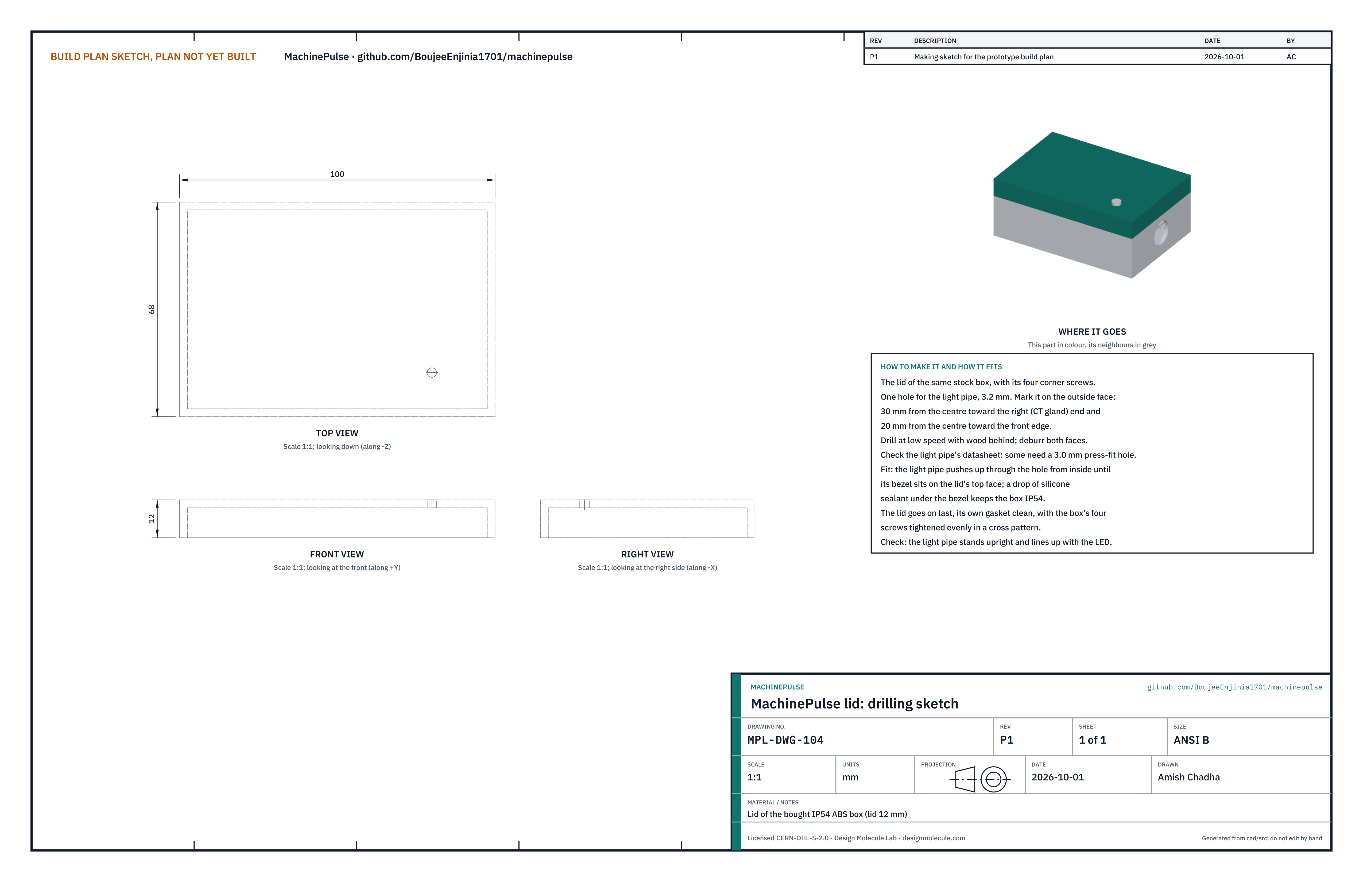
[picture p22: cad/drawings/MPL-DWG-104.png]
Figure 13. Drilling sketch of the lid


*Figure 13. Lid drilling sketch (MPL-DWG-104).*

**What it is and what it is made from.** The lid of the same stock box, 12 mm deep, with its gasket and four corner screws, drilled for the light pipe.

**How to make it.**

1. On the outside face, mark a point 30 mm from the centre toward the right end and 20 mm from the centre toward the front edge.
2. Drill 3.2 mm at low speed with wood behind, and deburr both faces. Check the light pipe's datasheet first: some need a 3.0 mm press-fit hole.

**How it fits the parts next to it.**

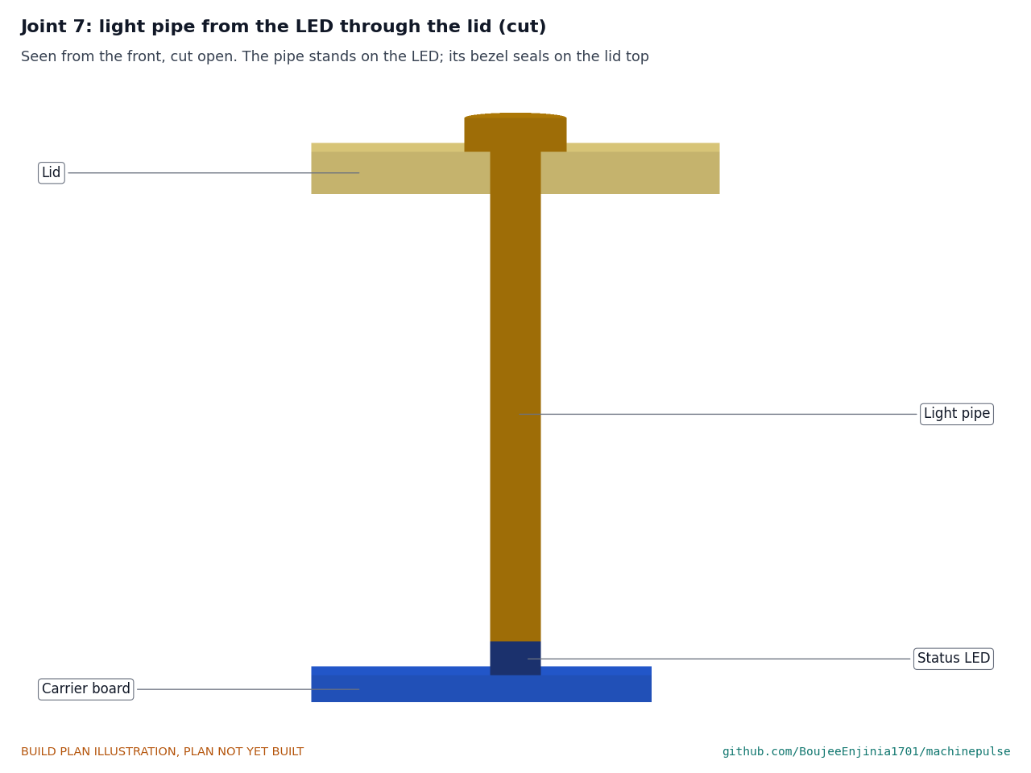
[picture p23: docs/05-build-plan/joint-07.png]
Figure 14. Joint 7: light pipe from the LED through the lid


*Figure 14. The light pipe stands on the LED and passes up through the lid; its bezel sits on the lid's top face.*

The light pipe pushes up through the hole from inside until its bezel sits on the top face; a drop of silicone sealant under the bezel keeps the box sealed. The lid closes on its own gasket with the box's four screws.

**Check before moving on.** The light pipe stands upright and lines up with the LED when the lid is held in place.

### 3.6 Probe clip

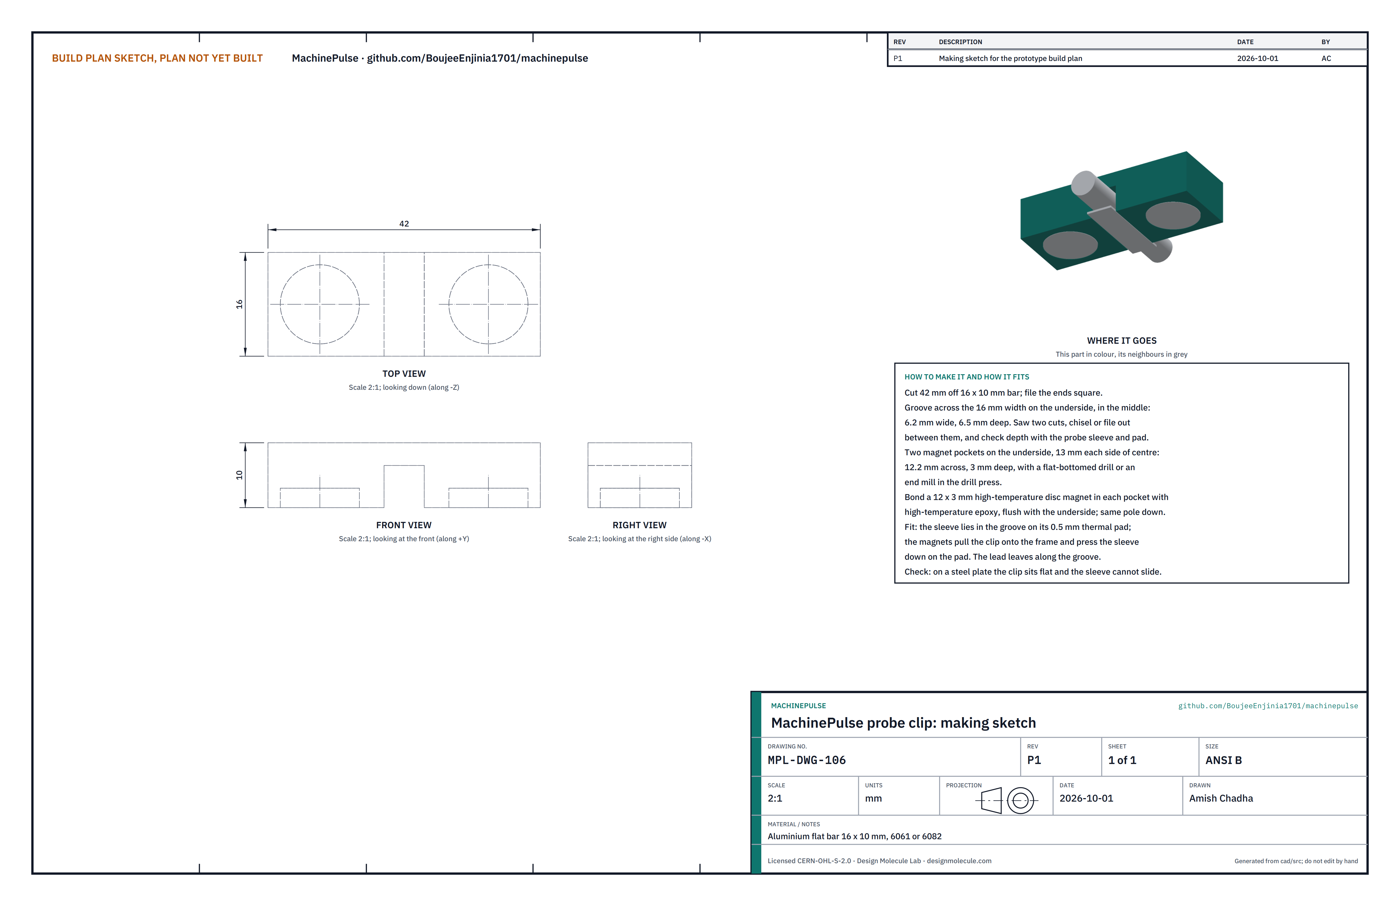
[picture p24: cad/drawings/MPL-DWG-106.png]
Figure 15. Making sketch of the probe clip


*Figure 15. Probe clip making sketch (MPL-DWG-106).*

**What it is and what it is made from.** A small magnetic block that holds the temperature probe's sleeve down on the frame near a bearing. Aluminium flat bar 16 x 10 mm, 6061 or 6082 class, with two 12 x 3 mm high-temperature neodymium disc magnets rated 150 °C or more.

**How to make it.**

1. Cut 42 mm off the bar and file the ends square.
2. On the underside, cut a groove across the 16 mm width in the middle, 6.2 mm wide and 6.5 mm deep: saw two cuts, then chisel or file out between them, checking the depth with the sleeve and pad.
3. On the underside, 13 mm each side of centre, make two flat-bottomed pockets 12.2 mm across and 3 mm deep, with a flat-bottomed drill or an end mill in the drill press.
4. Bond a magnet into each pocket with high-temperature epoxy, flush with the underside and with the same pole facing down (step 11).

**How it fits the parts next to it.**

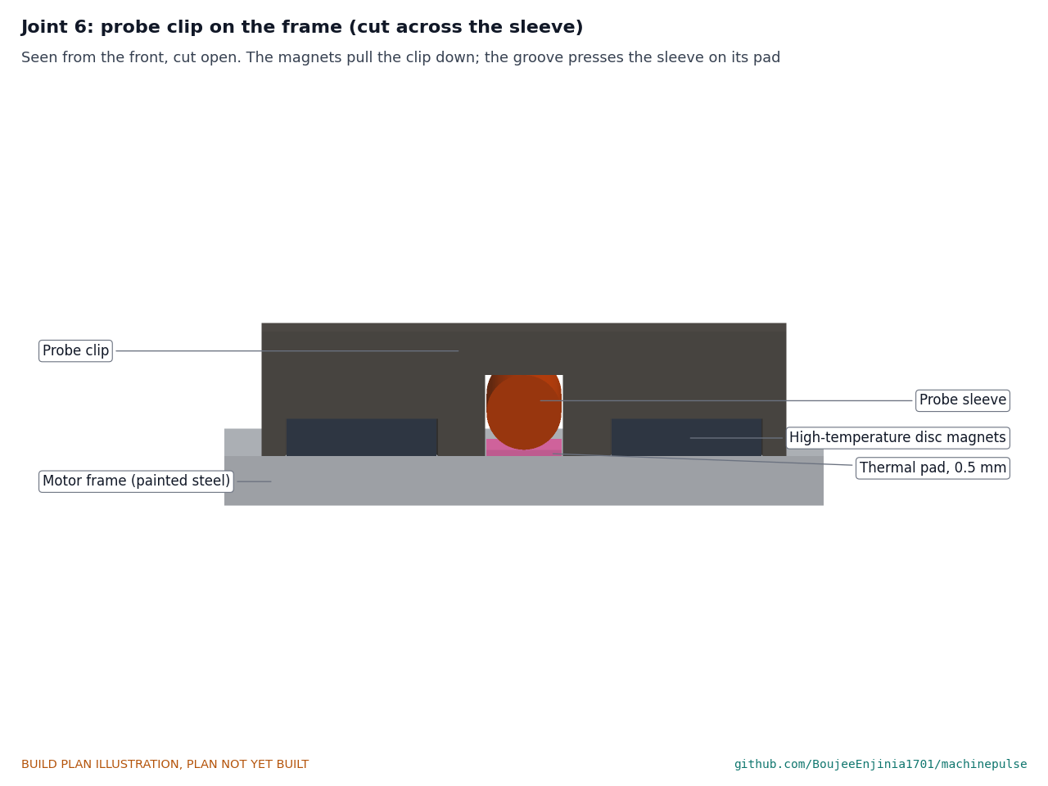
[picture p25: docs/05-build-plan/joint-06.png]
Figure 16. Joint 6: probe clip on the frame, cut across the sleeve


*Figure 16. The magnets pull the clip onto the frame; the groove holds the sleeve down on its 0.5 mm thermal pad.*

The sleeve lies in the groove on its thermal pad, its lead leaving along the groove. The magnets sit on the frame beside it and pull the clip down, so the groove presses the sleeve onto the pad and the pad onto the frame.

**Check before moving on.** On a flat steel plate the clip sits flat and the sleeve cannot be slid out by hand.

### 3.7 Bought components

Buy to specification, not brand. Line numbers are those of the bill of materials.

- **Box (lines 1 and 2).** IP54 ABS box 100 x 68 x 40 mm, base 28 mm and lid 12 mm, with four moulded corner pillars, a lid gasket and four lid screws, rated for continuous use at 70 °C or more. Drill as sections 3.3 and 3.5.
- **Cable glands (line 2).** One M16 x 1.5 nylon gland, IP68, for 4 to 8 mm cable, whose seal lets the current transformer's 3.5 mm plug through; two M12 x 1.5 nylon glands, IP68, for 3 to 6.5 mm cable.
- **Controller (line 3).** ESP32-S3 module board without octal PSRAM (the module rated to 85 °C), about 22 x 51 mm with two 20-pin rows 19.4 mm apart, USB-C, Wi-Fi.
- **Accelerometer (line 4).** IIS3DWB-class three-axis sensor, SPI, on an adapter board about 18 x 18 mm.
- **Magnets (line 6).** Two 32 mm neodymium pot magnets rated 120 °C or more, with M6 studs, about 290 N rated pull. Trim the studs to 5 mm with a hacksaw and file the thread end.
- **Current transformer (line 8).** Split-core, voltage output (1 V at rated current), 13 mm aperture, range chosen per machine so that normal load is above about 30 % of the range (30 A for a 7.5 kW motor). Never a current-output type.
- **Temperature probe (line 9).** DS18B20 in a 6 mm stainless sleeve about 34 mm long, 1 m lead with bare ends, and a 6 x 20 x 0.5 mm thermal pad.
- **Power supply (line 10).** Certified 5 V 1 A plug-in adapter with a USB-A socket and the local safety mark, and a 2 m USB-A cable.
- **Steel pads (line 11).** Two mild steel discs 35 mm across and 3 mm thick, with two-part epoxy, for machines with aluminium frames only.
- **Hardware (line 12).** Silicone grommet for a 24 mm hole in 2.5 mm panel with a 20 mm bore; one M6 x 12 set screw; four M3 x 12 nylon pan-head screws; four M3 x 5 mm female hex stand-offs with eight M3 x 6 screws; medium threadlocker; rigid two-part epoxy; high-temperature epoxy; wire, ferrules, heat shrink and cable ties.
- **Nylon stand-offs (line 13).** Four nylon spacers 6 mm across, 3.2 mm bore, 5 mm long.

## 4. Putting it together

In each picture the parts already fitted are grey and the part being fitted is in colour, with an arrow showing the way it goes in.

### Step 1: magnets onto the sensor block

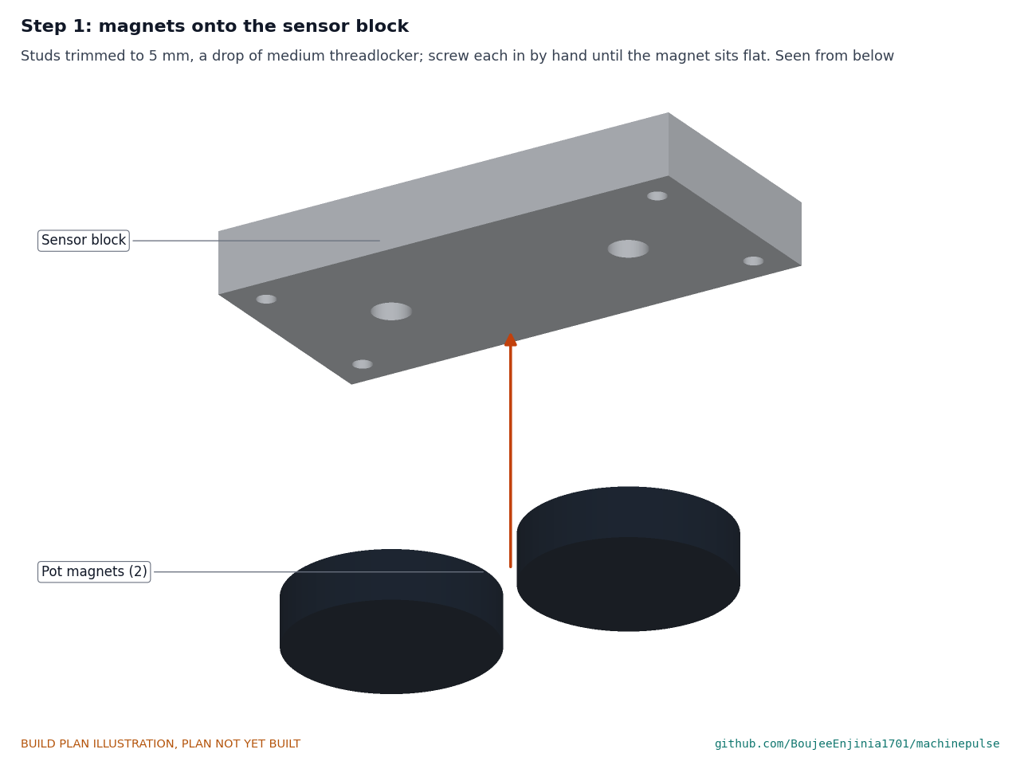
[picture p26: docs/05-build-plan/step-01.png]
Step 1


Seen from below. A drop of medium threadlocker on each trimmed stud; screw each magnet in by hand until its back sits flat on the block. Keep the magnets apart and away from steel tools while handling them.

### Step 2: boss onto the sensor block

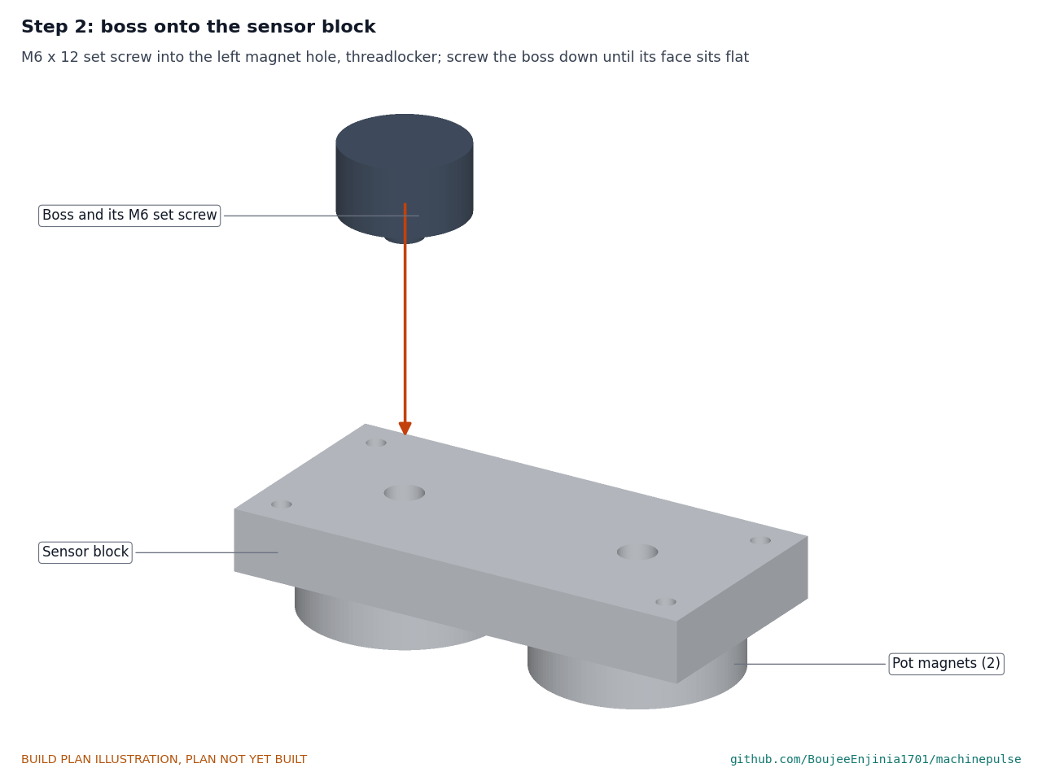
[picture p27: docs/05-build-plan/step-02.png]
Step 2


Threadlocker on the M6 x 12 set screw; screw it into the left magnet's hole from above until half of it stands proud, then screw the boss down onto it until the boss's face sits flat on the block.

### Step 3: glands and grommet into the box base

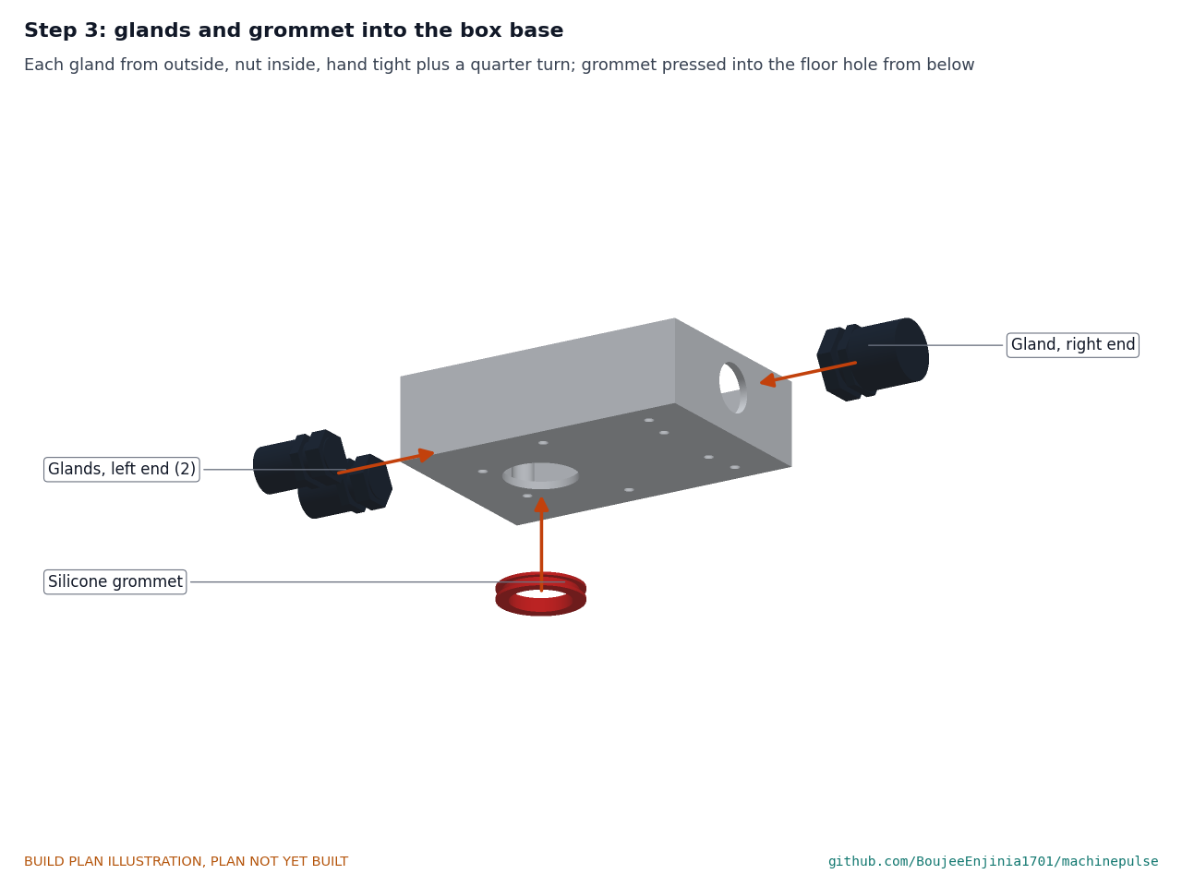
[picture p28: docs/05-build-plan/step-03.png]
Step 3


Each gland from outside with its nut inside, hand tight plus a quarter turn. Press the grommet into the boss hole from below until a flange sits each side of the floor.

### Step 4: box base onto the sensor block

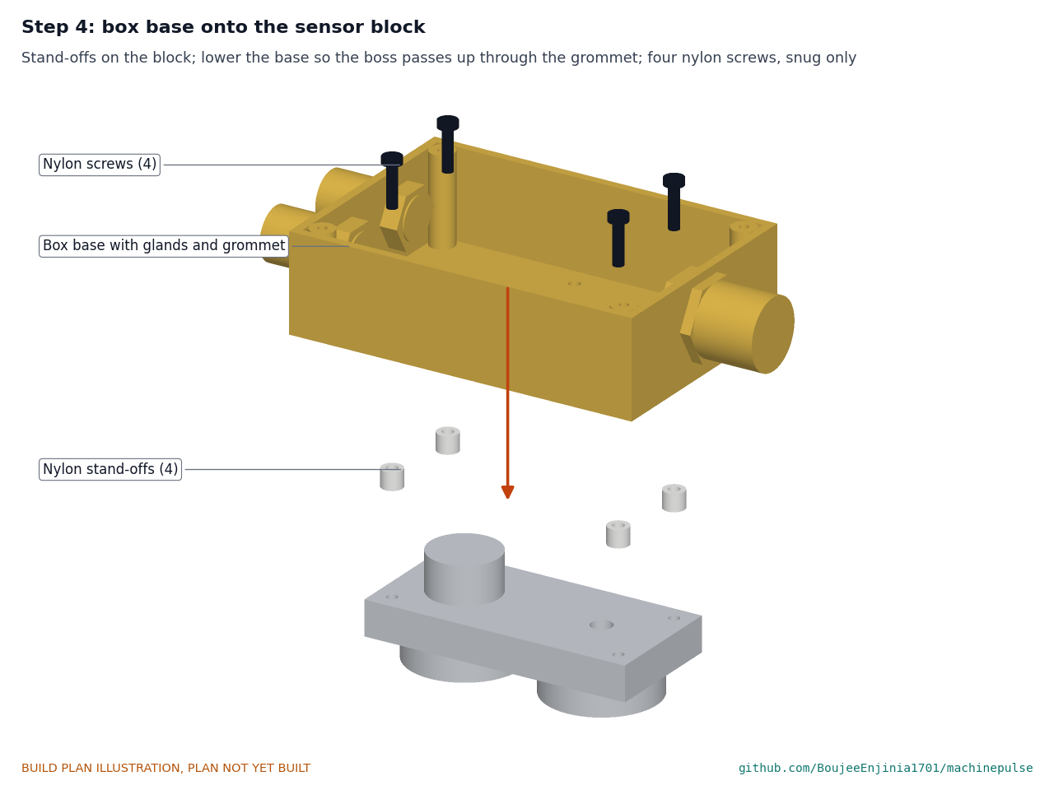
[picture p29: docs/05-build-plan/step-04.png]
Step 4


Stand the four nylon stand-offs on the block over their holes. Lower the base so the boss rises through the grommet and the floor sits on the stand-offs. Four nylon screws from inside, snug only: nylon threads strip easily. **Hold point:** the boss turns nowhere against the floor, and the 5 mm gap under the floor is even all round.

### Step 5: accelerometer onto the boss

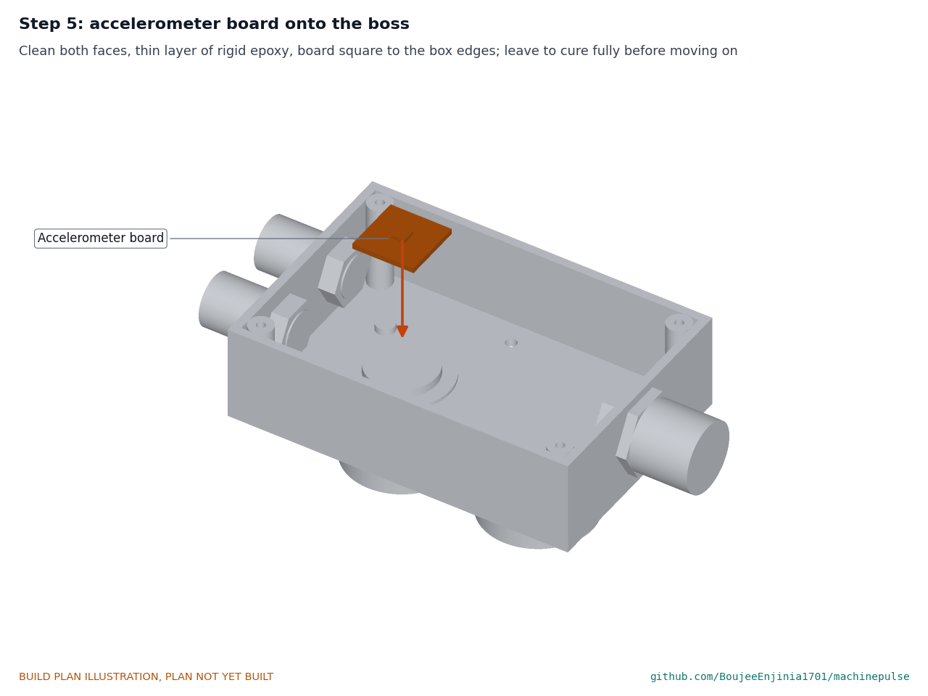
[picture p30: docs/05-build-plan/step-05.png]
Step 5


Clean the boss top and the board's underside, spread a thin layer of rigid epoxy, and set the board square to the box edges with its wires toward the carrier side. Leave it to cure fully before going on.

### Step 6: build the carrier board

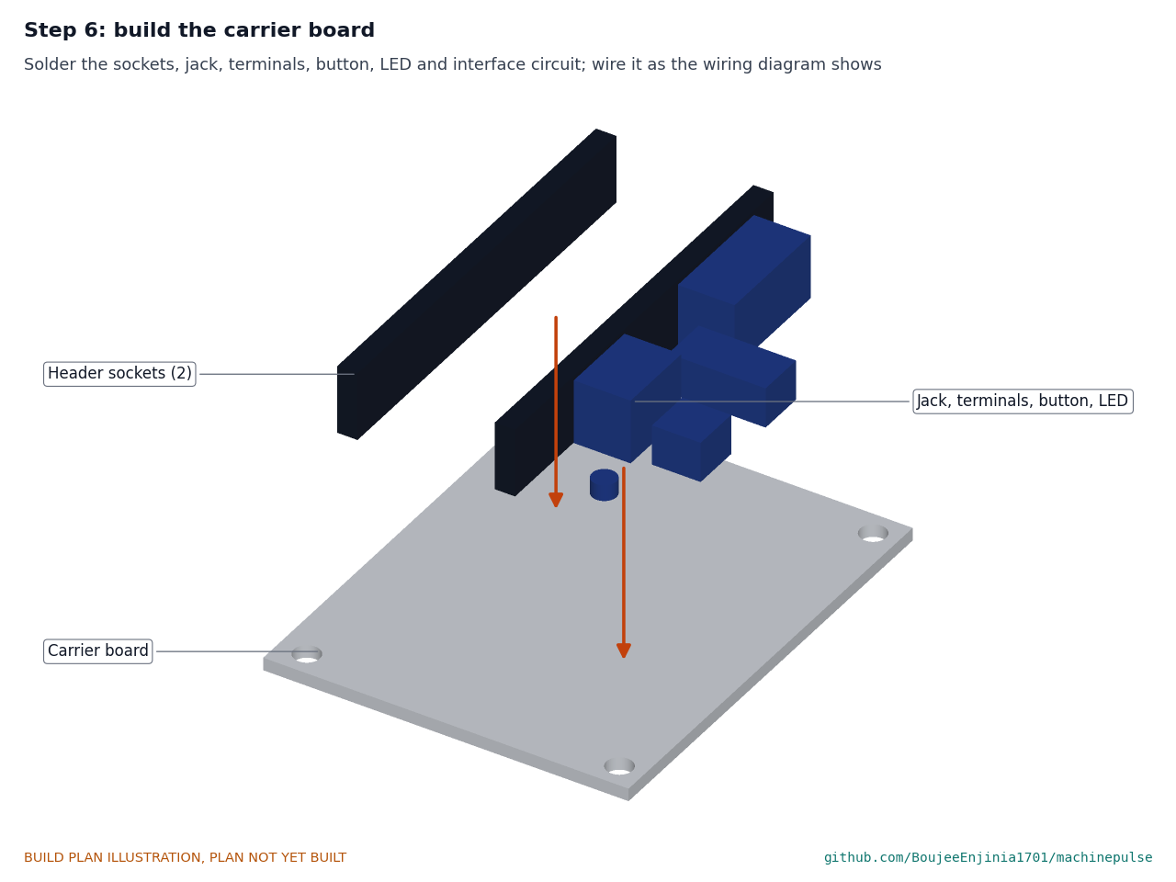
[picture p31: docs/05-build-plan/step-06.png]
Step 6


Solder the sockets, jack, terminals, button, LED and interface circuit as section 3.4 describes. **Hold point:** the checks of section 3.4 pass before the board goes in.

### Step 7: carrier stand-offs onto the floor

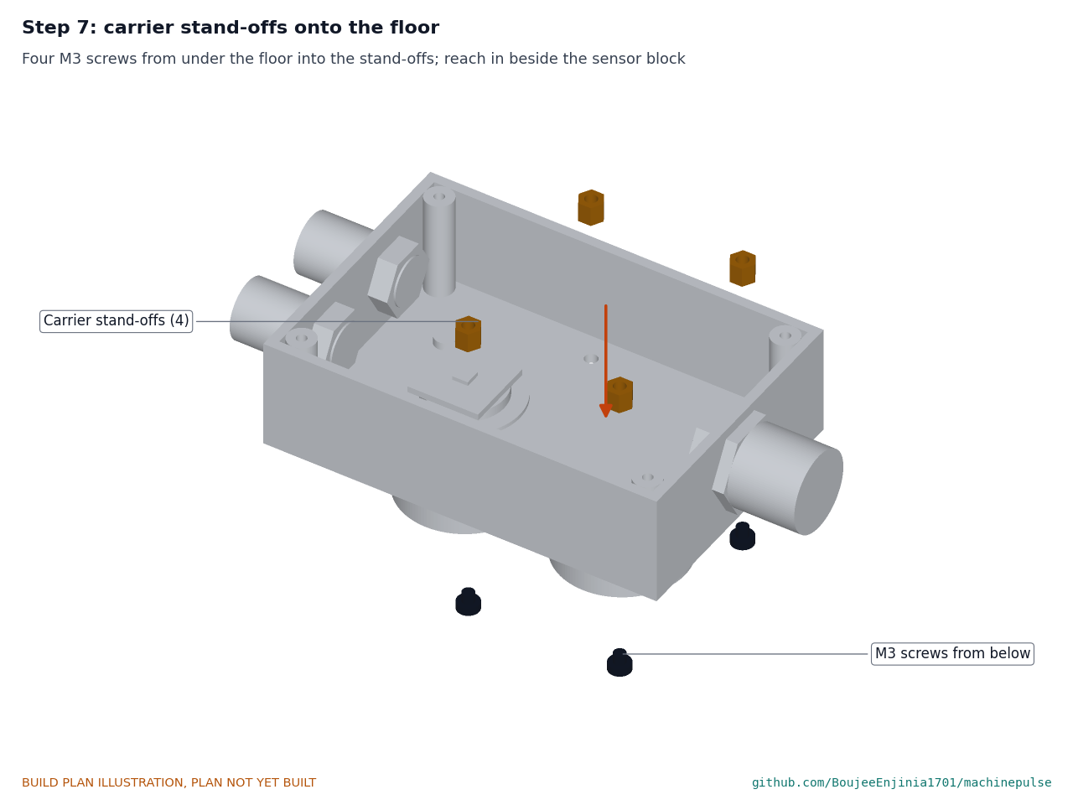
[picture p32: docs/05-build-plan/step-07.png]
Step 7


One M3 screw each from under the floor into the stand-offs, reaching in beside the sensor block.

### Step 8: carrier board onto its stand-offs

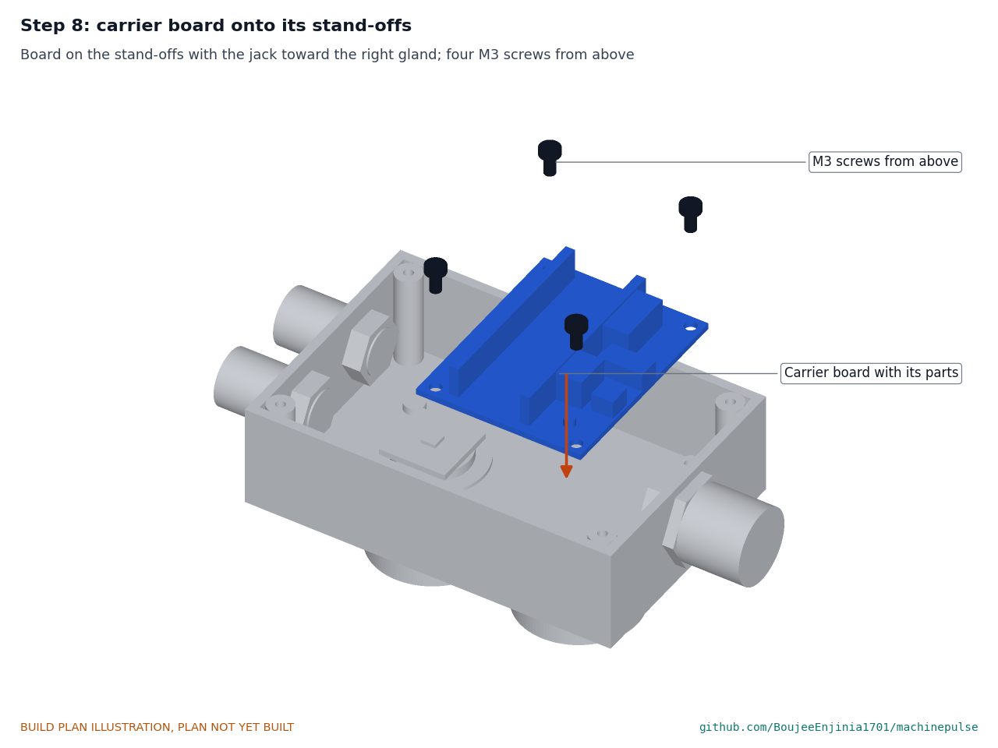
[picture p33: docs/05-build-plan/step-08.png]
Step 8


Board on the stand-offs with the jack toward the right gland; four M3 screws from above.

### Step 9: controller into its sockets

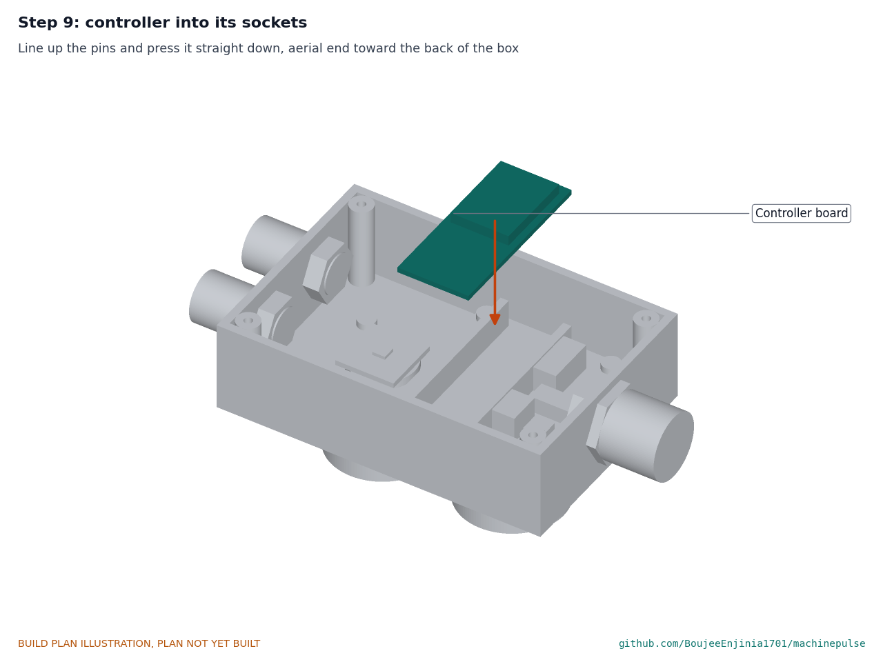
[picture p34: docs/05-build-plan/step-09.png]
Step 9


Line up the pins and press the controller straight down, aerial end toward the back of the box. Its USB port can be reached with the lid off.

### Step 10: leads in, light pipe and lid

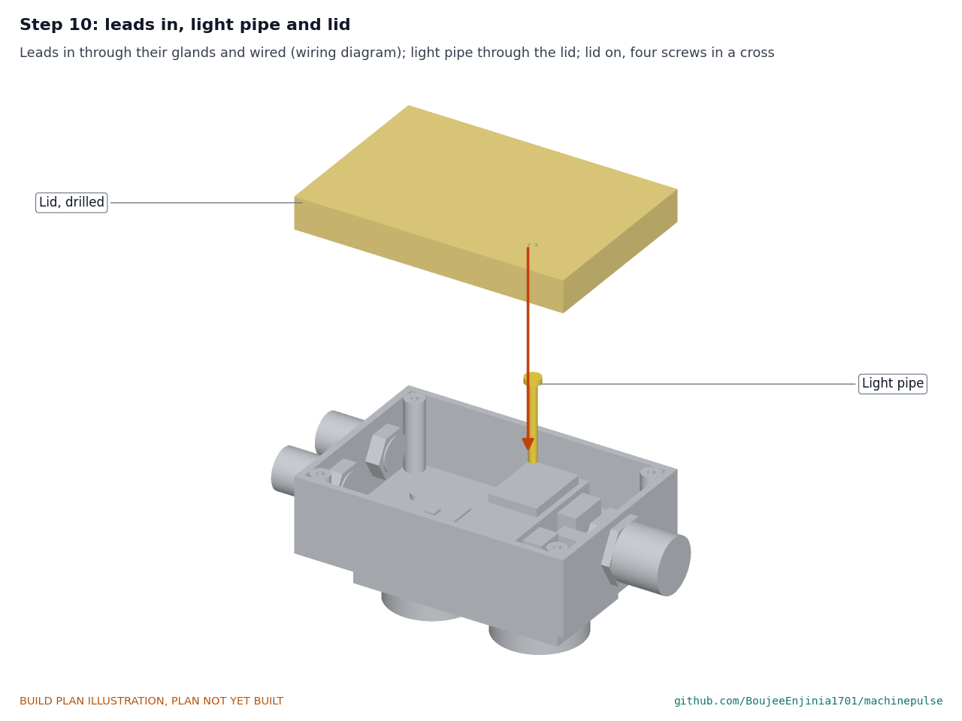
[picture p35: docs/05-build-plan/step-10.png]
Step 10


Pass the power, probe and current transformer leads through their glands and wire them as section 3.4.1. Tighten each gland cap on its lead. Fit the light pipe through the lid, seal its bezel, then close the lid with its four screws in a cross pattern. **Hold point:** safety stop S2.

### Step 11: magnets into the probe clip

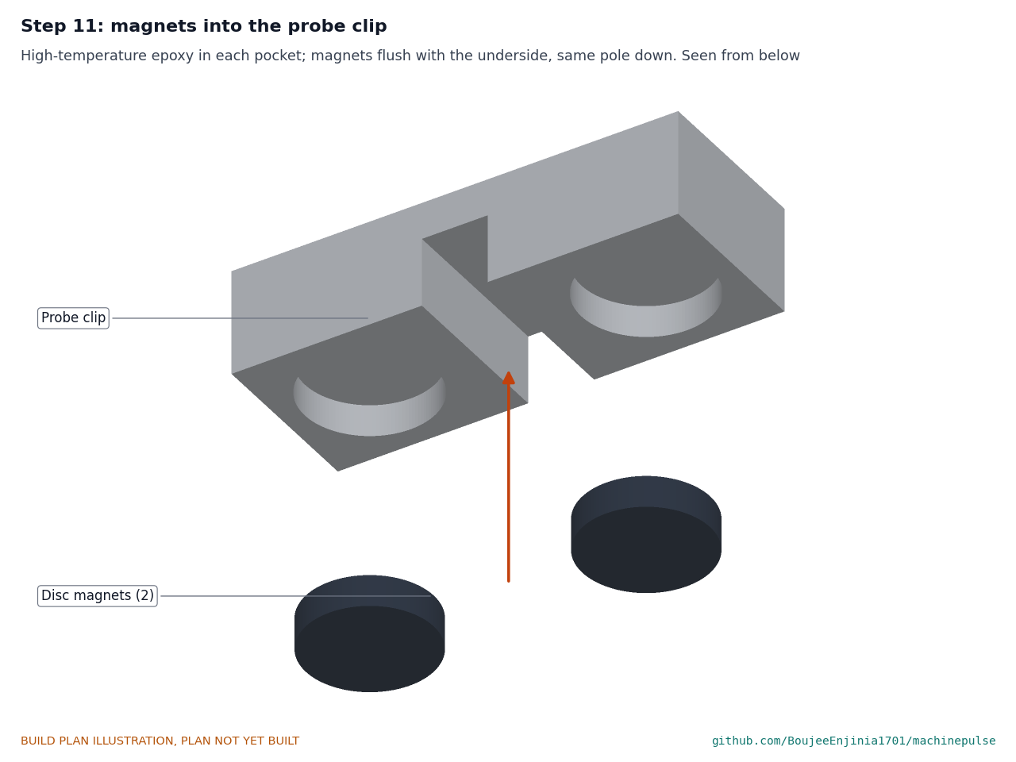
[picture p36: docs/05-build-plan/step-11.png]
Step 11


Seen from below. High-temperature epoxy in each pocket; press each magnet in flush with the underside, the same pole facing down on both. Leave to cure.

### Step 12: probe and pad into the clip

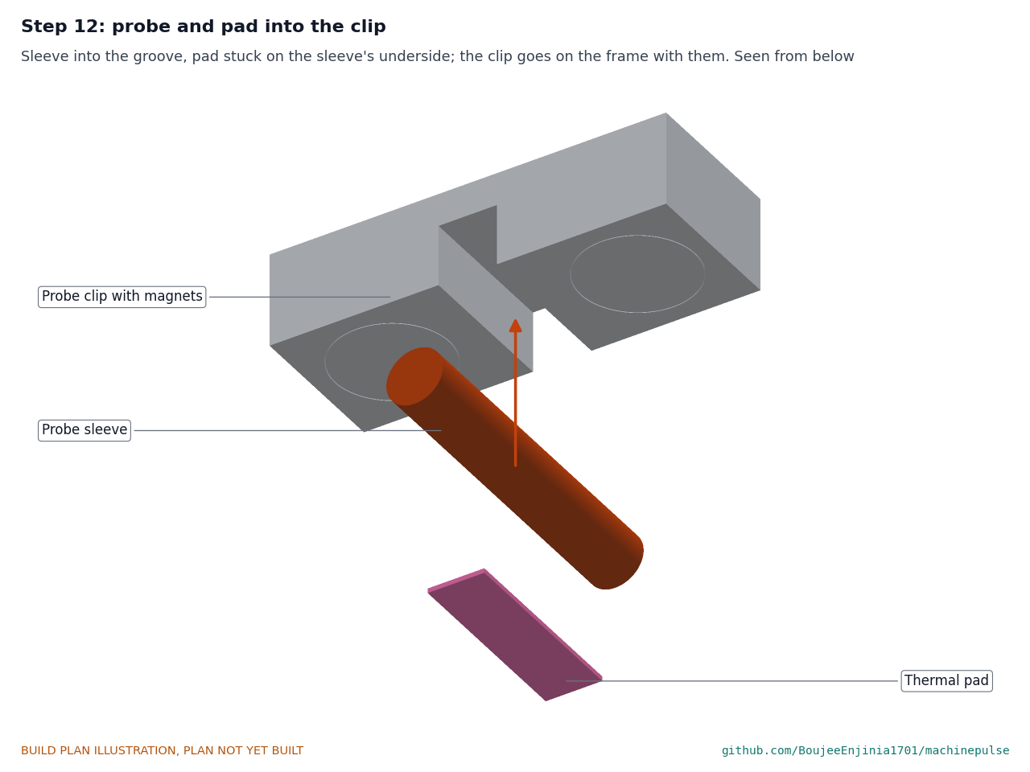
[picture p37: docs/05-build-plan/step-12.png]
Step 12


Seen from below. Stick the thermal pad on the sleeve's underside and lay the sleeve in the groove; the clip, sleeve and pad go onto the frame together.

### Step 13: onto the machine

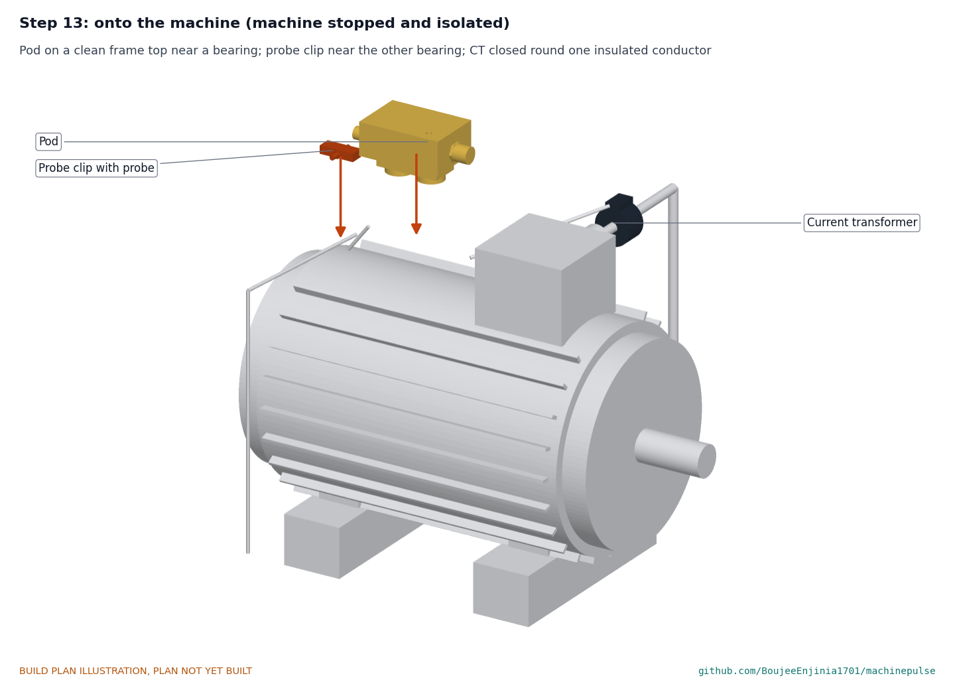
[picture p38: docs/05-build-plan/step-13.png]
Step 13


**Hold point:** safety stops S3 and S4. With the machine stopped, isolated and locked off: wipe a flat or gently curved patch of the frame top near a bearing and set the pod on it (on an aluminium frame, epoxy the two steel pads on first); set the probe clip near the other bearing; have a qualified person close the current transformer round one insulated phase conductor. Tie every lead clear of belts, shafts, chucks and fans.

## 5. First checks

These are the checks a TRL 4 test report would record; this plan only lists them. Requirement numbers are those of MPL-REQ-001.

*Table 2. First checks.*

| Check | Requirement | How | Pass when |
| --- | --- | --- | --- |
| Floor clear of the block | R12, R5 | Feeler gauge round the floor's edge; push the box sideways by hand | Gap 5 mm, give or take 0.5, all round; the boss touches only the grommet |
| Boss and magnets tight | R5 | Try to turn the boss and each magnet by hand | Nothing moves |
| Glands and lid sealed | R13 | Look at each seal on its lead; lid gasket evenly squeezed | No gaps; each lead cannot be pulled through its gland (the IP test comes later) |
| First power | R17 | Adapter plugged in; measure at the 5 V terminal and the 3.3 V pin; read the adapter current with a USB meter | 5 V give or take 0.25 V; 3.3 V give or take 0.1 V; about 85 mA |
| Current transformer bias | R3 | Current transformer unplugged; measure at the controller's analog input | 1.50 V give or take 0.03 V |
| Accelerometer at rest | R5, R6 | Pod flat on a steel plate; read the sensor | About 1 g on the vertical axis, about 0 on the others |
| Probe reading | R8 | Probe clip on a steel plate at room temperature beside a reference thermometer | Within 0.5 °C |
| Magnet hold | R11 | Pod on a painted steel plate; push it sideways by hand | It does not slide |
| Data reaches the broker | R9, R14 | Summary messages on the local MQTT broker | One a minute, each within 2 minutes |
| Mass | R11 (load) | Weigh the pod | About 0.32 kg |

## 6. Safety stops

Stop at each point. Carry on only when everything listed is true.

- **S1. Before the first power-up.** The adapter is a certified unit with the local safety mark and undamaged; on the carrier, 5 V and ground read open to each other; the 5 V terminal's polarity is checked with a meter, not by wire colour.
- **S2. Before the pod leaves the bench.** The first checks of section 5 that can be done on the bench pass; every gland is tight on its lead; the lid is closed and sealed.
- **S3. Before going near the machine.** The machine is stopped, isolated and locked off by the person responsible for it, and the lock-off is tested. The frame is cool enough to touch, or gloves are worn. Nobody near the work has a pacemaker.
- **S4. Before the current transformer is fitted.** It is a voltage-output type (its label shows a voltage output, such as 1 V at rated current). The conductor is single, insulated and undamaged. Any terminal box or panel is opened and closed only by a qualified person, and its cover is back on before the machine is restarted.
- **S5. Before the machine runs again.** Every lead is tied clear of belts, shafts, chucks and fans; no guard was removed or left open; the pod and probe are on stationary parts of the frame. MachinePulse is a monitoring aid only: it is never wired into the machine's controls.

## 7. Tools, skills and workspace

**Tools.** Hacksaw with a 24 teeth per inch blade; bench vice with soft jaws; V-block; drill press; drills 2.5 to 12 mm, a 5.0 mm drill and a flat-bottomed 12 mm drill or end mill; step drill to 24 mm; M3 and M6 taps with a tap wrench; flat and half-round files; small chisel; deburring tool; scriber, engineer's square, steel rule, calipers and feeler gauges; soldering iron and solder; wire strippers and ferrule crimper; multimeter; USB power meter; torque-limited or small screwdrivers; gloves for epoxy; kitchen scale to 1 kg; a flat steel plate for checks.

**Skills.** No certified trade is needed for the pod. Basic metalwork (marking out, sawing, filing, drilling, tapping), through-hole soldering on perfboard and careful handling of strong magnets. Fitting the current transformer at a machine is a qualified person's job wherever a terminal box or panel must be opened.

**Workspace.** A bench about 1.2 x 0.6 m; a metalwork corner kept apart from the electronics so chips stay off the boards; a ventilated place for epoxy and soldering; a non-magnetic tray for the magnets.

**Personal protective equipment.** Safety glasses for cutting, drilling and soldering; gloves for epoxy and hot frames; no gloves near a turning drill.

## 8. Where the numbers come from

- Model and constructability checks: `cad/src/model.py` (`python cad/src/model.py --check`, 102 checks); STEP and STL exports in `cad/step/` and `cad/stl/`.
- Pictures: `cad/src/build_plan_media.py`, using `.kit/build_views.py`; written to `docs/05-build-plan/` and `cad/drawings/MPL-DWG-101` to `MPL-DWG-106`.
- General arrangement: `cad/drawings/MPL-DWG-001.pdf`, Rev P4.
- Calculations: `docs/04-calcs/01-sizing.md` (MPL-CAL-001 v0.3) and `docs/04-calcs/sizing.py`; mass [D6], mount resonance [D7], magnet holding [E3], [E5], probe contact [F1], hot frame [G2], [G3], power [H1], cost [J1].
- Bill of materials: `bom/bom.csv` and `bom/bom-notes.md`.
- Decisions: `docs/decisions/0003-design-for-construction.md` (MPL-DDR-003), with MPL-DDR-001 and MPL-DDR-002; open items in `docs/06-design-decisions.md` (MPL-DEC-001).
- Requirements: `docs/03-requirements.md` (MPL-REQ-001 v0.5).

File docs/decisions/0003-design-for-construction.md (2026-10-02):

---
doc_id: MPL-DDR-003
title: MachinePulse design for construction
project: MachinePulse
doc_type: Design decision record
version: "0.2"
status: Draft
date: '2026-10-02'
author: Amish Chadha
license: CERN-OHL-S-2.0
revisions:
- version: "0.1"
  date: '2026-10-01'
  author: Amish Chadha
  change: Changes that make the concept physically buildable, with the reason for each; made under Amish's 2026-09-30 instruction to make the design physically buildable; open for his review
- version: "0.2"
  date: '2026-10-02'
  author: Amish Chadha
  change: 'Accepted by Amish on 2026-10-02, with A1 and A2 as recommended; record stays Draft'
---

# 0003: Design for construction

- **Date:** 2026-10-01
- **Status:** accepted. Made under Amish's 2026-09-30 instruction to make the design physically buildable. Amish, 2026-10-02: "i approve your recommendations for all 555 open decisions." This covers every change in Tables 1 and 2 and the recommendations in Table 3 (A1 and A2), which are now decided as recommended and recorded in the design decisions register (MPL-DEC-001). The record stays Draft.

## Context

On 2026-09-30 Amish approved the build plan format for the portfolio and wrote: "If you are realising that the design cannot be built as per concept - fix the design assumptions to match and be physically feasible as you draw the illustrations." The concept model of MPL-DDR-002 showed what MachinePulse does and was enough for the calculations, but it was a massing model: several parts could not be made with hand tools and a drill press (R16), had no fixing, floated in space or overlapped their neighbours. Checking the model with build123d (intersections, distances and an assembly order) found the ten problems in Table 1.

The changes keep what the pod does: the same box, magnets, block footprint, boss height, stand-off gap, sensors, controller, CT, probe, power supply, data path and installed positions. Nothing here changes the pitch or the safety case. Every change is in `cad/src/model.py`, which now runs 102 constructability checks (`python cad/src/model.py --check`): 26 pairs of parts that must touch do touch without overlapping, 21 pairs that must be apart are apart by at least the stated gap, and no two of the 25 modelled components overlap anywhere (55 pairs whose outlines meet are checked). All 102 pass.

## Decision

*Table 1. Changes made to the model, the BOM and the calculations.*

| # | Problem in the concept | Change made | Why this way |
| --- | --- | --- | --- |
| P1 | The sensor block and its boss were one solid 21 mm tall with a 20 mm boss on a 10 mm plate. That needs a lathe or a mill, against R16's hand tools and a drill press. | The block is a 76 x 36 x 10 mm plate. The boss is a separate 11 mm length of 20 mm round bar, tapped M6 8 mm deep in its base, joined to the block by an M6 x 12 set screw with threadlocker in the left magnet's tapped hole, its face pulled down flat on the block. | Keeps the stiff metal path frame, magnet, block, boss, accelerometer and the boss height of 11 mm. The set screw shares the hole the magnet stud uses, so the boss sits directly over magnet 1 as the concept had it. |
| P2 | The magnets' M6 studs had no holes in the block. | Both magnet positions are drilled 5.0 mm and tapped M6 right through; the studs are trimmed to 5 mm and screwed in with threadlocker until the magnet backs sit flat on the block. | A tapped through hole can be made square in a drill press; 5 mm of stud leaves room for the set screw above magnet 1. |
| P3 | The four nylon stand-offs had no screws or holes, sat 0.6 mm from the edge of the 24 mm floor hole and overlapped the boot by about 9 mm³. | Stand-offs moved from 30 x 12 mm to 33 x 13 mm each side of centre; each is held by an M3 x 12 nylon screw from inside the box, through the floor and the stand-off, into an M3 tapped hole in the block. | The screws stay nylon, so the stand-offs remain a thermal break; the new positions clear the grommet by 1.4 mm and stay outside the magnets' footprint. |
| P4 | The silicone boot was a 1 mm ring floating 4 mm above the block, held by nothing. | A stock silicone grommet seated in the 24 mm floor hole, its 20 mm bore gripping the boss, with a 1 mm flange each side of the floor. | Seals the floor hole (R13) with a bought part; the soft grommet touches the boss over about the same length the thermal model already assumed, so the floor temperature result stands. |
| P5 | The controller and interface boards floated 5 mm above the floor with no fixing; module boards of this class usually have no mounting holes. | One carrier perfboard, 45 x 56 mm, on four M3 x 5 mm hex stand-offs screwed through the floor (the screw heads sit beside the block, outside its footprint). The interface circuit, jack, terminals, button and LED are on it, and the controller plugs into two 20-pin header sockets on it. | One board to fix instead of two; the controller can be lifted out to be programmed. The board stays 4 mm clear of the CT gland nut and 5 mm from the accelerometer. |
| P6 | The glands were cylinders fused to the outside of the end walls, with no holes and no nuts; the probe and USB leads shared one M12 gland, which a single-hole seal cannot seal; a USB-C plug cannot pass through a gland. | Three glands, one cable each, centred 15.5 mm up from the box underside so their nuts clear the floor and the corner pillars: an M16 gland (cable 4 to 8 mm) on the right end for the CT lead, whose 3.5 mm plug passes the seal, and two M12 glands on the left end for the probe and power leads. The power cable's far plug is cut off and its two wires go to a 5 V screw terminal on the carrier. | Keeps R13 (IP54) true for every lead, and lets every lead be fitted without cutting the CT's or the probe's own leads. The adapter itself stays a certified unit, so the safety case (D2) is unchanged. Also settles the review note's 2026-09-26 item 4 (two leads in one gland). |
| P7 | The box's moulded corner pillars and lid screws were not modelled, so clearances to them were unchecked. | The base now carries four 7 mm pillars; every gland nut, board and stand-off is checked against them. | The stock box has them; the carrier board and the gland positions were set to clear them. |
| P8 | The accelerometer board had no fixing, and at 18 x 18 mm (25.5 mm across the corners) it cannot pass the 24 mm floor hole. | It is bonded to the boss top with a thin layer of rigid two-part epoxy, after the base is fitted (build step 5). | A rigid bond is the usual way to mount a MEMS accelerometer for vibration; the order of assembly follows from the board's size. |
| P9 | The temperature probe's sleeve lay on top of a block "clip" 7 mm above the frame, so it did not touch the frame, and a magnetic clip for a 6 mm sleeve is not a stock part. | A made probe clip: an aluminium bar 42 x 16 x 10 mm with a 6.2 mm wide, 6.5 mm deep groove across its underside and two 12 x 3 mm high-temperature disc magnets bonded flush in pockets. The sleeve lies in the groove on its 0.5 mm thermal pad; the magnets pull the clip down and the groove presses the sleeve onto the pad. New BOM line 14. | Puts the sleeve where the probe calculation (MPL-CAL-001, F) assumed it: on a 6 x 20 mm pad on the frame. The magnets are a high-temperature grade because the clip sits on frames up to 100 °C. |
| P10 | The lid had an LED window but nothing carried light from the board to it. | A 3 mm light pipe stands on the status LED on the carrier and passes up through a 3.2 mm hole in the lid; its bezel is sealed to the lid with silicone. | Gives the status light the concept shows without opening the box; sealing the bezel keeps IP54. |

*Table 2. Knock-on changes.*

| Item | Change | Reason |
| --- | --- | --- |
| Mass | Pod 319 g [D6] (was 295 g). | Carrier board, sockets, glands, pillars and fixings. |
| Mount resonance (R5) | 892 Hz on a painted curved frame (was 927 Hz), 1,783 Hz flat (was 1,853 Hz); readings 10 % high from 267 Hz (was 278 Hz) [D7]. R5 stays at risk. | Follows the mass. |
| Magnet holding (R11) | Slip margin 3.0 curved (was 3.3), 2.8 at 80 °C (was 3.1); pull-off 12.2 (was 13.2); 3 mm pads 7.0 (was 7.5) [E3, E5, G5]. R11 stays met by calculation. | Follows the mass. |
| Thermal (R12) | Unchanged: the stand-off gap, block, box and boss contact are the same, and the grommet replaces the boot with the same contact. | |
| Cost | BOM lines 2, 7, 9 and 12 repriced and line 14 added. Value-engineering target: USD 81. Estimated cost of the constructable design: USD 83.50 (USD 2.50 over the target) [J1]. `budget_usd` unchanged. | Parts added for construction; see the register's value engineering section. |
| Size | 137 mm over the glands (was 132 mm); 100 x 68 x 63 mm unchanged. | The M16 gland is longer than the M12 it replaces. |
| Drawing | MPL-DWG-001 Rev P4; making sketches MPL-DWG-101 to 106 added. | Follows the model. |
| Documents | MPL-CAL-001 v0.3, MPL-REQ-001 v0.5, MPL-PRC-001 v0.5, `bom/bom.csv`, `bom/bom-notes.md`. No requirement target changed; R16 is now reported against the value-engineering target. | Follows the model. |

*Table 3. Items that were proposed, awaiting Amish; decided by Amish on 2026-10-02.*

| # | Question | Options | Recommendation |
| --- | --- | --- | --- |
| A1 | How the 5 V supply enters the box. | (a) cut the USB cable's far plug and wire it through an M12 gland to a screw terminal, as modelled; (b) an IP67 panel-mount USB-C socket in the end wall, about USD 5 more. | (a) for the prototype: cheapest, sealed, and the adapter stays certified. **Decided by Amish, 2026-10-02:** (a). |
| A2 | Where the status button goes (carried over from the 2026-09-26 review note, item 1). | (a) on the carrier board, pressed with the lid off, as modelled; (b) a sealed button on the lid beside the light pipe, about USD 1.50 more and another lid hole. | (a) for the prototype; (b) if pairing in the field turns out to need it. **Decided by Amish, 2026-10-02:** (a), pressed with the lid off; a sealed lid button only if field pairing shows it is needed. |

## Consequences

- `design_state: constructable` in `project.yaml`. The build plan MPL-BLD-001 shows every component and step in pictures generated from the model (`cad/src/build_plan_media.py`); open items are in the design decisions register MPL-DEC-001.
- Requirement status (MPL-CAL-001 v0.3): 1 not met (R10), 3 at risk (R3, R4, R5), 9 met by calculation, 3 met by design, and R16 USD 2.50 over the value-engineering target.
- The photoreal renders (`media/render-*.png`), `media/card.png`, `media/social-preview.png` and the appearance model `cad/src/product_model.py` still show the concept's boss, glands and boards; they need updating on Amish's Mac, where Blender is.
- Parts to check when bought (stud length, gland seals, grommet, box pillars, controller pin rows, light pipe hole) are listed in the register.
- TRL 4 is on hold by Amish's instruction. Nothing in this record authorizes building, testing or buying parts.

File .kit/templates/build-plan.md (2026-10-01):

---
doc_id: PRJ-BLD-001
title: Project prototype build plan
project: Project name
doc_type: Build plan
version: "0.1"
status: Draft
date: YYYY-MM-DD
author: Amish Chadha
license: CERN-OHL-S-2.0
revisions:
  - version: "0.1"
    date: YYYY-MM-DD
    author: Amish Chadha
    change: First build plan; design made constructable
---

# Project prototype build plan

**Plan, not yet built.** How to build the first proof-of-concept prototype, component by component. Building and testing to it is TRL 4 work. Decisions still to be made are kept in the design decisions register (`docs/06-design-decisions.md`), not here.

## 1. What you are building

Every component, pulled apart and numbered in build order

One short paragraph: what the prototype is, how many components, which are made and which are bought, and the main ways they are made.

## 2. What changed to make it buildable

| Component | The concept had | The buildable design has | Why |
| --- | --- | --- | --- |

## 3. Making the components

### 3.1 Component name

Making sketch

**What it is and what it is made from.**

**How to make it.**

1. Mark out ...
2. Cut ...

**How it fits the parts next to it.**

Close-up of the joint

**Check before moving on.**

## 4. Putting it together

### Step 1: ...

Step 1

## 5. First checks

| Check | Requirement | How | Pass when |
| --- | --- | --- | --- |

## 6. Safety stops

## 7. Tools, skills and workspace

## 8. Where the numbers come from

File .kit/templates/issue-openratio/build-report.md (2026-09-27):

---
name: Build report
about: Tell us what happened when you built, printed or tested part of this design
title: "Build report: "
labels: build-report
---

This is a research and educational prototype, not a medical device. It is a TRL 3 concept and is not released for fabrication. If you build any part of it, you do so at your own risk. Reports help everyone.

**What you built** (part, sub-assembly or test)

**Materials, tools and settings**

**What worked**

**What did not work, with photos or measurements if you have them**

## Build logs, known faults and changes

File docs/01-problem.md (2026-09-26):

---
doc_id: MPL-PRB-001
title: MachinePulse problem statement
project: MachinePulse
doc_type: Problem statement
version: "0.4"
status: Draft
date: '2026-09-25'
author: Amish Chadha
license: CERN-OHL-S-2.0
revisions:
- version: "0.1"
  date: '2026-09-25'
  author: Amish Chadha
  change: Initial scaffold
- version: "0.2"
  date: '2026-09-25'
  author: Amish Chadha
  change: Populate to TRL 2 (problem, users, context, constraints, prior work)
- version: "0.3"
  date: '2026-09-25'
  author: Amish Chadha
  change: Open questions updated for the items adopted for TRL 3 in MPL-DDR-001; CT constraint noted from MPL-CAL-001
- version: "0.4"
  date: '2026-09-25'
  author: Amish Chadha
  change: Recommendations accepted by Amish (DDR-002)
---

# MachinePulse problem statement

Small factories run machines that have no monitoring, so breakdowns arrive without warning and utilization is unknown. The machines themselves are often sound: a 30-year-old lathe, pump or air compressor can run for decades more. What is missing is a cheap, safe way to see how hard each machine works and to notice when it starts to change.

## The problem

Most machines in small workshops are driven by an induction motor and have no electronics beyond a contactor and an overload relay. Maintenance is reactive: a bearing, belt or coupling runs until it fails, and the first sign is noise, heat or a stopped line. The owner also has no record of how many hours each machine actually runs, so decisions on staffing, replacement and energy use are guesses.

The cost of this is measurable. A NIST study of US discrete manufacturing estimated $119.1 billion of losses in 2016 from inadequate maintenance, and found that establishments in the top quarter for reliance on reactive maintenance had 3.3 times more downtime and 16 times more defects than those in the bottom quarter ([Thomas and Weiss, NIST AMS 100-34, 2020](https://nvlpubs.nist.gov/nistpubs/ams/NIST.AMS.100-34.pdf)). An earlier NIST review reported maintenance cost reductions of 15 % to 98 % from advanced maintenance in the literature it surveyed ([Thomas, NIST AMS 100-18, 2018](https://nvlpubs.nist.gov/nistpubs/ams/NIST.AMS.100-18.pdf)).

Condition monitoring is a mature field. ISO 20816-1 sets general conditions for measuring and evaluating machine vibration ([ISO](https://www.iso.org/standard/63180.html)), and motor makers sell predictive maintenance platforms ([ABB Ability Digital Powertrain Insights](https://www.abb.com/global/en/areas/motion/services/asset-health-and-monitoring/abb-ability-digital-powertrain-insights), for example). These products are priced and supported for large plants. Open energy monitors show that clip-on current transformers can be used safely by non-specialists when they measure an insulated conductor ([OpenEnergyMonitor CT guide](https://docs.openenergymonitor.org/electricity-monitoring/ct-sensors/introduction.html)), but they do not look at vibration or temperature. There is no open, low-cost reference design that combines run time, load, vibration and temperature for one old machine and that a small shop can build, inspect and adapt.

## Users and context

| User | Need | Context |
| --- | --- | --- |
| Owner of a small machine shop or plant | Run hours and load per machine; early warning before a breakdown | 5 to 50 machines, no maintenance engineer, shop Wi-Fi |
| Machine operator or maintainer | A simple sign that a machine has changed (hotter, rougher, drawing more current) | Shop floor, dusty and oily, noisy |
| Electrician or technician | A current clamp that fits safely and quickly on an insulated conductor | Installs during a planned stop, with the machine isolated |
| Makerspace, school or university workshop | Utilization of shared machines and a teaching tool for condition monitoring | Mixed users, safety-sensitive |
| Open hardware and digital twin community | A sensor that feeds TwinKit and can be adapted to other machines | Lab and field |

Typical machines: lathes and mills, bench and pillar drills, air compressors, water and coolant pumps, fans and blowers, grain and rice mills, and small conveyors, most driven by 0.37 kW to 15 kW induction motors on single-phase or three-phase supplies.

## Constraints

- Garage-buildable prototype, about $81 USD per monitored machine, from off-the-shelf modules and hand-made parts, with no custom PCB for the first build.
- Non-invasive: no change to the machine's wiring, controls or guarding. The pod attaches by magnets; the current clamp goes around one existing insulated single-core conductor (a multi-core cable carries currents that cancel, so the clamp cannot read it).
- Works on old machines with no electronics of their own, on cast iron, steel or aluminium frames.
- Low voltage only inside the pod (5 V USB from a certified adapter).
- Survives a workshop: dust, oil mist, splashes and frame temperatures typical of running motors.
- Data stays on the owner's network by default (TwinKit gateway or any MQTT broker); no cloud account is needed.

## Out of scope

- Machine protection or control. MachinePulse never trips, stops or starts a machine; existing protective devices stay in charge.
- Revenue-grade energy metering.
- Automated fault diagnosis with a guaranteed accuracy. The concept flags changes against the machine's own baseline for a person to check.

## Safety context

> **Safety:** The current clamp is fitted around a conductor at mains voltage. Fitting it may require opening a terminal box or panel, which is work for a qualified person with the machine isolated and locked off. The pod is fixed to a machine with rotating parts: mount it only on stationary surfaces, route leads away from belts, shafts and chucks, and never fit it while the machine runs.

## Open questions

- First pilot site and machines: a makerspace or university workshop with a lathe and a compressor. Decided by Amish, 2026-09-25: go with recommendation (MPL-DDR-001, D8).
- Co-design partner for the alerts and dashboard: who decides what "changed" should mean to an operator? No recommendation was made. Proposed, awaiting Amish (MPL-DDR-001, O1).
- Single-phase and three-phase coverage in the first build: one CT on one phase for both. Decided by Amish, 2026-09-25: go with recommendation (MPL-DDR-001, D4). Whether energy per shift (R4) is then accepted as at risk or relaxed to a relative trend is still awaiting Amish (O2).
- How many machines in a small shop offer a single insulated phase conductor outside a closed enclosure. MPL-CAL-001 finds R10 not met where they do not; the pilot site should show how common this is.

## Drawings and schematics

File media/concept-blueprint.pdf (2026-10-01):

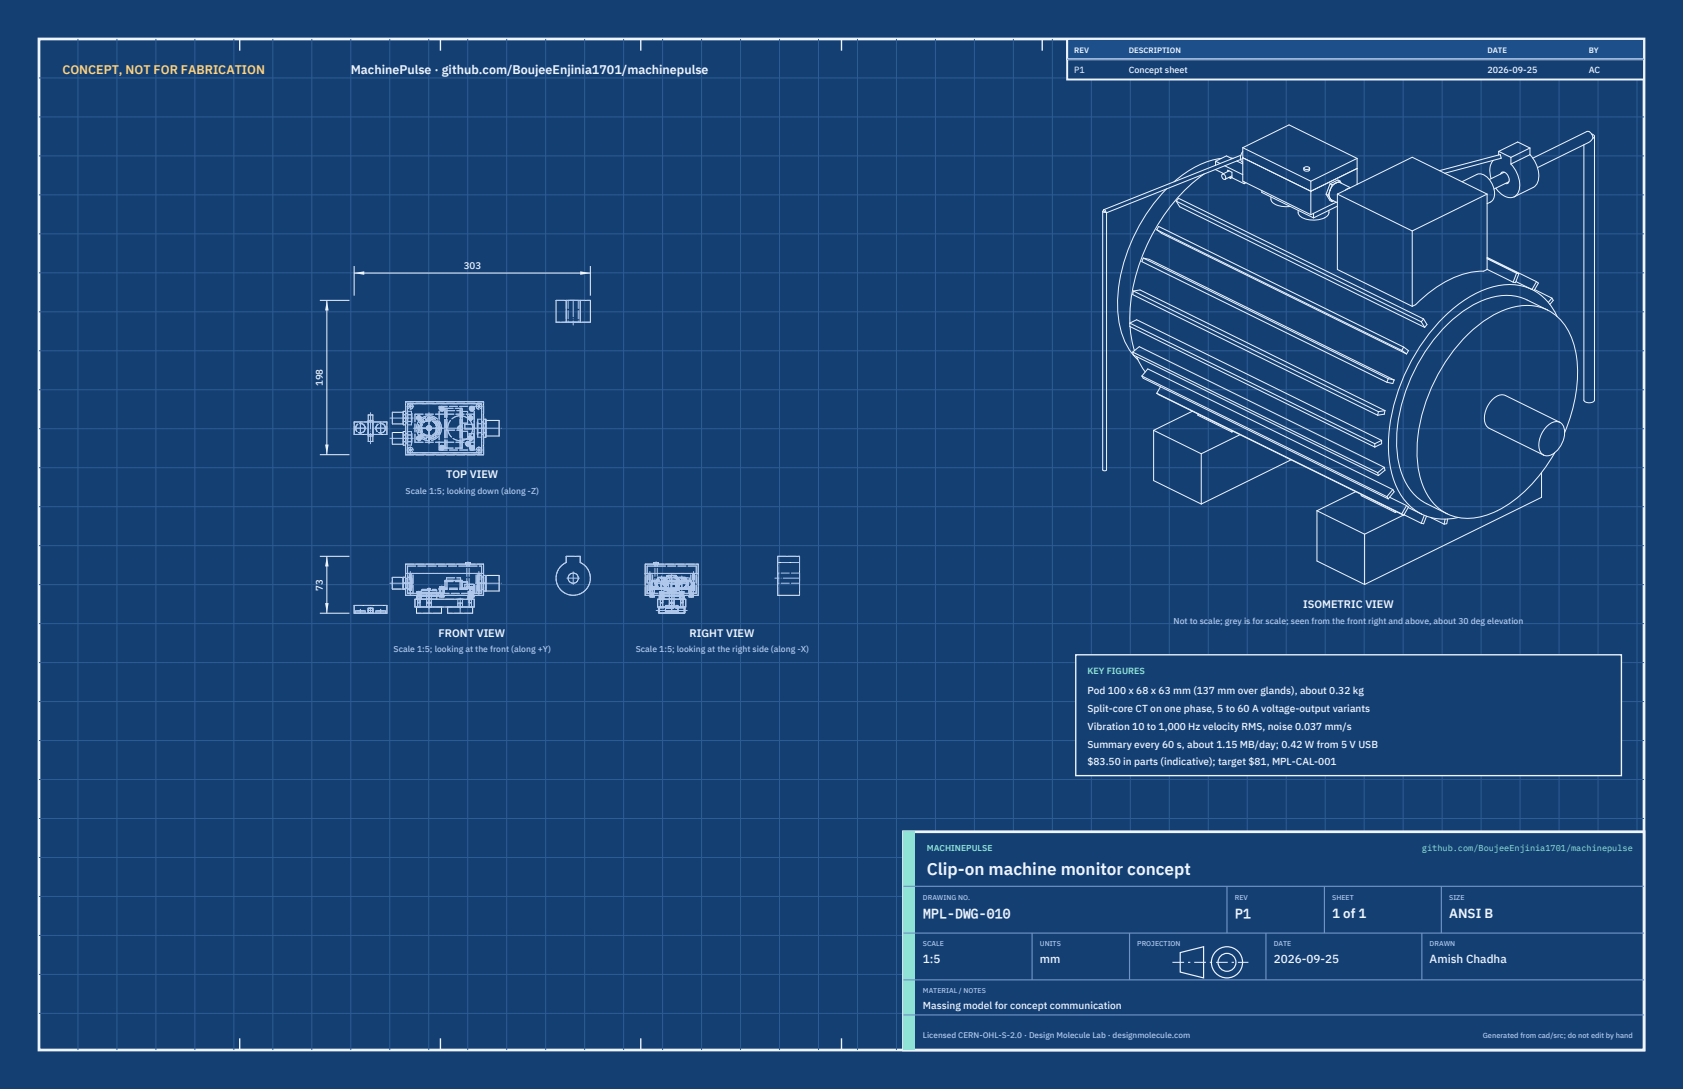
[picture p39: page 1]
CONCEPT, NOT FOR FABRICATION; MachinePulse · github.com/BoujeeEnjinia1701/machinepulse; FRONT VIEW; TOP VIEW; RIGHT VIEW; ISOMETRIC VIEW; REV; DESCRIPTION; DATE; Concept sheet; MACHINEPULSE; github.com/BoujeeEnjinia1701/machinepulse; DRAWING NO. MPL-DWG-010; REV P1; SHEET 1 of 1; SIZE ANSI B; SCALE 1:5; UNITS mm; PROJECTION; DRAWN Amish Chadha; Licensed CERN-OHL-S-2.0 · Design Molecule Lab · designmolecule.com; Generated from cad/src; do not edit by hand

Scale 1:5; looking down (along -Z)

Not to scale; grey is for scale; seen from the front right and above, about 30 deg elevation

Scale 1:5; looking at the front (along +Y)

Scale 1:5; looking at the right side (along -X)

KEY FIGURES
Pod 100 x 68 x 63 mm (137 mm over glands), about 0.32 kg
Split-core CT on one phase, 5 to 60 A voltage-output variants
Vibration 10 to 1,000 Hz velocity RMS, noise 0.037 mm/s
Summary every 60 s, about 1.15 MB/day; 0.42 W from 5 V USB
$83.50 in parts (indicative); target $81, MPL-CAL-001

Clip-on machine monitor concept

MATERIAL / NOTES
Massing model for concept communication

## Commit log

2026-09-25 Initial scaffold: standard open hardware layout, CERN-OHL-S v2 + MIT licenses
    Claude-Session: https://claude.ai/code/session_01XuhhSU4W6fYhgCfURbrkut
    [bom.csv]
2026-09-25 Populate to TRL 2: problem, requirements, precis, concept media, BOM and README use cases
    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
    [bom.csv]
2026-09-26 Advance to TRL 3: DDR-001, CAL-001 sizing, parametric model with STEP/STL, GA drawing, priced BOM; TRL 4 on hold
    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
    [bom.csv, machinepulse-assembly.step, machinepulse-assembly.stl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]
2026-09-26 Accept all recommendations (DDR-002), switch footer to designmolecule.com, add README write-up with new inspiration point
    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
    [bom.csv, machinepulse-assembly.step, machinepulse-pod.step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]
2026-09-27 Product appearance model and photoreal renders
    Adds cad/src/product_model.py (appearance model for renders only, all main
    dimensions from model.py) and Blender renders in media/render-*.png,
    captioned with the project, repository and viewing direction. README leads
    with the product render; trl stays 3.
    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
2026-10-01 Image quality pass: legible exploded views, flow diagrams and drawing sheets
    Kit 1.6.1 image layout: the parts list sits in its own column, number bubbles sit on visible parts and never overlap, small parts get a leader, pictures are cropped to the subject, flow labels keep numbers with their units, and sheet captions and the revision table no longer overprint. Concept images, blueprint and general arrangement sheet regenerated; repo-specific labels moved clear of other text and lines.
2026-10-01 Kit 1.7.0: constructable design, illustrated build plan and design decisions register
    The design is now constructable: every part can be made and fits its neighbours, with each change recorded in a Design for construction decision record (made under Amish's 2026-09-30 instruction; ope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
    FlexHand also credits Dr. Geeti Chadha as a contribut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
    [bom.csv, machinepulse-assembly.step, machinepulse-assembly.stl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]
2026-10-02 Record Amish's approval of the open-decision recommendations
    Amish approved the recommendation on every open decision in the design decisions register ("i approve your recommendations for all 555 open decisions.", 2026-10-02). Each decision is moved to Decisio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
2026-10-03 Carry approved follow-ups into the design and redo photoreal renders
    Amish approved the follow-up actions from the open-decision sign-off ("APPROVED CHANGES, COMPLETE THESE", 2026-10-02), the design-for-construction change tables in ten repos, the last wave's open dec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

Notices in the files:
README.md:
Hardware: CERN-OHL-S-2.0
